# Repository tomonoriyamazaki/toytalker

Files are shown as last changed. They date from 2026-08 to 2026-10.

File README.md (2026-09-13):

# ToyTalker

子供向け音声AIおもちゃ。話しかけると、好きなキャラクターの声で返事をしてくれる。

## 特徴

- **応答約2秒**: STT→LLM→TTSを全区間ストリーミングでつなぎ、最初の音声チャンクが生成され次第再生を開始。サーバーレス（AWS Lambda）構成のまま体感レイテンシを最小化
- **相槌**: メインの応答を生成している間に「そうだね〜」などの短い繋ぎ応答を先に返し、会話のテンポを保つ
- **ボイス・キャラクター切替**: TTSプロバイダーをプラガブルに切替可能（OpenAI / Google / Gemini / ElevenLabs / Cartesia / FishAudio / ずんだもん / 自前クローンボイス）。キャラクターの人格プロンプトもDBで管理
- **スタンドアロン動作**: ESP32-S3搭載の専用基板、おもちゃ単体でWiFi経由でAWSと直接通信（設定ではスマホが必要）

## しくみ
https://github.com/user-attachments/assets/177e0598-6c0a-4d14-9477-36d719003d13

```
[スマホアプリ / ESP32] ── 音声 ──> Soniox STT（直接WebSocket接続）
        │                              │ テキスト
        │                              v
        │<── 音声ストリーム ── Lambda（LLM → TTS ストリーミング）
        │<── 繋ぎ応答 ─────── Lambda（相槌）
```

- STTはLambdaを経由せず、一時キーを使ってクライアントからSonioxへ直接接続（ボトルネック回避）
- LLM→TTSは直列ストリーミングで、生成しながら順次音声化・再生

## デバイスの変遷

| 世代 | 構成 | 状態 |
|---|---|---|
| v1 | Raspberry Pi | 検証完了 |
| v2 | ブレッドボード | 検証完了 |
| v3 | ESP32-S3スタンドアロン（専用PCB） | 開発中 |

## 参加プログラム

- SS Bootcamp 3rd #2025
- TiB FAB makers challenge 2025
- SS Bootcamp 4th #2026

## ドキュメント

- [開発のあゆみ（初期からの検討・試行錯誤の記録）](docs/history.md)
- [マイコン（ESP32）実装](docs/mcu.md)
- [スマホアプリ実装](app/README.md)
- [自前クローンボイス（RTX 5090 / Qwen3-TTS）のバッチ推論](docs/qwen3-tts-batch-engine-2026-09-12.md)
- [原価と課金の考え方](docs/pricing-and-cost-model.md)
- [製品化の認証チェックリスト（STマーク・技適・PSE）](docs/certification-checklist.md)

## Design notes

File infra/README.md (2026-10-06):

# ToyTalker infra（AWS CDK / TypeScript）

ToyTalkerのAWS資源（Lambda 8本・Function URL 7本・DynamoDB 8テーブル・S3・SNS・温めルール・月次Scheduler）を1スタック `ToyTalker-<stage>` で管理する。決定事項と進め方は [docs/multi-account-iac-plan.md](../docs/multi-account-iac-plan.md)。

## 構成

| ファイル | 役割 |
|---|---|
| `bin/toytalker.ts` | 入口。`--context stage=<rnd\|stg\|prod\|prod-dg>` で環境を選び、資格情報のアカウントが一致するか確認し、SSMに秘密が登録済みか確かめてスタックを作る |
| `config/stages.ts` | 環境ごとの秘密でない設定（アカウントID・リージョン・通知先・ZakiCorp URL・S3バケット名・アーキテクチャ） |
| `lib/secrets.ts` | SSM Parameter Store（SecureString）の名前一覧と読み出し。名前は全環境共通 `/toytalker/<key>` |
| `lib/toytalker-stack.ts` | 資源定義。Lambdaは `backend/<dir>/index.mjs` をesbuildでまとめる（旧deploy.shと同じ指定。deploy.shは2026-09-16に削除） |
| `scripts/` | 初回移行用（下記） |

## 使い方

```bash
cd infra
npm ci
bash scripts/install-lambda-deps.sh     # 各Lambdaディレクトリのnpm依存（初回・clone直後）
npx cdk synth  --context stage=rnd      # テンプレート生成（cdk.out/）
npx cdk diff   --context stage=rnd      # 本番との差分。Replace が1つも無いことを確認してから deploy
npx cdk deploy --context stage=rnd
```

別アカウントへ出すときは `AWS_PROFILE=<profile>` か `--profile <profile>` を付ける。設定のアカウントIDと資格情報が違えば起動時に止まる。

## 秘密（SSM）

- 必須: `lib/secrets.ts` の `REQUIRED_SECRETS`（OpenAI・Anthropic・Google・ElevenLabs・FishAudio・Sakura・Cartesia・ZakiCorp API/Edge・Serper・Soniox）
- 任意: OpenAI/Anthropicの管理キー（月次レポートが各社の請求を取るときだけ）
- 1件入れる: `printf '%s' "$VALUE" | npx tsx scripts/put-secret.ts <stage> OPENAI_API_KEY`
- Lambdaは実行時にSSMから読み、メモリに保持する（`backend/shared/secrets.mjs`）。環境変数には鍵を置かず、関数ごとの対象名だけを `SECRET_PARAMS` で渡す。どの関数がどの鍵を読めるかは `lib/toytalker-stack.ts` の `secrets`
- 鍵を入れ替えるときはSSMを変えるだけ。稼働中のLambdaは5分を過ぎた次の呼び出しで取り直す（deploy不要）
- Lambdaに鍵を新しく使わせるとき: `lib/secrets.ts` に名前を足し、その関数の `secrets` に加え、コードでは `secret("名前")` で読む
- 環境変数方式の環境を移すときだけ2段階でdeployする（コードと設定の更新が別々に行われ、その間に鍵が読めなくなるのを避ける）: `npx cdk deploy --context stage=<stage> --context keepEnvSecrets=true` → ログの `[secrets] loaded n/n from SSM` と動作を確認 → フラグ無しで `npx cdk deploy`。新しく作る環境は最初からフラグ無し

## RnDの既存資源をimportで引き取る手順

CloudFormationはimport操作中に新しい資源を作れないので、2段階で行う。

```bash
# 0. 事前準備（各1回）
npx cdk bootstrap aws://342082316736/ap-northeast-1
npx tsx scripts/migrate-secrets-from-lambda.ts rnd   # 2026-10-06に削除済み（Lambda環境変数からSSMへ写すスクリプト。移行は完了）

# 1. import段階: ロール・ポリシー・Lambda Permissionを含まないテンプレートで既存資源を引き取る
npx cdk synth --context stage=rnd --context importPhase=true
npx tsx scripts/make-import-mapping.ts rnd            # import/rnd.generated.json（論理ID→既存資源）
npx cdk import --context stage=rnd --context importPhase=true --resource-mapping import/rnd.generated.json ToyTalker-rnd

# 2. 通常デプロイ: CDK管理の最小権限ロールへ差し替え、Permission・ポリシーを追加、Node 24へ統一
npx cdk diff   --context stage=rnd                     # Replace が無いことを確認
npx cdk deploy --context stage=rnd
```

2段階目のあと、既存のロール `toytalk-lambda-role-dev` と旧Sid（`FunctionURLAllowPublicAccess` 等）は使われなくなるが残る。動作確認後に手で消す。

## マスターデータ

```bash
npx tsx scripts/export-master-data.ts rnd                 # master-data/rnd/*.json（Git対象外）
npx tsx scripts/import-master-data.ts stg --from=rnd --yes
```

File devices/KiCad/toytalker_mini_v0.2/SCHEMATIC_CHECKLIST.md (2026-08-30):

# v0.2 回路図編集チェックリスト(最終版 2026-08-16)

> **このファイルの役割: 「何をやったか」。** Phase 1(回路図)の課題→解決の対応表と作業ログ。**現在の値・ネットの正は PARTS_LIST.md** / GPIOは PINMAP.md

PINMAP.md / PARTS_AND_POWER.md と対応。上から順にやると迷いにくい構成。
編集対象: `toytalker_mini_v0.2.kicad_sch`(v0.1のコピー。バックアップは `toytalker_mini_v0.2_bk/`)

## なぜやるのか — v0.2 課題と解決の全対応表

### A. 音・通信の品質(v0.2の発端)

| # | 課題(v0.1で起きたこと) | 原因 | v0.2の解決 | フェーズ |
|---|---|---|---|---|
| 1 | **会話が途切れる。モジュールを押すと直る**(全個体で再現、[STATS]実測: 途切れ時underruns=6) | ESP32直下のRFグラウンド不足(GNDパッド接続がスポーク1本、直下ビア0個) | GNDソリッド接続+ビアファーム(0.3mm×9〜16)。合格ライン=押さえずにunderruns 0〜1 | **Phase 2(レイアウト)** |
| 2 | アンテナが基板からはみ出し(強度・見た目) | v0.1の設計 | 基板内蔵アンテナ+全層キープアウト(5.5cm版で実績あり) | Phase 2 |
| 3 | WiFiピーク時に電源が窮屈(潜在リスク: 電圧垂れ→音歪み・ブラウンアウト) | LDO 600mAにESP32(WiFiピーク〜500mA)とアンプが同居 | **アンプVDDをV_SYS直結**(データシート裏取り済: VIH=1.3V固定/SD内部100kプルダウン/電源範囲2.5-5.5V) | Phase 1 |

### B. 電源まわりの安全・正しさ

| # | 課題 | 原因 | 解決 | フェーズ |
|---|---|---|---|---|
| 4 | スイッチに定格の50倍の電流(SSAJ110100=10mA定格に実力500mA) | S1が電源経路に直列 | **EN方式化**: S1はAP2112KのENピンへの指示係に(common→PWR_EN、両端→V_SYS/GND、+R9プルダウン)。信号スイッチ化で定格問題消滅 | Phase 1 |
| 5 | 電池コンタクトがハウジングに入りきらない→**金属露出同士で火花(電池短絡、PCM保護頼み)** | 電池リード被覆φ0.93〜1.0(実測)がSHコンタクト上限0.8mmを超過=スペック外圧着。スキル問題ではなかった | **J2をZH化**: S2B-ZR-SM4A-TF + SZH-002T-P0.5(被覆φ1.1まで対応)でスペック内カシメに。工具は手持ちSN-03BM対応 | Phase 1 |
| 6 | 挿し間違いで焼損の可能性(電池⇔スピーカー) | (潜在リスク) | **ポカヨケ**: 電池ZH≠スピーカーMX1.25≠(旧SH)。規格が違い物理的に誤挿入不可 | Phase 1 |

### C. 機能追加

| # | 課題 | 解決 | フェーズ |
|---|---|---|---|
| 7 | **バージイン不可**(再生中に話しかけられない) | I2S分離: マイク=I2S0(GPIO4/5/9)、アンプ=I2S1(GPIO10/11/12)。同時動作の土台 | Phase 1 |
| 8 | 電池残量が分からない | VBAT分圧 R10/R11(470k×2)+C10(0.1µF)→GPIO1(ADC1_CH0、WiFi動作中も測定可) | Phase 1 |
| 9 | 充電中/完了が分からない | BQ25185 STAT1→GPIO13、STAT2→GPIO14(オープンドレインのためR12/R13=100kプルアップ必須) | Phase 1 |
| 16 | 充電時の電池温度保護がない(v0.1はTS機能を固定抵抗で無効化)+本体温度が見えない | **D4**: TS/MRにNTC(TH1)直結でBQのハードウェア充電保護を有効化 / **D5**: 別NTC(TH2)+分圧→GPIO2でファームから温度読取(2026-08-19追加、部品代+約¥10) | Phase 1 |

### D. 組立性・使い勝手

| # | 課題 | 解決 | フェーズ |
|---|---|---|---|
| 10 | スピーカーの付属プラグ(MX1.25)を切ってSHを付け直す無駄工程 | SP1をMX1.25化(HC-1.25-2PWT)→**無加工で挿すだけ**。量産RFQでもMX指定が標準 | Phase 1 |
| 11 | 電源スイッチのノブが極小で筐体連携できない | MSK12C02G15-B(ノブかさ上げ1.5mm、側面操作、蓋側からも対応可)。基板縁に配置 | Phase 1+2 |
| 12 | LEDが眩しい | R8を47Ω→**470Ω**(確定。暗すぎたら手交換/PWM) | Phase 1 |
| 13 | 筐体高さ制約: 内寸9mm=電池3+クッション1+基板1+**部品4mm** | 全選定部品が4mm以下(ZH=3.7/MX=3.57/SW≈3.0)。PH(5.5mm)はこの制約で不採用 | 選定済み |

### E. 設計の衛生(将来の事故防止)

| # | 課題 | 解決 | フェーズ |
|---|---|---|---|
| 14 | GPIO3(JTAGストラップピン)を使用中 | マイクWSをGPIO5へ移動、GPIO3を未接続に | Phase 1 |
| 15 | ネット名の誤記・紛らわしさ(BootボタンがGPIO27表記、「EN」が2つある) | GPIO0_BOOT改名、ESP_EN(ESP32リセット)/PWR_EN(LDO制御)分離、V_SYS_SW廃止 | Phase 1 |

**Phase 1(このチェックリスト)で解決: #3〜12, 14, 15 / Phase 2(レイアウト)で解決: #1, 2, 11の配置**

## 事前準備

- [x] 新部品3種のシンボル+フットプリントを入手
  - S1: **MSK12C02G15-B** (C22435661) — JLCPCB部品ページに EasyEDA Footprint/Symbol あり。位置決めペグ穴Φ0.8×2を含むこと
  - SP1: **HCTL HC-1.25-2PWT** (C2845379) — フットプリントは**HCTL自身のEasyEDAデータ**をKiCad変換して使う(互換品は本家Molexと半田タブ位置が違う場合があるため本家フットプリント流用は不可)
  - J2: **JST ZH S2B-ZR-SM4A-TF** (C265329) — KiCad標準ライブラリ `Connector_JST` にZHあり(フットプリント要確認)。ケーブル側部材の購入: ハウジング**ZHR-2**+コンタクト**SZH-002T-P0.5**(太線用、電池リードφ1.0対応)

## A. ネット名の整理(先にやると後工程が読みやすい)

- [x] A1: S3(Bootボタン)のネット `GPIO27` → **`GPIO0_BOOT`** に改名(実体はGPIO0、v0.1の誤記修正)
- [x] A2: U3のENピンのネット `Net-(U3-EN)` → **`ESP_EN`**(ESP32のリセット。R6/C7はそのまま)
- [x] A3: 新ネット **`PWR_EN`** を作る(B工程で使用。ESP_ENとの混同注意 — 別物!)

## B. 電源セクション(EN方式化 + アンプV_SYS直結)

- [x] B1: S1を電源経路(V_SYS→V_SYS_SW)から切り離す
- [x] B2: U2(AP2112K)の**VINをV_SYSに直結**。C4(22uF)は部品そのまま、ネットをV_SYSに(VIN直近デカップリングとして残す)→ これで `V_SYS_SW` ネットは消滅
- [x] B3: U2の**ENをVINから切り離し、`PWR_EN`ネットに**接続
- [x] B4: S1(新部品)の配線: **common→PWR_EN、片側→V_SYS、反対側→GND**(ON=EN High / OFF=EN Low)
- [x] B5: **R9(100kΩ・新規)** をPWR_EN–GND間に(スイッチ接触不良時にOFF側へ倒す保険)
- [x] B6: U4(MAX98357)の**VDDを+3V3→V_SYSに**。C9(10uF)もV_SYS側(アンプVDD直近)へ
  - ※AMP_SDへの外付けプルダウンは**不要**(SD_MODEに内部100kΩ内蔵、確認済み)

## C. I2S分離 + GPIO変更(U3まわり)

- [x] C1: MK1(マイク)WS: GPIO3 → **GPIO5**
- [x] C2: U4(アンプ)BCLK: GPIO4 → **GPIO10**
- [x] C3: U4 LRC: GPIO3 → **GPIO11**
- [x] C4: U4 DIN: GPIO5 → **GPIO12**
- [x] C5: **GPIO3は未接続に**(JTAGストラップピン解放が目的)
- [x] C6: 変更なし確認: MIC_BCLK=GPIO4 / MIC_DATA=GPIO9 / AMP_SD=GPIO6 / LED=GPIO8 / BUTTON=GPIO7

## D. 新規回路

- [x] D1: 電池残量分圧: **VBAT → R10(470k) → [GPIO1] → R11(470k) → GND**、**C10(0.1µF)** をGPIO1–GND間(ADC1_CH0、WiFi中も測定可)
- [x] D2: 充電ステータス: U1の**STAT1→GPIO13、STAT2→GPIO14**、各々 **R12/R13(100k)** で+3V3へプルアップ(STATはオープンドレインのため必須)
- [x] D3: LED減光: **R8を47Ω→470Ω**(現状27mA→約2.8mA=1/10。眩しすぎてテープで隠している現状から判断。暗すぎたら0603手交換で戻せる。ファームのLEDC PWMでの微調整も可=ハードPWMなのでCPU負荷ほぼゼロ)
- [x] D4: 充電温度保護の有効化: **R5(固定10kΩ)を撤去し、TH1=NCP15XH103F03RC(C77131)をTS/MR–GND間に**。補正抵抗不要(β25/85=3434K≒TI要求3435K、BQ25185データシート§7.3.9で裏取り済み)。高温/低温時にBQがハードウェアだけで充電停止
- [x] D5: 本体温度の可視化: **+3V3 → R14(10kΩ) → [GPIO2] → TH2(NCP15XH103F03RC) → GND**、**C11(0.1µF)** をGPIO2–GND間(ADC1_CH1)。ファームで温度計算しアプリ/[STATS]へ
  - ※TS共用は不可(TSはBQ内部バイアスの私有ノード。モードで電圧が変わり、外部分圧は保護閾値を狂わせる)

## E. 部品差し替え

- [x] E1: S1: SSAJ110100 → **MSK12C02G15-B**(掛かり不足時はG20-Bへ、同一フットプリント)
- [x] E2: SP1: JST SH → **HC-1.25-2PWT**(スピーカー付属のMX1.25プラグが無加工で挿さる)
- [x] E3: J2: JST SH → **JST ZH**(S2B-ZR-SM4A-TF)。電池リード被覆φ0.93〜1.0がSHのスペック外(上限0.8)だったため。ZHのSZH-002Tコンタクト(φ1.1まで)で直接カシメがスペック内に

## F. 検証

- [x] F1: ERC実行 → **ゼロ**に(機械チェック: `kicad-cli sch erc toytalker_mini_v0.2.kicad_sch`)
- [x] F2: PINMAP.md の割当表と突き合わせ(GPIO 1,2,4,5,6,7,8,9,10,11,12,13,14 / 0=BOOT / 3=未接続) — ネットリストで機械検証済み 2026-08-29
- [ ] F3: 完了したらPhase 2(レイアウト)へ。レイアウト側の申し送り: S1は**左辺**配置(ノブ外向き・スマホ式)、J2は**下辺**(28.0,47.0)で口が下向き、その正面の下辺に電池ケーブル用**切り欠き(x25〜31、幅6mm×深さ1.8mm)**。電池は裏返し搭載で赤黒線は右下から出す(RFQ要件)、U3は**90°回転してアンテナを右辺内側へ**(モジュール実寸15.4×20.5mm=アンテナ部5.05mm含む長方形。§10.1 Fig10-1で確認済み。上辺のままだと基板内に収めた時スピーカー円と衝突)、アンテナ帯は全層キープアウト+バッテリーは右帯を避ける、U3直下ビアファーム、**TH1/TH2は基板裏面(電池側)に配置し、TH2はESP32・アンプの自己発熱から離す**

## 参考: 新規部品まとめ(発注BOM追加分)

→ **PARTS_LIST.md に移管**(2026-08-29)。

※J2のケーブル側部材(自分で購入): ハウジングZHR-2、コンタクトSZH-002T-P0.5(太線用)。工具は手持ちSN-03BM対応

変更しない部品・値: R8以外の既存R/C、BQ25185周辺(R3/R4 ※R5は削除しTH1へ)、USB-C周辺、ESP_EN周辺(R6/C7)

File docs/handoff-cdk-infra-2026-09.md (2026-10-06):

# 引き継ぎ: CDK化とRnDの取り込み（2026-09-16作業分、2026-10-06更新）

新しいセッションで複数アカウント展開の続きを始めるための入口。決定の根拠と経過は [複数アカウント計画](multi-account-iac-plan.md)、コードと手順は [infra/README.md](../infra/README.md)。この文書は「今どうなっていて、次に何をするか」だけを持つ。

## 今の状態

- RnDアカウント（342082316736）のToyTalker資源36個は、CloudFormationスタック **`ToyTalker-rnd`** の管理下。ドリフトなし（2026-09-16確認）。
- **Lambdaの反映は `cd infra && npx cdk diff --context stage=rnd` → `npx cdk deploy --context stage=rnd`。** `deploy.sh` / `setup.sh` は削除済み。
- APIキー11件の正本は **SSM Parameter Store `/toytalker/<key>`**（AWS管理キーで暗号化、無料）。**Lambdaが実行時に読んでメモリに保持する**（`backend/shared/secrets.mjs`。2026-10-06に2段階deployで切替、環境変数から鍵を外した。アプリ・ESP32で実機確認済み）。環境変数にはどの鍵を読むかの名前 `SECRET_PARAMS` だけがある。鍵を替えるときはSSMを変えるだけ（5分以内に反映）。手順は infra/README の「秘密」節。
- IAMロールはCDKが関数ごとに作った最小権限のもの（`ToyTalker-rnd-<部品ID>ServiceRole…`）。旧ロールと旧Permissionは削除済み。**`toytalk-lambda-role-dev` だけはv1の旧Lambda 2本が使っているので残している。**
- 動作確認済み: アプリ（会話・読み上げ・設定保存・クローンボイス登録）、ESP32（会話・OTA 0.7.1→0.7.2）。いずれも新ロールで成功。
- Lambda 8本のバンドルは、CDK化前に本番に入っていたコードとバイト単位で一致することを確認した上で引き取った。
- Node 22だった3本はNode 24に統一。ESP32用メインのメモリは2024→2048MB（元の値はタイプミス）。

## 決めたこと（2026-09-16）

- 秘密はSecrets Managerでなく **SSM SecureString**（1件$0.40/月が不要。ローテーション・アカウント間共有を使わないため）。
- 鍵はAWS管理キー。**CMKは本番アカウントで入れる**（SSMとLambda環境変数の両方。DG向け本番で他の人が入る時点で効く。1鍵約$1/月）。RnD/STGはAWS管理キーのまま。
- **秘密の実行時取得へ切り替える** → 2026-10-06に完了。詳細は計画メモの同名の節。
- **命名は環境名を付けて統一する**（案: `toytalker-<env>-chat-app` など。スタック名・部品ID・固定名の3層を一度に変える）。RnDの改名はCloudFront固定ドメインの後、STGは最初から新名。詳細は計画メモの「命名の見直し」。
- ファーム配布バケット `toytalker-firmware` はCDKの管理外（`fromBucketName` で参照のみ）。名前は `stages.ts` の `firmwareBucketName`。

## 次にやること（順序の案）

1. ~~秘密の実行時取得~~（2026-10-06完了）
2. **命名の決定**（計画メモの案を確定。テーブルのキー名を変えるならここで）
3. **STGアカウント作成 → `cdk bootstrap` → SSM投入 → `cdk deploy` → マスターデータ投入**（`stages.ts` の `account` を埋める。投入スクリプトは infra/scripts）
4. **CloudFront固定ドメイン**（`api-stg.zakicorp.com` 等。アプリとESP32の接続先切替）
5. RnDの改名（4の後）→ **自分用本番**（CMK込み）→ **DG向け本番**。本番が2つになったらGitHub Actions + OIDC

判断待ち・別機会:

- v1の残骸を消すか: `toytalk-lambda-role-dev`、`toytalk-openai-api-dev`、`toytalk-api-raspi`、API Gateway `toytalk-chat-apigateway-dev`、孤立ロググループ `/aws/lambda/toytalk-stream-handler-for-esp32-lambda`
- Windows機で: `infra/` の動作確認は済（2026-09-29、Node v22.19.0・Git Bash。`npm ci`、`install-lambda-deps.sh`、型チェック、`cdk diff --context stage=rnd` が差分なし。deployは未実行）。`supervisor.py` の `ZAKICORP_TTS_URL` 同期停止はコード修正済みで、このPCの `.local/tts-service/` への反映が未実施
- `toytalker-firmware` を1資源だけ `cdk import` で引き取るか
- Soniox鍵発行Lambda（128MB）はコールドスタート時のSSM取得に約0.9秒かかる（他は1〜2GBで約0.2秒）。温めで普段は起きないが、気になるなら256MBへ

## 落とし穴

- **`cdk synth`/`diff`/`deploy` にはAWS資格情報が要る**（SSMの登録の有無を確かめるため。値は読まない）。起動時にアカウントIDが `stages.ts` と一致しないと止まる。
- **`NodejsFunction` は使っていない。** `npx esbuild` をリポジトリ直下で起動してインストール確認待ちで止まるため、esbuildのAPIを直接呼ぶ `bundleLambda` を使っている。
- 各Lambdaディレクトリの `node_modules` が無いとバンドルできない。clone直後は `bash infra/scripts/install-lambda-deps.sh`。
- 名前を固定した資源（Lambda・テーブル・S3）の名前や部品IDを変えると作り直しになる。`cdk diff` の requires replacement を必ず見る。Lambdaの作り直しはFunction URLのホスト名が変わり、アプリとESP32が壊れる。
- 新しいCloudFormation資源を既存スタックに `cdk import` するときは、import操作にそれ以外の変更を含められない（`--context importPhase=true` の仕組みは infra/README）。

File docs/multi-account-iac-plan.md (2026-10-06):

# 複数アカウント展開とIaC化の計画（2026-09-15決定）

今のAWSアカウントをRnDにし、STG → 自分用本番 → DG（西川さん）向け本番へ展開するための計画。道具はAWS CDK（TypeScript）。着手したら本文の「進め方」を進捗に合わせて上書きし、決定の根拠はこの文書に残す。

## 決定事項

| 項目 | 決定 | 根拠 |
|---|---|---|
| IaCの道具 | AWS CDK（TypeScript） | Lambda 8本がNode.js ESM + esbuildで、`NodejsFunction` がdeploy.shを丸ごと置き換える。ストリーミングFunction URLは `invokeMode: RESPONSE_STREAM` の1行。アプリもTS系で言語が増えない |
| CloudFormation | CDKの裏で使い続ける | CDKはTSをCloudFormationテンプレートに変換して流す。YAMLは書かない。マネコンのCloudFormation画面はスタックの閲覧・ロールバック用に使う |
| 今のアカウント | RnDとして残し、ToyTalkerの資源はCDK管理に引き取る（2026-09-15に変更） | 当初は手作業のまま残す予定だったが、RnDを見ながらCDKを書き、当てて差分が消えるまで直せる方が確実。テーブルにはデータが入っているので作り直さず `cdk import` で引き取る。ToyTalker以外の資源はCDKの管理外のまま |
| 環境 | RnD（現行）→ STG → 自分用本番 → DG向け本番 | Organizationsで分け、ログインはIAM Identity Center。アカウントごとのアクセスキーは作らない |
| 資源の名前 | テーブル名・Lambda名は `toytalker-*` の固定名を全環境で維持。S3バケットだけ環境名を付ける | アカウントが別なら同じ名前でぶつからない。RnDの既存資源をimportで引き取るには名前の一致が必要。S3は全世界で一意なので `toytalker-tts-speakers-<stage>` |
| 環境ごとの設定 | `infra/config/stages.ts` の1ファイルに環境ごとの塊を並べ、`cdk deploy --context stage=<env>` で選ぶ | アカウントID・リージョン・APIの固定ドメイン・通知メール・ZakiCorp URL・メモリなど。秘密ではないのでGitに入れる |
| 秘密の値 | アカウントごとのSSM Parameter Store（SecureString）。名前は全環境で同じ（例 `/toytalker/openai-api-key`）、中身だけ違う | CDKは名前しか持たず、秘密がファイルに載らない。中身は初回にアカウントごとに手で入れる（投入スクリプト可）。CDKがデプロイ時に読んでLambda環境変数に焼くので、鍵を入れ替えたら `cdk deploy` し直す |
| CDKが決める値 | Function URLのホスト名など、生成結果の値はファイルに書かない | CDKコード内で「このLambdaのURLをあのLambdaの環境変数へ」と配線する。人が見るのはデプロイ後の出力 |
| デプロイ経路 | 当面ローカルから `cdk deploy --profile <env>` | GitHub Actions + OIDCは本番が2つになってから |
| Lambda起動の高速化 | 今はやらない | 温め設計が効いている（下記） |
| Terraform | 見送り | AWS単独ならCDKの方が学ぶことが少ない。Cloudflare側（DNS・WAF・Tunnel）もコード化したくなったら再検討 |

## 現状の棚卸し（2026-09-15、RnDアカウント）

CDKで再現する対象。

- Lambda 8本（Node 22と24が混在、x86_64）。メイン2本は2048MB、相槌1024MB、デバイス設定256MB
- Lambda Function URL 7本（RESPONSE_STREAM 4本: App用メイン・ESP32用メイン・App用相槌・読み上げ。BUFFERED 3本: ESP32用相槌・Soniox鍵発行・デバイス設定）。API Gateway `toytalk-chat-apigateway-dev` はv1（Raspberry Pi）時代の旧Lambda向けで現行8本とは無関係。CDKの対象外
- DynamoDB 8テーブル、S3 `toytalker-tts-speakers`、SNS `toytalker-ops-monthly`、EventBridge Scheduler `toytalker-ops-monthly`
- EventBridgeルール `toytalker-lambda-warmer`（5分ごと、メイン2本・相槌2本・Soniox鍵発行の5本へ `{"warmup":true}`）
- 実行ロールは2つ。7本が共有する `toytalk-lambda-role-dev`（DynamoDB/S3/Lambda FullAccess等の広い管理ポリシー）と、月次レポート用 `toytalker-ops-monthly-role`（最小権限のインライン）。環境変数はLambda全体で22種類、APIキー類がここに直接入っている
- 温めルールは `AWS::Lambda::Permission`（Sid `toytalker-warmer`）で5本に付いている。Function URLの公開許可は新しい4本には `InvokeFunctionUrl` と `InvokeFunction`（`InvokedViaFunctionUrl` 条件）の2つ、古い3本には前者だけ
- Function URLのホスト名がアプリとESP32ファームにハードコードされている
- ZakiCorp TTSの監視タスク（`tools/tts-service/supervisor.py`）がLambda 6本の `ZAKICORP_TTS_URL` を関数名指定で同期している

## 進め方

RnDでCDKを完成させてから、同じコードをSTG・本番にまっさらに出す。RnDへの `cdk deploy` はSTGができるまで本番デプロイと同じ扱いで、毎回 `cdk diff` で置き換え（Replace）が1つも出ないことを確認してから流す。コードは [infra/](../infra/README.md)。

1. **済（2026-09-16）RnDの現状をAWS CLIで読み出した。** 上の棚卸しに反映。CloudFormationで全種類がimport可能なことも `get-template-summary` で確認した（Lambda::Url・Events::Rule・Scheduler::Schedule・SNS::Subscription・Logs::LogGroup を含む）。
2. **済 CDKの骨組み。** `infra/` に1スタック `ToyTalker-<stage>`。Lambdaはesbuild APIで直接バンドルし、8本とも本番に入っているコードとバイト単位で一致することを確認した（`aws lambda get-function` で取得して比較）。温めルール・自分へのping・Scheduler・SNS購読を含む。ランタイムはNode 24で統一（`LAMBDA_RUNTIME` 1か所）。
   - `NodejsFunction` は使わない。`npx esbuild` をリポジトリ直下で起動してインストール確認待ちで止まるため（esbuildは `infra/` にしか無い）。
3. **済（コードのみ、SSMへの投入は未実行）環境設定ファイルとSSMの名前。** `infra/config/stages.ts` と `infra/lib/secrets.ts`。RnDのLambda環境変数からSSMへ写すスクリプトは `infra/scripts/migrate-secrets-from-lambda.ts`。（`--context secretsSource=lambda` は2026-10-06の実行時取得への切替で廃止）。
4. **済（2026-09-16 05:00 JST）RnDの既存資源を `cdk import` で引き取った。** 手順は [infra/README.md](../infra/README.md)。`cdk bootstrap` → SSMへ11件投入（`migrate-secrets-from-lambda.ts`）→ `--context importPhase=true` のテンプレート（36資源）で `cdk import`。import前後でLambda 8本の設定・コードハッシュ・環境変数が同一であることを確認した（更新日時だけCloudFormationのタグ付けで変わる）。IAMロールはimportせず、次のdeployでCDK管理の最小権限ロール（関数ごと、使うテーブルだけ）へ差し替えた。
5. **済（同日 05:16 JST）初回 `cdk deploy` でドリフトなし。** Replaceなし。変わったもの: ロール9つ新設と差し替え、Node 22→24（3本）、ESP32用メインのメモリ 2024→2048、Function URL公開許可と温めルールのPermission追加（旧Sidは残る）。deploy直後に実機からの会話1件がDynamoDB・LLM・検索・TTSまで新ロールで成功。ドリフト検出は IN_SYNC。**ここでdeploy.shの役目が終わった。以後RnDへの反映は `cdk deploy --context stage=rnd`。**
   - 同日06:24 JST、ESP32 OTA（main b18c70d）に合わせて2回目のdeploy: Soniox鍵発行Lambdaのタイムアウト3→5、`toytalker-devices` 書き込み、ファーム配布バケット `toytalker-firmware`（手作業で作成、CDKは `fromBucketName` で参照のみ。名前は `stages.ts` の `firmwareBucketName`）の読み取り、環境変数 `FIRMWARE_BUCKET`。デバイス設定Lambdaもmainの版へ。
   - 同日、アプリ（会話・読み上げ・設定保存・クローンボイス登録）とESP32（会話・OTA）の確認後に後片付け: 旧ロール `toytalker-ops-monthly-role` `toytalker-ops-monthly-scheduler-role` と旧Permission（Sid `FunctionURLAllowPublicAccess` `FunctionURLAllowInvokeAction` `toytalker-warmer`）を削除。**`toytalk-lambda-role-dev` は残した**（v1の旧Lambda `toytalk-openai-api-dev` `toytalk-api-raspi` がまだ使っている。API Gateway `toytalk-chat-apigateway-dev` ともども、消すなら別途判断）。
6. **済（スクリプトのみ）マスターデータの投入スクリプト。** `infra/scripts/export-master-data.ts` / `import-master-data.ts`。出力先 `infra/master-data/` はGit対象外（人格プロンプトを含む）。
7. **STGアカウントを作って `cdk bootstrap` → `cdk deploy`。** `stages.ts` の `account` を埋め、SSMに鍵を入れ、マスターデータを投入し、アプリとESP32の接続先をSTGへ向けて実機確認。
8. **エンドポイントの固定名化。** Function URLはアカウントごとにホスト名が変わるので、CloudFrontを前段に置いて `api-stg.zakicorp.com` のような固定名にする（ストリーミングはCloudFront経由でも通る）。アプリは `eas.json` のビルドプロファイルで、ESP32はビルドフラグで接続先を切り替える。現在のハードコード箇所: `app/app/(tabs)/chat.tsx`・`settings.tsx`・`toy.tsx`・`app/components/ReadAloud.tsx`、ESP32は各版の `.ino`。
9. **済（コードのみ、このPCへの反映は未実施）ZakiCorp TTSのURL同期を止める。** 固定URLのときは照合と警告だけにし、書き込みはngrok経路に限った。 公開URLが `https://tts.zakicorp.com` で固定になったので `stages.ts` の値にした。`tools/tts-service/supervisor.py` の同期はimport後に不要になる（CDKがdeployのたびに環境変数を上書きするので、同期を残すと互いに書き合う）。
10. STGで一通り動いたら、同じスタックを自分用本番、DG向け本番の順に出す。
11. 本番が2つになったらGitHub Actions + OIDC（アカウントごとにOIDC用ロール1つ。権限はCDKのロール群を借りるだけ。これもCDKで書く）。

### 決めたこと（実装中に追加）

- リポジトリは公開。`stages.ts` に載るアカウントIDと通知先メールは秘密ではなく、メールは既に `docs/tts-boot-recovery.md` にもある。
- スタックは `terminationProtection: true`、テーブルとS3は `RemovalPolicy.RETAIN`、テーブルは削除保護ON。
- ロググループもCDK管理（保持期間は現状どおり無期限。変えるなら `stages.ts` に足す）。
- `cdk.json` は `versionReporting: false`（`AWS::CDK::Metadata` を出さない。import時に余計な資源を作らないため）。

## 秘密の実行時取得（2026-09-16合意、2026-10-06実装・RnD切替済み）

「CDKがdeploy時にSSMを読み、Lambda環境変数に焼く」方式から、「Lambdaが初期化時にSSMを読み、メモリに保持する」方式へ変えた。実装は `backend/shared/secrets.mjs` と `infra/lib/toytalker-stack.ts` の `secrets`、手順は infra/README の「秘密」節。計画と違えた点: 切替時にコード更新と設定更新の間で鍵が読めなくなるのを避けるため、`--context keepEnvSecrets=true` で環境変数にも残す1段目を挟む2段階deployにした（`secret()` は環境変数へフォールバックする）。以下は合意時の計画。

- 理由: 環境変数はLambdaの設定を読める人に平文で見え、CDKがS3に上げるテンプレートにも入る。実行時取得なら鍵は関数のメモリにしかなく、読めるのはその関数のロールだけ。鍵の差し替えもSSMを変えるだけでdeploy不要になる。
- 速度: 初期化（コールドスタート）に `GetParameters` 1〜2回分（30〜60ms）が足される。2回目以降は保持した値を使うので環境変数と同じ。温めで初期化はほぼ起きない（週1〜5回）ので体感差なし。
- やり方: 共通モジュール1つを8本に入れ、初期化時に10件ずつ並列取得、5分以上経ったら裏で取り直す。CDKは環境変数から鍵を外し、ロールに `ssm:GetParameters` を足す。AWS管理キーの復号はSSM経由で自動的に許可される。AWS公式の Parameters and Secrets Lambda Extension はレイヤー追加とHTTP呼び出しへの書き換えが要るので使わない。
- 時期: STGを作る前。8本のコードに手が入るので実機試験が要る。先にやればSTGは最初から環境変数に鍵の無い状態で立ち上がる。
- 秘密でない設定（`ZAKICORP_TTS_URL`・`CARTESIA_DEFAULT_VOICE_ID`・`SONIOX_MODEL`・`FIRMWARE_BUCKET`・`OPS_SNS_TOPIC_ARN`）は環境変数のまま。

## 命名の見直し（2026-09-16、未決定）

今の名前は `toytalk-`/`toytalker-` が混在し、環境名が無い。計画では「固定名を全環境で維持」としたが、環境名を付ける方向で見直したい（コンソールやログで環境が一目で分かる。S3は既に環境名が必須）。案は接頭辞 `toytalker-<env>-`、envは `rnd` / `stg` / `prd` / `prd-dg`（例: `toytalker-stg-devices`、`toytalker-stg-stream-handler`）。

### 名前の案（2026-09-16）

- 形は `toytalker-<env>-<機能>-<相手>`。環境名を前に置くと一覧が環境ごとに固まり、IAMで `toytalker-stg-*` の前方一致が書ける。
- `-lambda` `-table` のような種類は付けない（コンソールもログの `/aws/lambda/…` も種類を示す）。
- 相手は `app`（スマホ）と `mcu`（ESP32。`devices/mcu/` に合わせ、基板が変わっても持つ名前）。両方から使うものは付けない。

| 今 | 案 | 中身 |
|---|---|---|
| `toytalk-stream-handler-lambda` | `toytalker-<env>-chat-app` | App用メイン（LLM+TTS） |
| `toytalk-api-stream-for-esp32-lambda` | `toytalker-<env>-chat-mcu` | ESP32用メイン |
| `toytalker-backchannel-for-app-lambda` | `toytalker-<env>-backchannel-app` | App用相槌 |
| `toytalker-backchannel-for-esp32-lambda` | `toytalker-<env>-backchannel-mcu` | ESP32用相槌 |
| `toytalk-soniox-stt-lambda` | `toytalker-<env>-stt-token` | Soniox一時キー発行（両方から使う） |
| `toytalker-device-setting-lambda` | `toytalker-<env>-settings-app` | デバイス登録・ボイス設定・コスト（「デバイス設定」より広い） |
| `toytalker-tts-only-lambda` | `toytalker-<env>-read-aloud-app` | 読み上げ。実装（TTSのみ）より機能名 |
| `toytalker-ops-monthly-lambda` | `toytalker-<env>-ops-monthly` | 月次レポート |

テーブルは `toytalker-<env>-devices` のように接頭辞を替えるだけ。S3は `toytalker-<env>-tts-speakers`。ロググループは関数名に追従。

### 名前は3層あり、一度に変える

| 層 | 今 | 決めているもの |
|---|---|---|
| スタック名 | `ToyTalker-rnd` | IAMロール名の先頭、CloudFormationの一覧 |
| 部品ID（CDKコード内の名前） | `StreamHandler`、`DevicesTable` など | ロール名の中身、CloudFormationの論理ID |
| 資源の固定名 | `toytalk-stream-handler-lambda`、`toytalker-devices` など | 実際のLambda名・テーブル名。アプリやコードが参照するのはこれ |

IAMロールはCDKが名前を付けている（例 `ToyTalker-rnd-OpsMonthlyServiceRoleDC20ED87-UWLuVIYTH2C7`）ので、環境の区別はスタック名で既についている。固定名は付けない。

部品IDを変えると、その資源はCloudFormation上で別物になり作り直しになる（テーブルも同じ）。固定名を変える時点で作り直しは避けられないので、スタック名（`toytalker-<env>` に小文字で揃える）・部品ID（`StreamHandler` → `ChatApp` など）・固定名は同時に変え、作り直しを1回で済ませる。

### 名前を変えたときに起きること

CDKで固定名を変えると、その資源は「作り直し（Replace）」になる。`cdk diff` に requires replacement と出る。古い資源は RETAIN にしてあるので消えずに残る。

| 資源 | 影響 |
|---|---|
| IAMロール | CDKが名前を付けるので変える場面がない。作り直しても実害なし |
| Lambda関数名 | **Function URLのホスト名が変わる。** アプリとESP32の接続先を配り直す必要がある。ロググループ名、`supervisor.py` の関数名一覧、月次レポートのログ検索対象も追従 |
| DynamoDBテーブル名 | 新テーブルは空。マスター4テーブルは `export/import-master-data.ts` で移せる。会話ログ・利用量は件数が多い |
| DynamoDBキー名 | テーブル名変更に加えて、データの詰め替えとLambdaコードの書き換えが要る。一番重い。変えるならSTGを作る前に決める |
| S3バケット名 | `aws s3 sync` で写すだけ（34オブジェクト） |
| SNS・温めルール・Scheduler | 影響なし。メール購読は再確認メールが届く |

### 進め方の案

1. **Lambdaコードがテーブル名を環境変数から組み立てるように直す**（例: `TABLE_PREFIX`）。名前はまだ変えない。CDKが環境変数を配るので、名前を知っているのは `stages.ts` だけになる。ここは無リスク。
2. **STGは最初から新しい名前で作る。** まっさらなので追加の手間はない。
3. **RnDは、CloudFrontの固定ドメイン（進め方8）の後に改名する。** 配布済みの実機があるので、Function URLのホスト名が変わっても困らない状態にしてから。接頭辞の統一と環境名の付与は1回で済ませる。

## CDK化のついでに入れるもの

- **arm64**: 料金2割減。速度はネットワーク待ちが支配的なので変わらない。純粋なJSなので書き換え不要、実機確認は要る。
- **AWS SDKのtree-shaking同梱**: 今は `--external:@aws-sdk/*` でランタイム同梱SDKを数千ファイルから読んでいる。使う分だけを1ファイルに同梱すれば初期化が数十ms縮む。tree-shakingとminifyを効かせないと逆に遅くなる。やるなら `backend/package.json` を作って `@aws-sdk/*` を `backend/node_modules` に置き（各Lambdaの `openai` 版違いはそのまま）、`bundleLambda` の `external` を空にして `minify: true`。import直後はやらず、diffが空になってから別コミットで。

## CDKの前提知識（初回作業時の確認用）

- `cdk bootstrap` をアカウント（×リージョン）ごとに1回実行すると、CDK用のロール一式（CloudFormation実行・デプロイ・ファイル公開・参照）とS3バケット1つができる。S3が要るのはCloudFormationがzipの中身を受け取れず「S3のどこにあるか」しか受け付けないため。
- `cdk diff` で変更対象を事前に確認できる。Lambda 1本だけ直して `cdk deploy` しても、コードのハッシュが変わった関数だけ更新される。`--hotswap` はCloudFormationを通さず直接差し替える開発用で、本番では使わない。
- ランタイム版は `lambda.Runtime.NODEJS_24_X` のような定数で指定する。共通定数にしておけばEOL時は1か所の変更で全関数に反映される。

## 調査記録: Lambdaコールドスタート（2026-09-15）

直近7日のCloudWatch Logsを、温めping（アプリログ無し、START/END/REPORTの3行）と実リクエストに分けて集計した。

| 関数 | 呼び出し | コールドスタート | うち実リクエスト | 初期化平均 |
|---|---|---|---|---|
| App用メイン | 2204 | 124 | 1 | 408ms |
| ESP32用メイン | 3346 | 160 | 5（判別しにくいもの11） | 418ms |
| 相槌(ESP32) | 2834 | 105 | 4 | 363ms |

コールドスタートの大半は予備インスタンス温めが意図通り新しいインスタンスを起こしているもので、ユーザーに当たる初期化待ちはほぼゼロ。温めは常時1台と予備1台なので、3人以上の同時利用で3人目からはコールドを踏むが、今の規模では問題になっていない。初期化400msの内訳は推定で `openai` パッケージの読み込みが大半、次にランタイム同梱SDKの読み込み。ユーザーが感じるコールドスタートにはこの他にログに出ないサンドボックス生成の100〜200msが乗り、そこは手が出せない。

却下した高速化案と理由は [先送り項目](deferred-items.md) の「Lambda初期化の短縮」。

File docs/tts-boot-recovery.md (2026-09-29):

# ログオン不要のTTS起動・復旧

## 目的と構成

PC再起動後、人がログオンする前にクローン音声を復旧させる。Windows更新の設定はこの作業では変更しない。

管理対象は既存の `C:\Users\exodj\projects\tts-models\faster-qwen3-tts\api_server.py` とngrok。アプリのリトライ修正とは独立している。

- 実装: `tools/tts-service/supervisor.py`
- 登録: `tools/tts-service/install.ps1`（管理者PowerShell）。タスクを登録し直すとき専用（PC入れ替え、タスクの破損、旧 `setup-tasks.ps1` の誤実行後、タスク設定の変更）。日常の切り替えは `switch-api.ps1`。既存の `config.json` があれば `api_script`・`public_url` などを引き継ぐ（2026-09-29。それ以前は毎回作り直し、固定URLとバッチ版の指定が消えた）。`-ShowConfig` で、何も変えずに書き込まれる設定を表示する。
- 配置先: `.local/tts-service/`（Git対象外）。登録時にスクリプトのコピーを配置するため、ブランチ切替だけで実行中のサービスは変わらない。改修適用は保守時間にタスクを停止してから再登録する。稼働中の上書き登録はインストーラーが拒否する。
- 実行アカウント: 既存TTSタスクのユーザー、S4U・通常権限。パスワード保存なしの非対話実行。Windows認証を必要とするネットワーク共有やEFSには依存させない。CUDAと実際のHTTPS/API接続は事前プローブで検証する。
- 起動: OS起動30秒後、実行時間の上限なし。監視スクリプト自体が異常終了した場合は1分後に再試行（タスク設定の上限999回）。

監視は15秒間隔。既存のAPI/ngrokプロセスを引き継ぎ、二重起動を避ける。APIは実行ファイル・引数・作業ディレクトリを照合する。プロセス終了後は30秒待って再起動する。自分が起動したプロセスについて、ヘルスチェックが10分間連続で失敗した場合にも再起動する。引き継いだ既存プロセスはヘルス失敗だけでは停止しない。

`/health`は現行APIの起動処理（モデルロード・ウォームアップ）後に応答する。公開URLの`/health`も確認してから、6つのLambda（`supervisor.py` の `FUNCTIONS`）のURLを照合する。固定URL（`public_url` 設定時）は照合と警告だけで書き込まない（正本はCDK）。ngrok経路ではURL変更時のみ更新し、他の環境変数を保持し、RevisionIdによって同時変更の上書きを防ぐ。通信不通なら次の監視周期で再試行する。音声生成自体の継続的な成功まではヘルスチェックだけでは保証しない。

認証情報は従来の `.env`、AWSプロファイル、ngrok設定を参照し、Gitへコピーしない。APIキーが空の場合は起動を拒否する。ログは `.local/tts-service/logs/` に保存する。APIログには会話関連情報が含まれる可能性があるため共有前に確認する。現段階ではログの自動世代管理は未実装。

## 適用と確認

管理者PowerShellでリポジトリルートから実行:

```powershell
powershell.exe -NoProfile -ExecutionPolicy Bypass -File .\tools\tts-service\install.ps1 -ProbeOnly
Get-ScheduledTaskInfo -TaskName TTS-BootProbe
Get-Content .\.local\tts-service\logs\probe.log
```

先に `install.ps1 -ShowConfig` で、書き込まれる設定（`api_script` と `public_url`）が今の構成どおりか確認する。プローブは既存TTSを停止せず、非対話タスク内でCUDA割当、設定読込、ローカル・公開ヘルス、AWS Lambda設定の読み取りを確認する。`LastTaskResult=0`と`PROBE PASSED`を確認した後に適用:

```powershell
powershell.exe -NoProfile -ExecutionPolicy Bypass -File .\tools\tts-service\install.ps1
Get-ScheduledTask -TaskName TTS-AutoStart
Get-Content .\.local\tts-service\logs\supervisor.log -Tail 20
```

元タスクのXMLは `.local/tts-service/TTS-AutoStart.before.xml` に初回のみ保存する。インストーラーはWindows更新タスク・レジストリ・元のTTSリポジトリを変更しない。旧 `setup-tasks.ps1` を再実行するとログオン起動へ戻るため注意する。

完了判定には、非対話タスクでの動作確認に加えて、作業保存後にPCを再起動し、ログオンせずスマホでクローン音声の応答を確認する。再起動はこのインストーラーでは実行しない。API/ngrok終了からの復旧の実機試験は音声利用を中断するため、利用していない時間に行う。

## 公開経路: Cloudflare Tunnel（2026-09-13切替）

本番TTSの公開URLは **`https://tts.zakicorp.com`**（固定）。Lambda 6本の `ZAKICORP_TTS_URL` はこの値で、正本は `infra/config/stages.ts` の `zakicorpTtsUrl`（CDKがdeployのたびに配る）。監視タスクは `config.json` の `public_url` と照合するだけで、書き換えない（違えばログに警告）。URLを変えるときは `stages.ts` と `config.json` の両方を直す。`public_url` が設定されている間、監視タスクはngrokを起動しない（2026-09-13 18:02に撤去。起動していれば停止する）。`public_url` を空にするとngrokを再び起動して予備経路に戻る。

| 項目 | 値・場所 |
|---|---|
| Cloudflareアカウント / ゾーン | exodjp@gmail.com のアカウント、ゾーン `zakicorp.com`（無料プラン。ネームサーバーは `ariadne.ns.cloudflare.com` / `tate.ns.cloudflare.com`、2026-09-13にRoute 53から移行。登録先はお名前.com） |
| トンネル | 名前 `toytalker-tts`、ID `8bc0e7f0-7f28-409a-bb05-ea1d9c0c9d7c`（locally-managed） |
| DNS | `tts` → `8bc0e7f0-….cfargotunnel.com` のCNAME（`cloudflared tunnel route dns` で自動作成、プロキシON）。ほかに `toytalk` → CloudFront（DNS only）とACM検証用CNAME（DNS only）をRoute 53から移した |
| 設定ファイル | `C:\Users\exodj\.cloudflared\config.yml`（ingress: `tts.zakicorp.com` → `http://localhost:8000`、それ以外は404） |
| 認証情報（Git対象外、秘密） | `C:\Users\exodj\.cloudflared\cert.pem`（`cloudflared tunnel login` で取得）、`C:\Users\exodj\.cloudflared\8bc0e7f0-….json`（トンネル資格情報）。同じ3ファイルの複製が `C:\Windows\System32\config\systemprofile\.cloudflared\` にもある |
| 常駐 | Windowsサービス `cloudflared`（自動起動、LocalSystem）。`service install` は `--config` を保存しないため、`tools/tts-service/cloudflared-service-fix.ps1`（管理者）でImagePathに `--config` と `--logfile` を明示している |
| ログ | `.local/tts-service/logs/cloudflared-service.log`（サービス）、`cloudflared.log`（手動実行時） |
| 監視 | `supervisor.py` は `public_url` があればその `/health` を確認し、Lambdaの値は照合のみ行う（書き込みはngrok経路のときだけ）。Cloudflareは `Python-urllib` のUser-Agentを403で弾くため、監視は `toytalker-supervisor/1.0` を名乗る |

### 正常確認

```powershell
Get-Service cloudflared
Invoke-RestMethod https://tts.zakicorp.com/health -TimeoutSec 10
& 'C:\Program Files (x86)\cloudflared\cloudflared.exe' tunnel info toytalker-tts
Get-Content .\.local\tts-service\logs\cloudflared-service.log -Tail 5
```

`tunnel info` で東京拠点（nrt〜）へ3〜4本の接続があれば正常。切替時の実測は [バッチエンジン記録](qwen3-tts-batch-engine-2026-09-12.md) 参照（ngrokと同等、同時32件まで枯渇0）。

### 復旧

- サービスが止まった: 管理者PowerShellで `Start-Service cloudflared`。起動直後に落ちる場合は `cloudflared-service-fix.ps1` を再実行（ImagePathの引数が消えた場合の対処）。
- PC再起動後: サービスは自動起動。監視タスクとは独立。
- トンネルを作り直す: `cloudflared tunnel login`（ブラウザで承認）→ `tunnel create <名前>` → `config.yml` の `tunnel`/`credentials-file` を新IDに → `tunnel route dns <名前> tts.zakicorp.com` → `cloudflared-service-fix.ps1`。
- **ngrokへ戻す**: 管理者PowerShellで `switch-api.ps1 -ApiScript api_server_batch.py -PublicUrl ''`。`public_url` が空になると監視タスクがngrokを起動し、そのURLをLambda 6本へ同期する（次の `cdk deploy` で `stages.ts` の値に戻るので、ngrok運用中はdeployしないか `stages.ts` も直す。約1〜2分。ngrokの認証設定 `ngrok.yml` は残してある）。Cloudflareへ戻すときは `-PublicUrl 'https://tts.zakicorp.com'`。

### 拠点での遮断: 合言葉ヘッダー（2026-09-13 17:30ごろ有効化）

Cloudflareの WAF カスタムルール `tts-edge-key-required`（Security → Security rules）が、`tts.zakicorp.com` 宛てで `X-Zakicorp-Edge-Key` ヘッダーが正しい値でない要求を拠点で **Block** する。期限なし。値の置き場所は次の2か所＋サーバー側 `.env`（値はここに書かない）。

| 置き場所 | 名前 |
|---|---|
| Lambda 6本（デバイス設定Lambdaを含む）の環境変数 | `ZAKICORP_EDGE_KEY`（ZakiCorp呼び出しのヘッダーに付ける。未設定なら送らない） |
| Cloudflareのルール式 | `not any(http.request.headers["x-zakicorp-edge-key"][*] eq "<値>")` |
| `tts-models/faster-qwen3-tts/scripts/.env` | `ZAKICORP_EDGE_KEY`（監視タスクの公開health確認と負荷試験クライアント `run.py` が読む） |

確認: ヘッダー無し／誤りは403、正しい値は200、`toytalk.zakicorp.com` は無関係（ルールは `http.host eq "tts.zakicorp.com"` に限定）。入れ替えは「ルールを旧か新のどちらかなら通すに変更 → Lambda 6本と `.env` を新値に → ルールを新だけに戻す」の順で無停止。Accessのサービストークンは期限があるため採用していない。

公開側 `/health` は `{"status":"ok"}` のみ返す（Cloudflare経由か非ローカルの要求）。話者登録名は `[A-Za-z0-9_-]{1,80}` に限定し既存名は409。

### 後始末（完了）

Route 53の `zakicorp.com` ホストゾーンは2026-09-13にユーザーが削除した（DNSはCloudflareのみ。`zackey.xyz` のゾーンはRoute 53に残る）。ドメイン登録そのものはお名前.comのまま。

## APIの版の切り替え（元の `api_server.py` とバッチ版 `api_server_batch.py`）

2026-09-13追加。`config.json` の `api_script`（省略時 `api_server.py`）で監視が起動するAPIを選ぶ。`supervisor.py` はこの値を起動コマンドと既存プロセスの照合の両方に使う。`install.ps1 -ApiScript api_server_batch.py` で登録時に指定することもできる（指定しなければ既存の `config.json` の値を引き継ぐ）。

登録し直さずに切り替えるには、管理者PowerShellでリポジトリルートから:

```powershell
powershell.exe -NoProfile -ExecutionPolicy Bypass -File .\tools\tts-service\switch-api.ps1 -ApiScript api_server_batch.py
```

処理内容: `.local` の `config.json`・`supervisor.py` を日時付きで退避 → タスクを無効化・停止 → 8000番で待ち受けているAPIプロセスを停止 → `supervisor.py` を配置し `api_script` を設定 → タスクを有効化・起動 → ローカルhealth（最大240秒）→ ngrok公開healthを確認。ngrokは停止しないので公開URLは変わらず、Lambdaの更新は起きない。音声は停止からhealth復帰までの約40秒間止まる。

復旧は同じスクリプトを `-ApiScript api_server.py` で実行する。バッチ版の詳細は [実装と検証](qwen3-tts-batch-engine-2026-09-12.md)。切り替え後は `Invoke-RestMethod http://127.0.0.1:8000/health` の応答に `engine` があればバッチ版。

バッチ版の同時上限は `tts-models/faster-qwen3-tts/scripts/.env` の `TTS_BATCH_CLASSES` で決まる（監視タスクが `.env` を環境変数としてAPIに渡す）。2026-09-13夜から `1,2,4,8,16`（同時16件、待機VRAM約11GiB、他のGPU用途と同居するため）。`1,2,4,8,16,32` にすると同時32件・約19GiB。変更後は `switch-api.ps1` で再起動し、`api.log` の `engine ready: classes=[...] rows=N` で確認する。

波形復号の左文脈は同じ `.env` の `TTS_CONTEXT_FRAMES` で決まる（`api_server_batch.py` の既定値は25）。2026-09-13 19:02から `12`（聴取で25と区別がつかず、同時32件時の復号時間が約半分になる。計測は [バッチエンジンの文書](qwen3-tts-batch-engine-2026-09-12.md) 第3版）。起動ログの `engine ready: ... context_frames=12 (4.2s)` で確認する。行を消すと25に戻る。

## 自動起動しなかったときの手動手順

管理者PowerShellを開く。以下はPCを再起動せず、TTS・ngrokの起動状態を確認・復旧する手順。

### 1. 状態とログを確認する

```powershell
$ttsRuntime = 'C:\Users\exodj\projects\toytalker\.local\tts-service'
Get-ScheduledTask -TaskName TTS-AutoStart | Select-Object TaskName, State
Get-ScheduledTaskInfo -TaskName TTS-AutoStart | Select-Object LastRunTime, LastTaskResult
Get-Content "$ttsRuntime\logs\supervisor.log" -Tail 30
```

`Running`は監視プログラムの稼働を示し、音声生成成功そのものを示すわけではない。初回起動前はログファイルがまだ存在しない場合がある。

### 2. タスクを手動で起動する

停止中なら次を実行する。Disabledなら先に有効化する。

```powershell
Enable-ScheduledTask -TaskName TTS-AutoStart
Start-ScheduledTask -TaskName TTS-AutoStart
```

モデルロードを待ち、ログに`api ready`と`Service ready; public health verified; Lambda URLs match (managed by CDK)`が出るか確認する（ngrok経路では`Service ready; public health and Lambda URLs verified`）。タスクがすでにRunningの場合は重複実行されないため、この操作では再起動にならない。

### 3. ヘルスと音声を確認する

```powershell
Invoke-RestMethod 'http://127.0.0.1:8000/health' -TimeoutSec 10
Invoke-RestMethod 'http://127.0.0.1:4040/api/tunnels' -TimeoutSec 10
Get-Content "$ttsRuntime\logs\supervisor.log" -Tail 30
```

8000番への接続失敗はAPI未起動・準備中など、4040番への接続失敗はngrok未起動などの手掛かり。接続できても公開トンネルやAWS更新に失敗することがあるため、監視ログも合わせて見る。最後にスマホでクローン音声の会話を試す。

監視が新しく起動したプロセスの出力は`logs/api.log`と`logs/ngrok.log`。引き継いだ既存プロセスの過去の出力はこれらには保存されない。エラーが続く場合はログを確認し、PC再起動を繰り返さない。

### 4. タスクが使えない場合の一時的な直接起動

タスク自体が実行できない場合は、ログオンしたPowerShellから同じ監視プログラムを直接実行できる。先にタスクを無効化・停止し、二つの監視が同時に動かないようにする。停止時に音声が中断する可能性があるため、会話していないときに行う。

```powershell
Disable-ScheduledTask -TaskName TTS-AutoStart
Stop-ScheduledTask -TaskName TTS-AutoStart
Get-ScheduledTask -TaskName TTS-AutoStart | Select-Object State
# Runningでなくなったことを確認してから次へ進む
$ttsConfig = Get-Content "$ttsRuntime\config.json" -Raw | ConvertFrom-Json
& $ttsConfig.python -u "$ttsRuntime\supervisor.py" --config "$ttsRuntime\config.json"
```

このコマンドは監視を続けるため終了しない。PowerShellを開いたまま使い、状態確認は別のウィンドウで行う。一時対応を終えるときはCtrl+Cで直接起動した監視を終了させてから、タスクを有効化・起動する。残っているAPI/ngrokは監視が引き継ぐ。

```powershell
Enable-ScheduledTask -TaskName TTS-AutoStart
Start-ScheduledTask -TaskName TTS-AutoStart
```

配置ファイル自体が失われている場合はこの直接起動もできないため、登録手順または以下の元タスクへの復元を使う。プローブには稼働中のTTSが必要なので、完全停止状態でプローブだけを繰り返しても起動はしない。

## 戻し方

管理者PowerShellで監視タスクを停止し、保存したXMLを再登録する。停止時にタスク配下の子プロセスも終了する可能性があるため、音声利用していない時間に行う。

```powershell
Stop-ScheduledTask -TaskName TTS-AutoStart
$previous = Get-Content .\.local\tts-service\TTS-AutoStart.before.xml -Raw
Register-ScheduledTask -TaskName TTS-AutoStart -Xml $previous -Force
```

既存API/ngrokが残っている場合は二重起動しないようプロセスを確認してから元タスクを起動する。プローブタスクは起動トリガーがなく、自動では実行されない。

## 検証記録（2026-09-11）

- Python/PowerShellの構文確認を実施。
- 既存プロセス引継ぎ、終了後の待機、所有プロセスのみのヘルス復旧、モデルロード猶予、Lambda環境変数保持・RevisionId・URL不変時の非更新をユニットテストで検証。
- ユニットテスト6件成功。
- 通常権限ではタスク登録がアクセス拒否となり、UAC昇格で登録・実行した。
- 22:52:53、S4Uの非対話プローブでCUDA割当、`.env`読込、ローカル・公開ヘルス、AWS読取、ngrok設定ファイル存在確認が成功。タスク結果0。
- 22:53:36、監視開始。API PID 16796、ngrok PID 16968を停止せず引き継いだ。22:53:45、公開ヘルスと5つのLambda URLの照合に成功。URL更新は発生していない。
- 実タスクがRunning、S4U/Limited、MSFT_TaskBootTrigger、遅延PT30S、時間制限PT0S、再試行999回/PT1M、IgnoreNewであることを確認。
- OS再起動・プロセス強制終了の実機試験は未実施。

参考: [Microsoft: 起動時トリガー](https://learn.microsoft.com/en-us/windows/win32/taskschd/starting-an-executable-on-system-boot)、[タスクの再試行・実行時間設定](https://learn.microsoft.com/en-us/powershell/module/scheduledtasks/new-scheduledtasksettingsset)

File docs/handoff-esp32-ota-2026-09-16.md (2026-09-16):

# 引き継ぎ: ESP32 OTA 実装後の状態（2026-09-16）

OTA実装セッションの引き継ぎ。新しいセッションでは最初にこのファイルと [OTA実装](esp32-ota-settings-plan.md) の「OTA実装」節を読む。

## 1. 状況

- **OTAは実装済みで、実機で更新に成功した**（2026-09-16 06:39、試験機「v0.2 大スピーカー」`90:da:72:49:ba:e5`、0.7.1 → 0.7.2、更新全体 17.0秒）。更新後の会話も通常どおり。実測は [OTA実装](esp32-ota-settings-plan.md) の「実機検証」。
- main は bc61ff0（OTA実装 b18c70d、0.7.2 c65d06a、docs bc61ff0）。ブランチ `esp32-ota` と worktree `.claude/worktrees/esp32-ota` は main と同じ内容で残っている。**削除は未了承**（了承を得てから `git worktree remove` と `git branch -d`）。
- 配布した版のタグ: `fw-0.7.1`、`fw-0.7.2`（push済み）。戻すときは `git checkout fw-0.7.1 -- devices/mcu/esp32_s3/toytalker_mini_v0.7`。
- 試験機は 0.7.2 が app1 で稼働、`fw_channel=beta` のまま。配布機は `toytalker_v07_serial_nowait`（OTA非対応）のまま。
- S3 `toytalker-firmware`: `esp32s3/0.7.1/`、`esp32s3/0.7.2/`、`manifest.json`（`channels: {beta: "0.7.2"}`、**stable は未設定**）。

## 2. 決定事項（このセッションで合意）

- 更新確認は起動時のみ、Soniox一時キー取得の応答に同梱。本体はS3の署名付きURLから直接取得。Lambdaは中継しない。本体に認証情報は持たない。
- 本体側の防御はホスト固定・Amazon Root CA 1〜4 での証明書検証・SHA-256 照合。署名付きURLが誰でもGETできることは許容（読まれても実害なし）。
- 配布制御は `toytalker-devices.fw_channel`（stable / beta）と `fw_target`。
- **スケッチのフォルダは v0.7 の1つで、配布した版は git タグで残す**（1版=1フォルダ方式は途中まで作って却下。OTAで版が増えることを見込んだ）。版は `FirmwareVersion.h`。
- NLP既定を AGGR に変更（実機構成と同じ。ビルドフラグ不要に）。`sketch.yaml` にボード設定。
- Lambda 2本（Soniox、デバイス設定）は **CDKスタック `ToyTalker-rnd` 管理**。`deploy.sh` で触らない（2026-09-16に一度触ってドリフトを起こし、CDK側で吸収してもらった）。反映は `cd infra && npx cdk deploy --context stage=rnd`。CDK側の変更は `cdk-infra` ブランチ（別セッション、2026-09-16時点で未push）。

## 3. やり残し

### OTAの残り検証（3件、実機とS3操作が要る）

発行スクリプトと S3 の書き換えは自動判定で止まるので、ユーザーが `!` 付きで実行する（例: `! bash devices/mcu/esp32_s3/tools/publish-firmware.sh beta --no-build`）。

1. **途中電源断**: 0.7.3（版だけ上げる）を beta に発行し、ダウンロード中（`[OTA] progress` の途中）に電源を切る。0.7.2 で起動し `attempt=2/3` で再試行して成功することを見る。
2. **SHA改ざん**: `manifest.json` の `versions.<版>.sha256` を1文字変えて置き、電源入れ直し。`[OTA] sha256 mismatch` → `fail: stage=sha256` で拒否し、0.7.2 のまま録音に入ることを見る。終わったら正しい値に戻す。
3. **ロールバック**: `startNormalOperation()` の鍵取得前で `abort()` する版を発行。新版が落ちてブートローダーが旧版へ戻り（起動ログに rollback の記録）、旧版が同じ目標版を3回試して `skip: attempts=3 reached limit` で止まることを見る。試験後は目標版を戻す（マニフェストの beta を 0.7.2 へ）。

### OTAの運用上の未了

- `stable` チャネルが未設定。配布機へ広げるときは `publish-firmware.sh stable --promote`。ただし配布機は現行ファームにOTAコードが無いので、**一度はUSBで 0.7.x を書く必要がある**。配布機のパーティションが `no_fs` でない可能性もあり、USB書き込み時にブートローダー・パーティション表ごと更新される。
- 発行スクリプトのビルド出力先 `$TMPDIR/toytalker_publish_build` に別名の `.ino.bin` が残っていると `arduino-cli upload --input-dir` が「複数の成果物」で止まる（2026-09-16に v0.7.1 の残骸で発生）。USB書き込み前に古い成果物を消す。
- Soniox Lambda はマニフェストを60秒キャッシュする。発行直後の起動で提案が出ないときは1分待つ。
- 本体の `ALLOWED_HOST` はバケット名固定。複数アカウント化でバケット名に環境名が付くときは、接続先と同様にビルドフラグで切り替える（[複数アカウント計画](multi-account-iac-plan.md)）。
- アプリ側の `fw_channel` 切替UIと版の表示は未実装（API は `PUT /devices/{id}` に入っている）。
- CLAUDE.md のLambdaデプロイ手順は CDK 側セッションが `cdk diff` → `cdk deploy` に更新済み（main 878d1a5 で取り込み）。`deploy.sh` はもう使わない。

### 新しく見つかった問題: 検索を使ったターンの誤停止（OTAとは別件）

- 現象: Web検索（tool_call）を挟んだ返答で、検索後の文の再生が始まった直後に止まる。ユーザーは話していない。
- 証拠（`.local/serial/esp32.log`、2026-09-16 08時台、turn=2）: 「調べてみるね。」→ `tool_call web_search` → 数秒の無音（`underrun → rebuffering`）→ 「今日の東京は、雨が降るようです。」の `tts_start` 直後に `[AEC_TRIGGER] mic=4074 ref=13661 out=1332 threshold=1200` → `interrupted=1`。中断後の文字起こしは「どうした」だけ。同ターンの消去量は 7.7〜9.2 dB（通常のターンは 10〜38 dB、残留 2〜127）。
- 仮説（推測）: 検索中の無音で AEC の学習が止まり、再開直後の大音量の頭出しを消しきれず残留が閾値をわずかに超える。無音後の再開で参照と入力の時刻合わせがずれる可能性も未確認。
- 対策候補（未実装、未合意）: 痛み止めとして「再生が一定時間止まって再開した直後の 300〜500ms は声の判定を無効にする」。根治寄りは無音区間の AEC の扱い（参照ゼロを流し続ける、学習状態の保持）。閾値を上げるのは通常時の感度が落ちるので勧めない。
- 精度全般の見通し（ユーザーに説明済み）: 消去量を安定して 25 dB 以上にできれば閾値を 400〜600 に下げる余地がある。限界はマイクとスピーカーの物理配置と小型スピーカーの歪み。大きさでなく言葉で止めるウェイクワード方式（ESP32-S3向け）が別の道で、メモリの余裕（内部RAM 16万バイト前後）は要確認。

## 4. 環境メモ（Mac）

- シリアル取得は `.local/serial/capture.sh`（`nohup` で常駐、`.local/serial/esp32.log` へ追記）。USB書き込みの前に止め、後で起動し直す（ポートを握るため）。
- ビルドは `arduino-cli compile devices/mcu/esp32_s3/toytalker_mini_v0.7`（`sketch.yaml` の `default_fqbn` を使う）。書き込みは `arduino-cli upload -p /dev/cu.usbmodem1101 --input-dir <build-dir> devices/mcu/esp32_s3/toytalker_mini_v0.7`。
- 本番操作（S3書き込み、Lambda設定変更、DynamoDB書き込み）は自動判定で止まるか都度確認になる。止まったものはユーザーが `!` で実行する。

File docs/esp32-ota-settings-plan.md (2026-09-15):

# ESP32 OTA・設定同期・状態送信の準備

2026-09-07の相談内容と、2026-09-10の音声割り込み・相槌ON/OFFの追加相談。以下は実装方針・候補であり、OTA・設定同期拡張・センサー送信の実装完了を意味しない。

## 実機の開発設定

ユーザー提供のArduino IDE画面ではESP32S3 Dev Module、Flash 4MB、QIO 80MHz、QSPI PSRAM、CPU 240MHz、Arduino/Events Core 1。USB CDC On BootはEnabled、USB ModeはHardware CDC and JTAG。

Partition Schemeは **No FS 4MB (2MB APP x2)** (`no_fs`)。コア3.3.10の定義では各アプリ領域は2,031,616 bytesで、otadataとNVSもある。現在の約1.40MBのファームは収まる。OTA実装後にサイズを再確認する。この構成で書き込み済みなら、OTAのための領域変更は不要。

以前のCLIビルド確認用の `huge_app` は実機設定とは異なり、OTA非対応。今後OTAのビルド確認では `PartitionScheme=no_fs` を使用し、USBなどの設定も実機に合わせる。ArduinoのままOTAを実装する方針で、ESP-IDF移行は前提としない。

## 設定同期

- スマホから設定用Lambda経由でDynamoDBに設定を保存する。
- 本体はSoniox一時キー取得のレスポンスで、区切りの間隔などの本体設定も取得する方針。
- TTS区切りは現状400msの定数。可変化は今後の実装。設定にはリビジョンを持たせ、値の範囲を検証し、欠落時は前回値または初期値を使用する。
- 設定は会話開始前など安全な区切りで反映する。反映頻度はキー取得タイミングに依存し、スマホ操作直後の即時反映は保証しない。
- OTAによるプログラム更新と、設定値だけの変更を区別する。

### 音声割り込み・相槌の再起動なしON/OFF（2026-09-10、相談段階・未実装）

ユーザーから、音声割り込みをスマホ側でON/OFFできるか、再起動せず反映できるか、既存の相槌設定はどうなっているか、という相談があった。現状のコードを確認した結果は以下。

- スマホの [`app/app/(tabs)/toy.tsx`](../app/app/(tabs)/toy.tsx) にデバイス別の相槌スイッチがあり、設定用Lambdaの `PUT /devices/{device_id}` で `backchannel_enabled` をDynamoDBへ保存する。画面では「おもちゃの電源を入れ直してください」と案内している。
- [`toytalk-soniox-stt-lambda`](../backend/toytalk-soniox-stt-lambda/index.mjs) がSoniox一時キーとともに相槌設定を返す。v0.7の `startNormalOperation()` は起動時にこれを読み、`backchannelEnabled` に反映する。会話中の設定再取得はまだない。
- 音声割り込みは `AecBargeGate.h` の `AEC_BARGE_DETECT_ONLY=false` など、ファーム内の固定設定。スマホのスイッチ・保存APIの項目・本体への同期は未実装。

変更候補は、スマホのデバイス設定に「声で再生を止める」を追加し、相槌と合わせてサーバーへ保存、本体が設定を再取得して会話の合間に反映する構成。音声割り込みONなら声で停止、OFFなら声では停止せず、通常の録音・会話とボタン停止は利用できる動作を想定する。

最初に対応するアプリ・サーバー・ファームの変更が必要だが、導入後は設定切替のたびのファーム書き込み・本体再起動を不要にできる。取得した設定を次の会話・再生から反映する案であり、スマホ操作直後の即時反映を実現済みという意味ではない。

再取得のAPI・頻度・反映タイミング、OFF時にAEC演算も休止する範囲は未決定。設定取得が本文開始を待たせないこと、処理中のAEC/I2Sを不整合な状態で切り替えないこと、通信失敗時は前回値を保持することを設計時に確認する。ここで扱うのは設定値の同期で、保留中のOTA実装とは別の作業。

## 本体状態の送信

Wi-Fi接続後の初回通信で、温度・電池電圧・充電状態・ファームバージョンなどを送信する方針。起動後の変化も扱うため、定期送信や充電状態の変化時の送信を検討する。頻度・APIは未決定。スマホには最終更新時刻を表示する。

PCB資料: [PINMAP](../devices/KiCad/toytalker_mini_v0.2/PINMAP.md)、[部品表](../devices/KiCad/toytalker_mini_v0.2/PARTS_LIST.md)、[実機確認計画](../devices/KiCad/toytalker_mini_v0.2/PHASE4_5_PLAN.md)。

- VBAT: GPIO1、470kΩ×2の分圧。残量パーセントは直接測定値ではなく推定となるため、まず電圧と区別する。
- TH2: GPIO2のサーミスタ。ESP32内部温度とは別項目にする。資料には基板温度と電池上への配置指示があるため、測定対象の名称は実装位置を確認して確定する。
- STAT1/STAT2: GPIO13/14。状態の解釈は充電ICの仕様と実機で確認する。
- TH1: ハードウェアの充電温度保護用。ファームから直接読めるセンサーとして扱わない。

## OTA実装（2026-09-15実装、2026-09-16に実機で更新成功）

2026-09-14〜15の相談で合意し、ブランチ `esp32-ota` で実装した。2026-09-16に試験機で 0.7.1 → 0.7.2 の更新が通った（下の実測）。残る検証は中断・改ざん・ロールバック・更新後の会話。

### 確認済みの前提

- 実機の `no_fs` はapp0/app1が各2,031,616バイトでotadataもあり、OTAに使える。OTA込みのv0.7.1（NLP=AGGR）のビルドは1,491,778バイト（73%）で、OTA追加分は約15KB。
- Arduino ESP32 3.3.11は `CONFIG_APP_ROLLBACK_ENABLE=y`。ただしコアが起動時に自動で有効印を付けるため、スケッチで `verifyRollbackLater()` を `true` に上書きし（Cリンケージなので `extern "C"`）、健全性確認後に `esp_ota_mark_app_valid_cancel_rollback()` を呼ぶ。
- 起動時のSoniox一時キー取得（`toytalk-soniox-stt-lambda`、`device_id` 付き）が更新確認の置き場。追加の通信は要らない。
- 通信はすべて `setInsecure()`。OTAだけ証明書検証を入れる。S3 ap-northeast-1 の証明書はSANに `*.s3.ap-northeast-1.amazonaws.com` を含み、Amazon Root CA 1〜4で検証できることをopensslで確認した。
- `toytalker-devices` は16台で配布機が複数ある。配布機のパーティション・ブートローダー世代は未確認。
- Lambdaのロール `toytalk-lambda-role-dev` には `AmazonS3FullAccess` が付いており、IAMの追加は不要。

### 方式

- **確認するLambda**: `toytalk-soniox-stt-lambda` だけ。応答に `firmware: {version, url, sha256, size}` を同梱する。他のLambdaは関与しない。
- **配布**: 非公開S3バケット `toytalker-firmware`。`esp32s3/<version>/toytalker_mini.bin` と `esp32s3/manifest.json`（`versions` に版ごとの `{key, sha256, size, published_at}`、`channels` に `stable` / `beta` が指す版）。Lambdaが10分の署名付きURLを返す。本体はS3から直接GETし、Lambdaはバイナリを中継しない。本体に認証情報は持たせない。
- **配布制御**: `toytalker-devices.fw_channel`（既定 `stable`、試験機は `beta`）。個別固定用に `fw_target`（版名。空文字で解除）。昇格はマニフェストの書き換えだけ（`publish-firmware.sh stable --promote`）。
- **版の識別**: `FirmwareVersion.h` の `TOYTALKER_FW_VERSION` / `TOYTALKER_HW_VERSION`。`[BUILD]` と `[OTA]` の起動ログに出る。キー取得時に `fw` `hw` `ota` `part` を送り、Lambdaが登録済みの行にだけ `firmware_version` `hw_version` `ota_capable` `running_partition` `fw_reported_at` を保存する（未登録の `device_id` で行は作らない）。判定は「目標版と不一致なら更新」で大小比較はしない。
- **本体が偽ファームを受け取らないための検証**（署名付きURLは誰でもGETできる前提。読まれる実害は無いので許容し、守るのは本体側）:
  1. URLのホストを `toytalker-firmware.s3.ap-northeast-1.amazonaws.com` 固定で照合し、他は拒否。
  2. 更新用クライアントだけ Amazon Root CA 1〜4（`AmazonRootCA.h`、公開情報、約5KB）で証明書検証する。取得・発行・更新作業は不要。1枚だけだとルート切替時にOTA不能になるので4枚。
  3. 受信バイト列のSHA-256をLambdaの値と照合してから `Update.end()`（イメージヘッダ・チップ検査と起動パーティション切替）を呼ぶ。
  4. バイナリ署名（`UPDATE_SIGN`）は第2版以降。
- **タイミング**: 第1版は起動時のみ。録音・WebSocket・AECが動く前に終える。稼働中の定期確認は第2版。
- **失敗時**: ダウンロード・書き込み・SHA不一致・タイムアウト（応答15秒、無通信15秒、全体180秒）のどれでも `Update.abort()` して通常動作へ進む（再起動ループにしない）。同じ目標版への試行回数をNVS（namespace `ota`）に数えて3回で諦める。回数は開始前に記録するので、途中の電源断も1回に数える。ロールバックで旧版に戻った場合も同じカウンタで再更新ループを防ぐ。
- **ロールバック確認**: 新版がWi-Fi接続とSonioxキー取得に成功した時点で `ota::confirmRunningImage()` が有効印を付ける。それ以前にクラッシュすればブートローダーが旧版へ戻す。
- **OTA可否**: `esp_ota_get_next_update_partition()` がNULLなら `ota=0` を報告して更新しない（`huge_app` で書かれた機の保護）。
- **LED**: 更新中は60ms周期の速い点滅（`LED_BLINK_OTA`）。この間は電源を切らない。

### 実装した場所

- ファーム: [`toytalker_mini_v0.7`](../devices/mcu/esp32_s3/toytalker_mini_v0.7/) に追加。[`OtaUpdater.h`](../devices/mcu/esp32_s3/toytalker_mini_v0.7/OtaUpdater.h)（検証・ダウンロード・書き込み・有効印）、[`FirmwareVersion.h`](../devices/mcu/esp32_s3/toytalker_mini_v0.7/FirmwareVersion.h)、[`AmazonRootCA.h`](../devices/mcu/esp32_s3/toytalker_mini_v0.7/AmazonRootCA.h)、`sketch.yaml`（`default_fqbn`。IDE 2とarduino-cliが読む）。`AecMonitor.h` のNLP既定を実機構成のAGGRにした。`.ino` は `startNormalOperation()` のキー取得直後に有効印と更新適用を入れ、`verifyRollbackLater()` の上書きと `LED_BLINK_OTA` を追加。
- 発行: [`devices/mcu/esp32_s3/tools/publish-firmware.sh <beta|stable> [--dry-run] [--no-build] [--promote] [--force]`](../devices/mcu/esp32_s3/tools/publish-firmware.sh)。版は `FirmwareVersion.h` から読む。フォルダに未コミットの変更があると止まり（`--allow-dirty` で試験発行は可、タグなし）、発行に成功したコミットへタグ `fw-<版>` を付ける。同じ版のS3オブジェクト・タグは既定で上書きしない。偽の `aws` を使ったオフライン試験で、発行・重複拒否・昇格の3経路を確認済み。
- Lambda: `toytalk-soniox-stt-lambda` に判定と署名付きURL発行（`deploy.sh` の外部指定に `client-s3` と `s3-request-presigner` を追加。Node 22ランタイム同梱）。`toytalker-device-setting-lambda` の `PUT /devices/{id}` が `fw_channel` `fw_target` を受け付ける。Soniox・S3・DynamoDBをスタブにしたローカル試験で、stable/betaの振り分け、`fw_target` による戻し、更新不要、`ota=0`、未登録機、旧ファーム（`fw` なし）の互換を確認済み。

### 配布の手順

1. **1フォルダ + gitタグ。** `toytalker_mini_v0.7` には最新のソースだけを置く。`FirmwareVersion.h` の版を上げてコミットする（2026-09-16決定。版ごとにフォルダを残す方式は、OTAで版が増えることを見込んで採らなかった）。
   - 配布した版のソースへ戻す: `git checkout fw-<版> -- devices/mcu/esp32_s3/toytalker_mini_v0.7`（作業中の変更は先にコミットしておく）。
   - 並べて見たい: `git worktree add .claude/worktrees/fw-<版> fw-<版>`。
2. `bash devices/mcu/esp32_s3/tools/publish-firmware.sh beta` でビルド・S3配置・タグ付け。タグは `git push origin fw-<版>` で共有する。
3. 試験機（`fw_channel=beta`）の電源を入れ直し、`[OTA]` ログとDynamoDBの `firmware_version` を確認する。
4. `bash devices/mcu/esp32_s3/tools/publish-firmware.sh stable --promote` で全機へ。

### 実機検証

1. 済（2026-09-16）: 0.7.1 をUSBで書き込み。起動時の `[OTA] confirm: img_state=-1 (no action)` でUSB書き込み版は有効印の対象外と確認。
2. 済（2026-09-16 06:39）: 0.7.2（版の文字列だけ変更）を `beta` に発行し、試験機「v0.2 大スピーカー」（`fw_channel=beta`）の電源を入れ直し。実測:
   - Wi-Fi接続 5.0秒 → 鍵取得 → `[OTA] start: 0.7.1 -> 0.7.2 size=1491920 attempt=1/3`
   - TLS接続とヘッダー 614ms、ダウンロードと書き込み 16.9秒（約88KB/s、10%ごとに1.4〜2.0秒で一定）、`[OTA] done total_ms=17040`
   - 再起動後 `[BUILD] fw=0.7.2`、`running=app1 next=app0 img_state=1`（検証待ち）、Wi-Fi再接続 1.9秒、鍵取得後に `[OTA] confirm: pending_verify -> valid err=0`
   - DynamoDB `firmware_version=0.7.2 running_partition=app1 ota_capable=true`
   - 録音前の `ALLOC_FAIL total=0` / `HEAP_CHECK ok=1 internal_free=168728`。更新のある起動の遅れは約20秒（見込み15〜40秒の範囲内）
   - 署名付きURLは一時トークン込みで1,587文字（上限4,096）。S3からの取得はAmazon Root CA 1〜4だけで検証が通る（Macのcurlでも確認）
3. ダウンロード途中で電源断。旧版で起動し再試行することを確認。
4. SHA-256を壊したマニフェストで拒否されることを確認。
5. 有効印の前にわざとクラッシュする版で、旧版へ戻り試行カウンタでループが止まることを確認。
6. 更新後にWi-Fi設定（NVS）が残り、通常会話ができることを確認。

### 本番に入れたもの（2026-09-16）

- S3バケット `toytalker-firmware`（ap-northeast-1、パブリックアクセス全遮断、SSE-S3、バージョニング有効、タグ project=toytalker / purpose=esp32-firmware-ota）。
- Soniox Lambda と デバイス設定 Lambda はCDKスタック `ToyTalker-rnd` 経由で反映（タイムアウト5秒、devices書き込み権限、`toytalker-firmware` 読み取り権限、環境変数 `FIRMWARE_BUCKET`）。**この2本は2026-09-15にCDK管理へ移っており、`deploy.sh` で触るとドリフトになる。** 反映は `cd infra && npx cdk deploy --context stage=rnd`（[複数アカウント計画](multi-account-iac-plan.md)）。
- 発行済み: 0.7.1（beta→試験機へUSB書き込み）、0.7.2（beta、OTAで試験機へ）。`stable` は未設定なので、beta以外の機には更新提案が出ない。配布機へ広げるときは `publish-firmware.sh stable --promote`。

### 見込みと制約

- 所要時間の実測は上の「実機検証」2。自宅Wi-Fiで約17秒（1.49MB）。更新の無い起動は変わらない。
- 配布済みの実機は現行ファームにOTAコードが無いので、初回だけUSB書き込みが必要。
- 本文Lambda・Soniox WSの `setInsecure()` は今回触らない。
- 署名付きURLはLambdaの一時認証情報を含むため2KB前後になる。本体のJSON読み取りはArduinoJson 7で容量制限が無く、URL長の上限は4096にしている。

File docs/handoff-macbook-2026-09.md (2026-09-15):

# MacBookでの開発 引き継ぎ（2026-09-13作成）

来週の大阪出張でMacBookから開発するための引き継ぎ。Mac側でClaude Codeを新規セッションで起動し、最初に「docs/handoff-macbook-2026-09.md を読んで」と伝える。Windows PC側のClaude Codeセッションは別マシンへ移せないので、状況はこのファイルとCLAUDE.mdで渡す。

方針: 開発は基本Macのローカルセッションで行う。自宅Windows PC（TTSサーバー）の面倒を見るときだけRemote Controlを使う。

## 1. 出発前にWindows側でやること

| # | 項目 | 状態 |
|---|---|---|
| 1 | 未コミット変更のコミットとpush | 済（2026-09-13 19:40） |
| 2 | stash 2本の整理 | 済（2026-09-13、確認のうえ削除） |
| 3 | `backend/*/deploy.sh` のMac対応、各Lambdaの `npm install`、ESP32シリアル受信 | 済（2026-09-13、Mac側で対応） |
| 4 | 自宅PCへの遠隔手段（Remote Control、Tailscale等） | 済（Tailscale + Sunshine/Moonlight、2026-09-13 Macから接続確認） |
| 5 | ESP32実機・USBケーブル・スマホ（実機アプリ）の持参 | 未（出発時に確認） |
| 6 | 出発直前にWindows Updateを手動確認し、更新と再起動をその場で済ませる | 未 |

### 1-1. コミット・push・stash（2026-09-13 19:40 時点で完了）

- 2026-09-13の作業はすべてコミット・push済み。ローカル・リモートとも `main` のみで、worktree・stash・未コミット変更は無い。Macでは `git pull` するだけでよい。
- 古いstash 2件（設定ファイルの差分と、ESP32音声修正の中断分）は中身を確認のうえ削除済み。

### 1-3. deploy.sh のMac対応（済）

2026-09-13にMac側で対応した。8本の `backend/*/deploy.sh` と `toytalker-ops-monthly-lambda/setup.sh` を、同じファイルのままWindows（Git Bash）とMacの両方で動くようにした。

- `"/c/Program Files/nodejs/npx.cmd"` / `npm.cmd` の絶対パスをやめ、PATHの `npx` / `npm` を使う。
- zip作成は `zip` コマンドがあればそれを使い（Mac / Linux）、無ければ従来の `powershell Compress-Archive`（Windows Git Bash）に分岐する。
- `set -euo pipefail` が無かった3本（soniox-stt、device-setting、tts-only）に追加した。無いとバンドル失敗時に古いzipをそのままデプロイしてしまう（Macの試験で実際に起きかけた）。

動作確認は本番へデプロイせずに行った。`aws lambda update-function-code` だけ握りつぶす偽の `aws` をPATHの先頭に置いて8本を最後まで実行し、できた `deploy.zip` の中身を `aws lambda get-function` で取得した本番コードと比較して、8本すべて一致を確認した。Macで初めて動かすLambdaは先に各ディレクトリで `npm install` が要る（`openai` 等の依存が無いとesbuildが失敗する）。

### 1-4. 自宅PCの遠隔手段（2026-09-13 21:50 時点で確認済み）

TTSサーバー（RTX 5090）は持ち出せない。自動復帰の仕組みに加えて、止まったときに手を入れる手段を以下で用意した。

- **Tailscale**: 自宅PC（`desktop-ojpa2dh`、100.125.70.89）・MacBook・iPhoneの3台が同じアカウントで接続済み。サービスは自動起動。
- **Sunshine + Moonlight（画面共有）**: Windows側は `SunshineService`（自動起動）が稼働し、47984/47989/47990/48010をLISTEN。ファイアウォール規則「Sunshine」でTCP/UDP受信を全プロファイル許可済み。MacのMoonlightには `DESKTOP-OJPA2DH` がペアリング済みで、手動アドレス 100.125.70.89 も登録済み。2026-09-13にMacをiPhoneテザリング（LAN外）にした状態でTailscale経由の接続試験に成功（1920x1080 HEVC、遅延約41ms、コマ落ち0%、リレーなしの直接接続、PIN入力不要）。昇格が必要な操作（`switch-api.ps1`、`cloudflared` サービス再起動、Windows Update）はこれで行う。
- **Claude Code Remote Control**: Windows側で `claude --remote-control` を起動したままにすると、Macのブラウザ（claude.ai/code）やスマホアプリからこのPC上のセッションを操作できる。PC再起動で消えるので、消えたらMoonlightから起動し直す。
- **セッション間メッセージ**: MacのClaude Codeセッションから自宅PCのセッションへメッセージを送れることを確認した（2026-09-13）。相手側の権限内の確認作業を頼む用途。
- 使えないもの: Windows 11 Homeはリモートデスクトップのホストになれない（`fDenyTSConnections=1` のままでよい）。OpenSSHサーバーは未導入。
- 復旧手順は [起動・復旧](tts-boot-recovery.md)。Windows更新の再起動はアクティブ時間07:00〜翌01:00の外で起きる（[設定記録](windows-update-restart-control.md)）。再起動後にTTSが自動復帰することは2026-09-13 17:48の再起動試験で確認済み。

### 1-5. 出発前に確認した自宅PCの状態（2026-09-13 21:50）

- 電源設定: AC時のスリープ・休止はともに「なし」。
- `TTS-AutoStart` は稼働中。直近の起動ログに「public health and Lambda URLs verified」。`cloudflared` サービスは自動起動で稼働中。Lambdaの `ZAKICORP_TTS_URL` は `https://tts.zakicorp.com`。
- Windows Updateの再起動待ちは無し。出発直前に手動で更新確認し、溜まった更新と再起動をその場で済ませる（留守中の自動再起動を減らす）。
- TTSサーバーが完全に落ちた場合、Cloudflareが5xxを返せばフォールバックでずんだもんへ切り替わる。応答が遅いだけの状態は切り替わらない（遅延条件は未実装、5節の4）。長引くときは `toytalker-voices` でZakiCorpボイスをCartesiaへ差し替える（Macから可能）。

## 2. Macのセットアップ

```bash
# Homebrew前提
brew install git node@22 awscli arduino-cli
npm install -g @anthropic-ai/claude-code
git clone https://github.com/tomonoriyamazaki/toytalker.git
cd toytalker
aws configure   # Windowsと同じIAMキー、region=ap-northeast-1、output=json
```

- Node はWindows側が v22.19.0。同じメジャーにする。
- ESP32ファームを触るなら:

```bash
arduino-cli config init
arduino-cli config add board_manager.additional_urls https://espressif.github.io/arduino-esp32/package_esp32_index.json
arduino-cli core update-index
arduino-cli core install esp32:esp32@3.3.11
```

  CLAUDE.mdのcompileコマンドは `--build-path` を `/tmp/toytalker_v07_build` などに変えればそのまま使える。書き込み時のポートは `/dev/cu.usbmodem*`（`arduino-cli board list` で確認）。NLP=AGGRの `--build-property` も同じ。
- アプリ（Expo 53 / RN 0.79）: `cd app && npm install && npx expo start`。iOSシミュレータを使うならXcodeを入れる。EAS Buildはクラウドなのでどちらのマシンからでも同じ。
- Lambdaは各ディレクトリで `npm install`（`node_modules` がないLambdaは `npx esbuild` が都度取得する）。
- 秘密情報: リポジトリ内に `.env` は無い。Lambdaの環境変数はAWS側。Macに持ち込むのはAWSのキーだけ。ZakiCorpのAPIキーはTTSサーバーを触るときだけ必要で、サーバー側 `tts-models/faster-qwen3-tts/scripts/.env` にある。
- `.claude/settings.local.json` はGit対象外でマシン固有。Macでは最初は許可プロンプトが多いので、Mac側で改めて育てる。

## 3. Macで違うこと・触らないもの

- CLAUDE.mdの「PowerShellでgitを実行するときSet-Locationを使わない」「スクリーンショットの保存先」はWindows固有。Macでは該当なし。
- Macのスクリーンショット保存先は `~/Pictures/Screenshots`（2026-09-14に `defaults write com.apple.screencapture location` で設定）。「スクショ撮ったから見て」ではここを新しい順に見る。フォルダが空なら、クリップボードにコピーするモードで撮っている可能性が高い（設定の不具合ではない）。
- `tools/tts-service/`（supervisor.py, install.ps1, switch-api.ps1, cloudflared-service-fix.ps1）はWindows PC上でしか意味がない。Macから編集してもよいが、反映はWindows PCで昇格実行が必要。
- ESP32のシリアルログは `.local/serial-logs/`（Git対象外）にWindows側だけある。Macでは `.local/serial/capture.sh`（2026-09-13作成、Git対象外）が `/dev/cu.usbmodem*` を921600bpsで読み続けて `.local/serial/esp32.log` へ追記する。書き込みでポートが消えても再接続する。起動は `nohup .local/serial/capture.sh &`、閲覧は `tail -f .local/serial/esp32.log`。Arduino IDEのシリアルモニタとは同時に開けない。実機受信は2026-09-13にMacで確認済み。
- Macの `npm install` はpackage-lock.jsonを書き換える（Node v25 / Windowsはv22）。Lambdaはesbuildで束ねるので影響はないが、lockの差分はコミットしない。8本のうち依存があるLambda 6本は2026-09-13に `npm install` 済み。
- 2台で作業するので、切り替えのたびにpush/pullする。デプロイ前に `git log origin/main..HEAD` と `git status` で本番に出す版を確認する（CLAUDE.mdのworktree確認ルールと同じ趣旨）。

## 4. 出発時点の本番の状態（2026-09-13）

- ESP32実機: `toytalker_v07_serial_nowait`（2026-09-12夜書き込み）。詳細はCLAUDE.md「ESP32-S3ファーム開発」。
- ZakiCorp TTS: バッチ推論エンジン第2版、公開はCloudflare Tunnel `https://tts.zakicorp.com`、ngrokは予備。
- Lambda 5本の `ZAKICORP_TTS_URL` は上記固定URL。監視タスク `TTS-AutoStart` が維持する。
- Cartesia TTS: 本文・相槌・読み上げの5 Lambdaで利用可能（Proプラン）。アプリからのクローンボイス作成はデバイス設定Lambda（`POST /custom-voices` provider=Cartesia、タイムアウト60秒）。ボイス一覧の並びは `toytalker-voices.sort_order` でサーバー制御。[Cartesia TTS導入](cartesia-tts.md)。
- TTSフォールバック: 主プロバイダーが429/5xx等で失敗したら再試行→ずんだもん（返答単位で固定、Sakura分は別行で記録）。5 Lambdaに導入済み。[仕様と実測](tts-fallback-and-notifications.md)。Proでも同時64件まで429は出ず、96件で27件が切り替わることを実測済み。
- アプリ: 0.8.6 (24) をTestFlightへ送信済み。内部グループのみで、外部グループ「tester」への追加は未実施（追加すると新バージョンのBeta審査が入る）。開発ビルド（development、24）も端末に入っている。
- コスト: `service#margin` は2.0。単価表の全行に `provider` / `api_type` 列あり。`cartesia#tts` は$0.00005/字（Pro）、`serper#tool` は$0.001/回。為替2026-09は154.04円（ECB）。月次運用レポートLambdaは毎月1日にメール（10/1が初回本番）。
- Cartesiaへの問い合わせ（同時接続・組織・クローンの扱い）は2026-09-13に回答済み。要点は [フォールバック仕様の背景](tts-fallback-and-notifications.md)。

## 5. 残タスク（出張中に着手できるもの）

- CLAUDE.md「未確認」に挙がっている項目のうち、実機とスマホがあればできるもの: スマホからのZakiCorp会話確認、長文分割境界の聞こえ方、stream終端の切断・救済経路の再現。
- Cloudflare側の未実施: Accessのサービストークン、公開 `/health` の話者一覧非表示、話者登録名の検証。これはCloudflareダッシュボードとLambda側の作業なのでMacからできる。ただしTTSサーバー側の変更が要るものはWindows PCが必要。
- 先送り項目は [deferred-items.md](deferred-items.md)。
- 2026-09-13夜時点で次に手を付ける順番（合意済み、いずれも未実装）:
  1. 認証（Cognito: Apple・Google・LINE）。設計は [deferred-items.md](deferred-items.md) の「ユーザー認証」。
  2. 前払いポイント制（ウォレット・消費記録・Web購入ページ Stripe Checkout・プッシュ通知）。仕様は [原価と課金の考え方](pricing-and-cost-model.md) 第11節。購入ページは認証の後。
  3. 単価のモデル単位化（`provider#api_type#model` → `provider#api_type` の順で引く）と、利用状況の行をプロバイダーごとに分ける変更（同じ日に同じ端末で2プロバイダーを使うと `provider` が上書きされる既存の制約）。
  4. フォールバックの遅延条件（主プロバイダーの応答3秒超で切り替え）と、月次レポートへの「ピーク同時本数」「切り替え回数」の追加。
  5. Fish Audio (demo) のボイス16件は版権声のため、いずれ削除（使用中キャラクターの確認が先）。

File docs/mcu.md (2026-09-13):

# マイコン
このページは、ToyTalkのマイコン版（ESP32などを用いた構成）のパーツリストや接続、実装メモをまとめたものです。

## パーツ一覧
### マイコン部品
- メイン基盤：ESP32‑S3 DevKitC USB‑C 開発ボード：USB‑C給電、BLE・WIFI・I²S完備。
Espressif純正で信頼性高く、260MHzデュアルCPU、8 MB Flash & 2 MB RAM 
- マイク：INMP441 I²S MEMSマイクモジュール：高性能24bit/48 kHz I²S出力対応マイク。：ノイズに強い
- アンプ：MAX98357A I²S アンプモジュール：I²S信号→アナログ変換＋D級アンプ内蔵。
小型でも3 W駆動可能でスピーカ接続に最適。
- スピーカー：40 mm 8 Ω スピーカー　：ほどよい音量と品質。
- ブレッドボード（400～830穴）	：部品仮組用
- ジャンパーワイヤ（オス‑メス／40本）：各部品を安定接続。色分けで配線ミスも防げる。
- バッテリー：薄型LiPo（654060）	3.7V / 2000mAh / 厚さ6.5mm
- バッテリー補助①：TP4056（USB-C・保護付き）
- バッテリー補助②：MT3608：電圧を3.7V→5Vにして、ESP32に電力供給できるようにする
- ミニスライドスイッチ：3 pin 2mm
- JSTケーブル：バッテリー用。JST PH 2.0mmピッチ 2ピン 10CM
- レジスター：LED用。一式のセット
- LED：RGB 5mm。1つのランプで複数色を実現　※ちょい複雑になりそう
- プッシュボタン：色々セットで試す
- スピーカー用ワイヤ：22AWG silicone wire red black
- 絶縁チューブ：色々セットで試す

### 工具
- はんだごて
- テスター
- ノギス
- ニッパー
- 3M：絶縁テープ、両面テープ、マスキングテープ

### 今後必要なもの（本番向け）
- ユニバーサル基板：72x47mmくらい？
- ぬいぐるみ化に必要な素材
- 裁縫セット・マジックテープ
- 声の出口用 メッシュ布 or プラスチックメッシュ
- ユニバーサル基板（両面タイプ）
- ピンヘッダ／ピンソケット：モジュールの取り外しや交換できるように
- タクトスイッチの台座 or 小基板：押しやすく＆がたつき防止
- スペーサー・ネジセット（M2/M2.5）：スピーカーや基板の仮固定に便利
- DCジャック変換プラグ：USB-Cでの電源供給からモバイルバッテリーにも流用可
- ホットボンド or 小型グルーガン：固定用や絶縁補強に使える。低温型が安心

## 設計
これから

## 構成図
これから

## 基板設計の覚え書き

### 発注前チェック
- 寸法・配置・向きの根拠は、データシートの縮尺付き実寸図（Physical Dimensions）とファイル座標の実測にする。「not to scale」の模式図で判断しない。過去にESP32-S3-MINI-1を正方形と誤認した（実寸15.4×20.5、アンテナ含む）。
- 発注前に、3Dビューア確認、原寸紙テスト（実物部品を1:1印刷に載せる）、DRC・ERCゼロ、JLCPCBのDFMとガーバービューア確認を行う。

### 次の基板改修で行うこと
- 録音用I2SのBCLK/WSを再生用と別ピンに割り当てる。現在は録音/再生でクロックピン（BCLK=4, WS=3）を共有しており、サンプルレートが違う（16kHz/24kHz）ため同時動作できない。分離するとソフト側はピン番号の変更だけで再生中の録音が可能になる。優先度は低め。

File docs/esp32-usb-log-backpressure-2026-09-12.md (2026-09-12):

# USBログ未受信時の遅延

## 症状と根拠

2026-09-12、ログ取得が22:26:11で終了した後にユーザーが大きな遅延を報告。22:53:06に受信を再開し、ユーザーも正常に戻ったと確認。

受信再開直後のturn=10はamp_to_mic_ms=9969、mic_drop=389、ref_drop=254、clock_resets=57。以降のturn=13はamp_to_mic_ms=4、mic_drop/ref_drop/clock_resets=0。受信中断中の全文はなく、遅延の全てをこの原因に確定しない。本文生成待ちも別にある。

インストール済みArduino ESP32 3.3.11の `cores/esp32/HWCDC.cpp` では送信待ち既定100ms、連続タイムアウト20回で打ち切り。USBが接続されたままPCが読まない場合、送信キューが埋まると一度の書き込みで約2秒待ち得る。ファームは音声/STT処理と同じタスク内でもSerialへ出力するため、ログ待ちが処理を遅らせ得る。

## 修正

v0.7のsetupでSerial.begin直後、Hardware USB CDC使用時に `Serial.setTxTimeoutMs(0)` を設定。キュー空きや送信ロックを待たず、送れないログは欠落を許容する。起動ログ `[SERIAL] hwcdc_tx_timeout_ms=0 drop_on_backpressure=1` で確認可能。

対象は現行ボードのHardware USB CDC。UARTやNative USB用の動作変更ではない。Arduinoコアのファイルは編集せず、ファーム内で公開APIを使用。音声PCM・音量・AEC判定・ボタン処理は変更しない。ログ整形などのCPU処理は残るため、全処理が無コストになる意味ではない。大量出力や複数タスクの競合では、受信中でもログの一部が欠ける可能性がある。

## 検証・運用

受信再開後、ユーザーが「いい感じ」と報告し、今回の改修をコミット・統合する方針を指定。ログ未受信の長時間試験を完了したとの明示報告ではないため、その耐久性は未検証として保持する。

23:00台にビルド成功（Flash 1,477,126 bytes / 静的RAM 67,144 bytes）、COM12へ書き込みとハッシュ検証を完了。20秒の起動確認で `[SERIAL] hwcdc_tx_timeout_ms=0 drop_on_backpressure=1` とSTT送信157件/fail=0を複数回確認。確認後はポートを閉じた。USB未受信時の会話の聴取確認はユーザー確認待ち。既存ログファイルへの追記はファイルロックで失敗したため、この起動確認の証跡はツール出力と本記録に保持する。

FQBNは従来どおり `esp32:esp32:esp32s3:PSRAM=enabled,FlashSize=4M,PartitionScheme=no_fs,CDCOnBoot=cdc`。AGGR指定 `compiler.cpp.extra_flags=-DTOYTALKER_AEC_NLP_LEVEL=1`、ビルド先 `$env:TEMP/toytalker_v07_serial_nowait`。

コード確認：HWCDCの送信ロック、リングバッファ送信の待ち時間がともに0となる。キュー満杯時のリトライは最大20回で打ち切り。v0.7にSerial.flush呼び出しはない。

実機確認は通常の起動/STTと、PCが受信していない状態での会話を区別する。後者ではUSBケーブルを接続したままログ取得を終了し、会話・ボタン停止・録音復帰が遅くならないか確認する。再受信時に本体の電源を入れ直す必要はない。受信していなかった期間のログは完全には復元できない。

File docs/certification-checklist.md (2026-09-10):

# ToyTalker 製品化 認証チェックリスト（日本市場・STマーク目標）

対象: 自作ペンダント型ToyTalker（ESP32-S3 + LiPo + スピーカー/マイク + WiFi/BLE、子供向け）。
作成: 2026-09-09。認証は法規制が絡むため、本チェックリストは方向性の整理であり、確定情報は各所管団体・試験機関に確認すること。

## A. おもちゃ本体の安全 — STマーク【本丸】

発行: 一般社団法人 日本玩具協会。完成品を第三者機関（CERI等）に出して試験。3本柱:

- [ ] 機械的安全性: 誤飲（小部品）・尖り・強度。**ペンダント型は紐/ストラップの誤飲・首まわりの窒息リスクが要注意**
- [ ] 可燃安全性: 筐体・部材の燃えにくさ
- [ ] 化学的安全性: 鉛・可塑剤など有害物質の移行
- [ ] 電池は筐体内に固定し露出させない設計（ST基準の電池要件）

## B. 電波 — 技適【ESP32があるため必須】

- [ ] **ESP32-S3-MINI-1モジュールが日本の技適を取得済みか確認** → 済みならモジュール認証を流用でき、製品側の追加取得は不要
- [ ] 自作アンテナ・別モジュールに変更すると自分で取り直しになる → 技適済みモジュールを使い続ける

## C. 電池の安全書類【部品選定に直結】

- [ ] 使用する電池モデルの **UN38.3 試験報告書**を業者から入手（名義より、使用モデルと一致していることが重要）
- [ ] **IEC 62133** 証明の要否を **日本玩具協会/試験機関に確認**（ST必須かは未確認。「あれば有利」までが確実、「無いと不可」とは言えない）
- [ ] **電池の体積エネルギー密度（Wh/L）を業者に確認** → PSE（菱形/電池）対象判定用。現行候補は約385Wh/L で 400Wh/L 未満＝対象外の可能性が高いが**400にギリ近いため実測値で要確認**

## D. PSE 整理

- **充電器（ACアダプター）**: 菱形PSEが必要だが、**自社で充電器を売らず市販PSE済みアダプター運用なら、自社取得は不要**
- **電池そのもの**: 上記Cの通り、単電池400Wh/L以上でPSE対象。候補は境界付近のため実測要確認

## E. 誰がやるか（切り分け）

- **自分**: 技適済みモジュールの確認 / 電池書類の入手 / 誤飲・紐まわりの設計配慮 / 電池の体積エネルギー密度確認
- **専門家・試験機関**: ST試験の実施 / PSE該当性の最終判定 / IEC62133要否の回答
- **パートナー企業（AI抱き枕側）**: 抱き枕版の安全はパートナー(寝具メーカー)の品質・コンプラチームが主導（可燃・熱安全は寝具メーカーの本領）

## 参考

- 日本玩具協会 STマーク: https://www.toys.or.jp/jigyou_st_top.html
- 経産省 リチウムイオン電池PSE FAQ: https://www.meti.go.jp/policy/consumer/seian/denan/lithium_faq.html

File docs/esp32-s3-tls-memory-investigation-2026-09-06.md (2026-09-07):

# ESP32-S3 v0.5 TLSメモリ調査（2026-09-06）

対象: `devices/mcu/esp32_s3/toytalker_mini_v0.5/toytalker_mini_v0.5.ino`

## 修正・実機確認後の結論（同日追記）

相槌タスクのStringリーク修正を採用した。修正コミットは `0d1037a`（`Fix backchannel task String leak before task deletion`）。修正後、ユーザーの実機試験で従来の8〜10ターンを超えて会話を継続でき、報告された試験範囲ではTLS接続失敗が再発しなかった。相槌タスクのリークが主要因だった可能性が高い。

**TLSのPSRAM移行は見送り、リーク修正を適用した状態で通常使用を続ける。** 以下に残すPSRAM移行案は、再発時に検討できる未採用の回避策であり、現在のファームには入っていない。

### 採用した修正と検証

- 相槌取得処理を通常のヘルパー関数 `fetchBackchannel()` に分離した。
- ヘルパーから戻る際に `partial`・`charId`・`url`・`payload` を破棄し、その後タスク側で完了状態を更新して `vTaskDelete(NULL)` を呼ぶ。
- `[BC] Free heap after` は上記Stringの解放後に出力する。タスクスタック自体の回収完了を示すログではない。
- Arduinoコア3.3.10でファーム全体のコンパイル・リンクに成功。FQBN: `esp32:esp32:esp32s3:PSRAM=enabled,FlashSize=4M,PartitionScheme=huge_app`。Flash 1393435 bytes、静的RAM 50032 bytes。
- ユーザーが修正版を実機で試験。途中で約15ターンとの申告があり、その後も会話を継続して問題なしとの報告。正確な総ターン数は未計数。

### 提供されたスクリーンショットの計測値

すべて再生終了時の `[MEM]` 行。撮影時刻ごとの抜粋であり、連続する全ターンの記録ではない。

| 撮影時刻 | free (bytes) | max_blk (bytes) |
|---|---:|---:|
| 22:41:17 | 100080 | 34804 |
| 22:44:23 | 90332 | 31732 |
| 22:45:23 | 88804 | 31732 |
| 22:56:53 | 94704 | 31732 |

後半の最大連続ブロックは31732 bytesを維持し、freeも最後の抜粋では回復している。各画像で再生完了から録音への復帰が確認できた。ただし接続直前の `[DIAG] pre-connect` とは計測フェーズが異なり、以前の失敗時の約17KBと直接比較するものではない。全条件での解決や長時間の耐久性を保証する試験ではない。

最終画像の `underruns=13` は音声リングバッファが空になった記録。TLS接続失敗とは別の症状であり、これ自体はリーク継続の証拠ではない。音声供給の遅れの原因は未特定で、音切れが問題になる場合に別途調査する。

以下は修正前にまとめた調査記録。行番号と未実施事項は当時の状態を示し、採用状況・検証結果は上記追記を優先する。

## 当初の調査結論

Arduino IDEのまま回避できる有力な方法がある。インストール済みArduino ESP32コア3.3.10では、`mbedtls_platform_set_calloc_free()`でmbedTLSのアロケータを起動時に差し替え、PSRAMへ直接確保できる。SDK再ビルドもPlatformIO移行も不要。実機の改善効果は未検証だが、このAPIを使用する最小スケッチのコンパイルとリンクは成功した。

同時に、対象コードには相槌タスクのローカル`String`が解放されない問題がある。TLSのnew/deleteだけを原因とするのは早く、リーク修正も必要。

## 確認した環境と検証範囲

- ローカルArduino ESP32コア: `Arduino15/packages/esp32/hardware/esp32/3.3.10`
- ESP32-S3 SDK: `Arduino15/packages/esp32/tools/esp32s3-libs/3.3.10`
- SDKコンパイル定義: ESP-IDF v5.5.4、mbedTLSヘッダー: 3.6.5。
- `qio_qspi/include/sdkconfig.h`: `CONFIG_MBEDTLS_INTERNAL_MEM_ALLOC=1`、`CONFIG_MBEDTLS_SSL_MAX_CONTENT_LEN=16384`。
- `esp_config.h`: `MBEDTLS_PLATFORM_MEMORY`有効、標準calloc/freeはEspressif関数に設定されている。
- 実際の`libmbedcrypto.a`を付属`xtensa-esp32s3-elf-nm.exe`で調べ、`mbedtls_platform_set_calloc_free`の定義と`mbedtls_calloc`経由の参照を確認。
- Arduino IDE付属arduino-cli 1.5.1で最小スケッチをビルド。FQBN: `esp32:esp32:esp32s3:PSRAM=enabled,FlashSize=4M`。正常終了、Flash 540241 bytes、静的RAM 26348 bytes。
- 最小スケッチは`C:/Users/exodj/AppData/Local/Temp/toytalker_tls_psram_probe/toytalker_tls_psram_probe.ino`。hook設定、20KBのmbedTLS確保、外部RAM判定、`mbedtls_ssl_setup()`を含む。ネットワーク接続を行うものではない。
- 実機への書き込み、実機ログの取得、ファーム全体のビルドは実施していない。実機に現在書き込まれたコアの版は別途起動ログで照合すること。
- 対象inoには調査開始前から変更がある。今回の調査で対象inoは編集していない。

## 1. 第一候補: TLSのアロケータをPSRAMに変更

`heap_caps_malloc_extmem_enable(12288)`は通常mallocの振り分け方針を変える。一方、現行SDKのmbedTLS標準アロケータは次のように内部RAMを明示するため、その閾値では変更できない。

```cpp
heap_caps_calloc(n, size, MALLOC_CAP_INTERNAL | MALLOC_CAP_8BIT);
```

これは「TLSがハードウェア上PSRAMを使えない」という意味ではない。Espressif自身の外部RAM用設定も`MALLOC_CAP_SPIRAM | MALLOC_CAP_8BIT`を使用する。[ESP-IDF v5.5.4の実装](https://github.com/espressif/esp-idf/blob/v5.5.4/components/mbedtls/port/esp_mem.c)

今回のビルドでは実行時に関数ポインタを差し替えるAPIが利用できる。`CONFIG_MBEDTLS_CUSTOM_MEM_ALLOC`をスケッチでdefineする必要はない。[mbedTLS 3.6.5の実装](https://github.com/Mbed-TLS/mbedtls/blob/mbedtls-3.6.5/library/platform.c)

追加する関数:

```cpp
#include <esp_heap_caps.h>
#include <mbedtls/platform.h>

static void* tlsPsramCalloc(size_t n, size_t size) {
  return heap_caps_calloc(n, size, MALLOC_CAP_SPIRAM | MALLOC_CAP_8BIT);
}

static void tlsPsramFree(void* p) {
  heap_caps_free(p);
}
```

`setup()`のSerial初期化後、WiFi・HTTPS・WebSocketなどの開始前に一度だけ実行する:

```cpp
if (!psramFound()) {
  Serial.println("[TLS] PSRAM unavailable; initialization stopped");
  while (true) delay(1000);
}
int rc = mbedtls_platform_set_calloc_free(tlsPsramCalloc, tlsPsramFree);
if (rc != 0) {
  Serial.printf("[TLS] allocator setup failed: %d\n", rc);
  while (true) delay(1000);
}
```

注意点:

- mbedTLS全体の設定なので、LambdaだけでなくSonioxや相槌HTTPSにも適用される。接続のたびに切り替えず、起動時に設定して固定する。
- この例は内部RAMへフォールバックしない。大きなTLS確保が内部RAMへ戻ることを避け、PSRAM不足なら明確に失敗させるため。
- 確保はcallocでゼロ初期化し、解放は内部RAMにもPSRAMにも対応する`heap_caps_free`を使う。
- DMA用メモリ、WiFi内部構造、タスクスタック、通常のStringなどがすべてPSRAMに移るわけではない。
- quad PSRAMの帯域・容量を既存の音声リングバッファと共有するため、接続時間、音切れ、PSRAMの最大ブロックも実機で確認する。
- 将来コアを変更する際はAPIとビルド設定を再確認する。ここで実証したのはインストール済み3.3.10。

## 2. コード上のリーク: fetchBackchannelTask

該当箇所: 911〜1017行付近。

関数外側のスコープに`String partial`, `charId`, `url`, `payload`があり、そのスコープを抜ける前に`vTaskDelete(NULL)`を呼んでいる。タスク自己削除はC++の通常のreturnではなく、スタックを巻き戻してローカルオブジェクトのデストラクタを呼ぶ処理ではない。このため、各Stringがヒープに確保したバッファが残る。SSOに収まる短い文字列を除き、少なくともURLや通常のpayloadが該当する。

`HTTPClient http`は既に内側のブロックに置かれており、そのブロックを出るときに破棄される。しかし外側のStringは対象外。`[BC] Free heap after`も、これらがまだ生存している時点の計測。

対策は、HTTP処理だけでなく**ローカルStringを含む処理全体**を通常のヘルパー関数に移し、その関数から戻った後でタスクを終了すること。あるいは全体を内側のスコープで囲み、そのスコープを抜けた後に完了通知・`vTaskDelete`を行う。タスクエントリ自体をreturnさせない。

FreeRTOSはタスク自身が確保した任意のメモリを自動回収しない。タスク削除前にアプリ側で解放する必要がある。[ESP-IDF FreeRTOS](https://docs.espressif.com/projects/esp-idf/en/v5.5.4/esp32s3/api-reference/system/freertos_idf.html#deletion)

これが報告された8〜10ターンの失敗をどの程度説明するかは、修正前後の同一フェーズの計測が必要。リークにより内部RAMの穴が埋まり続けると、freeと最大ブロックの両方に影響し得る。

## 3. 断片化・ピーク使用量を増やす箇所

| 箇所 | 観察 | 対策 |
|---|---|---|
| 1034 / 1178行 | 相槌とLambda接続タスクを毎回16384 bytesのスタック付きで生成 | 常駐タスク＋通知/キューへ変更し、起動時に一度確保。スタック縮小はhigh-water mark実測後 |
| 1178 / 1200行 | タスク生成の戻り値を無視。生成失敗するとsent/failedが変わらず無限待ち | `pdPASS`確認、失敗時に既存エラー復帰経路へ。待ち時間を制限する場合はワーカーと引数の寿命も保証 |
| 1109〜1124行 | 相槌abortの待ち時間を過ぎてもタスクが残り得る。そのままabortフラグを戻す | 終了確認・所有権移譲を確実にする。稼働中タスクを強制削除して済ませない |
| 1145〜1173行 | `messagesJson`, `payload`, `req`に本文のコピーが重複し、関数終了まで生存 | 再利用バッファ、事前reserve、ヘッダーと本文の分割送信。ワーカーの送信終了を同期してから解放 |
| 436 / 175行 | 履歴をString代入でずらす。長寿命の文字列確保がTLSなどと混在 | 履歴をリング構造にし、上限を設けて容量を再利用。必要ならPSRAMの明示バッファへ |
| 862 / 1050行 | 音声変換用最大16KBなどを繰り返しmalloc/free | 起動時にPSRAMの作業領域を確保して再利用。並列利用しないことを確認 |
| 491〜519行 | 再生I2SのDMA設定は8×1024×stereo 16-bit、約32KBのデータ領域 | リングバッファがあるのでDMA深さを段階的に減らす比較実験。音切れ・アンダーランで評価 |
| 1238 / 1274行付近 | Lambdaが残っている間にSonioxのTLS接続を進める | 切り分けでは先行接続を一時無効化。製品ではTLSをPSRAMへ移して並列性を維持する案を優先 |
| 1265行以降 | 正常な受信終了後に明示的なclient.stopがなく、ドレイン・履歴追加・録音再開まで進む | 受信完了直後にstop。既に相手切断を検出してstop済みの場合は効果なしだが、解放時点を明確にできる |

16KBの一時音声バッファについて、通常mallocが実際にどちらのRAMを使うかはArduinoの閾値・空き状況による。「必ず内部RAM」とは断定できない。PSRAM明示＋再利用で予測可能にする。

タスク常駐化はスタックの反復確保をなくすが、常駐分のRAMは消費する。相槌とLambdaを直列化できるなら共通ネットワークワーカーも候補。

## 4. WiFiClientSecureの再利用だけでは不十分

現時点の対象inoは1175行のローカル`WiFiClientSecure client;`を使っている。明示的なnew/deleteという依頼文と少し異なるが、内部のSSLコンテキストは動的確保される。

Arduinoコア3.3.10の`NetworkClientSecure::stop()`は`stop_ssl_socket()`を呼び、そこから`mbedtls_ssl_free()`などでTLSリソースを解放する。したがってclientをstaticやグローバルにしても、切断・再接続時の大きなTLS確保はなくならない。少量のオブジェクト確保削減にはなるが主対策ではない。

また、約40KBというTLS接続全体の使用量と、1回のcallocに必要な連続サイズは区別する。16384 bytesのコンテンツにプロトコルの余裕分などが加わる。`max_blk=17KB`という丸めた値だけで特定の失敗確保サイズを断定しない。

## 5. 追加のメモリ破壊リスク

相槌PCM取得の980〜989行付近で、バッファを一度だけ倍増した後に、`avail`をそのまま`readBytes(pcm + totalRead, avail)`へ渡している。一度の拡張後も`avail > bufSize - totalRead`の場合、書き込みが領域を超える。今回のログで発生した証拠はないが、ヒープ破壊を断片化と取り違えないため、読み取り量を残容量で制限し、応答長の上限も検証する必要がある。

## 6. 実機検証の順番

1. 相槌タスクのStringリークを直し、同じ会話条件でベースラインと比較。
2. TLS PSRAM hookを有効化し、mbedTLSから確保した20KBが`esp_ptr_external_ram()`でtrueになることを確認。実際のTLS割り当て先も必要に応じてカウンタ等で検証。
3. 同一条件で最低50〜100ターン。会話履歴が満杯になった後、内部RAMとPSRAMのfreeが低下し続けないこと、接続失敗・音切れ・遅延を確認。
4. 通常終了、相槌タイムアウト、割り込み発話、ネットワーク切断を別々に確認。
5. まだ内部RAMの最大ブロックが低下するならタスク常駐化、音声作業バッファ固定化、履歴リング化を順に比較。

各ターンで内部RAMとPSRAMの`free / largest_free_block`を、相槌開始前、相槌のString破棄後、I2S切替前後、接続タスク生成前、TLS接続直前、TLS解放後、関数から戻った後の同じフェーズで計測する。自己削除したタスクのスタックはidleタスクによる回収待ちになる場合もある。

`heap_caps_register_failed_alloc_callback()`で失敗した要求のバイト数とcapsを記録すると、TLSなのか16KBスタックなのかを区別できる。コールバック内で動的確保や重いログ処理をせず、固定領域に記録して後で出力する。`heap_caps_check_integrity_all(true)`もフェーズ境界で用いてヒープ破壊を切り分ける。[Espressifのヒープ診断](https://docs.espressif.com/projects/esp-idf/en/stable/esp32s3/api-reference/system/heap_debug.html)

## 採用優先度の低い案

- `setBufferSizes()`は確認したNetworkClientSecureにはない。
- `.ino`で`CONFIG_MBEDTLS_EXTERNAL_MEM_ALLOC`やバッファ長のマクロだけを書き換えても、既にビルドされたSDKライブラリは変わらない。構造体の設定不整合にも注意。
- `client`のグローバル化だけ、接続失敗時の同じ状態での即時リトライだけでは原因を取り除けない。
- 任意の生きたC/C++オブジェクトを移動して内部ヒープを圧縮する汎用APIはない。寿命・確保先・ピーク使用量を管理する。
- keep-aliveは今回の解決策に依存させていない。接続ごとにTLSを作り直す構成で成立する対策。
- 同じモジュール/コア3.3.10で3.3.7との差を報告した[上流issue #12769](https://github.com/espressif/arduino-esp32/issues/12769)もあるが、別アプリの利用者報告であり、本件と同じ原因と確定したものではない。ダウングレードは追加比較候補にとどめる。

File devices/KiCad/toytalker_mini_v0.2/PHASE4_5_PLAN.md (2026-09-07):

# Phase 4/5 再開手順書（基板待ち中断用）

> ## ✅ 検証結果(2026-09-05夜、基板到着当日)
> **合格。** v0.5(=v0.4+ピン載せ替え)を2号機で実機検証: 短ターンでunderruns=0(bc=0)/1(bc=1)が安定、**指押さえでRSSI約7dB劣化してもunderruns不変** → v0.1の「押すと直る」グラウンド問題は根治。
> - **全5枚検査完了(9/6): 良品4枚(2〜5号機)、不良1枚(1号機のみマイク音響不良**=電気的には生きているが感度20dB級低い。X-ray警告が1/5で現実化)。1号機は充電・温度・スピーカー検証機として温存
> - 指押さえ追加実測(9/6): 押すとRSSI約14dB劣化(-64〜-68→-78〜-82)でもunderruns正常 → v0.1の「押すと直る」はRF不利下でも起きていた=グラウンド説の完全裏付け。基板内アンテナ成立(バッテリー重ねは未検証)
> - **v0.5にDC除去フィルタ追加**(SPH0645のDCオフセット≈-13500@16bitが声を埋めていた)。認識感度が体感で向上、v0.4/v0.1実機にも移植価値あり
> - **⚠️発見: メモリリーク 約10KB/ターン**(v0.4由来)。10ターン前後でheap<50KBとなりTLS接続不能→応答なしで録音に戻る。リセットで全回復。**展示(長時間連続会話)のリスク**なので v0.5 で要修正
> - 残タスク: 電池組立(ZH圧着)→バッテリー位置決め(アンテナ直下 vs ずらし)→スピーカー音量確認→Step 2b(温度2系統/VBAT/充電STAT/[STATS]拡張)

> **このファイルの役割: 「基板が届いたらここから再開」。** 2026-08-31にPCB待ちでアプリ開発へ切り替えたため、Phase 4/5の計画をここに退避。再開時はこのファイルをClaudeに読ませて「基板届いた」と言えばOK。
> 現状の正: 部品=PARTS_LIST.md / GPIO=PINMAP.md / 経緯=PARTS_AND_POWER.md / レイアウト記録=LAYOUT_PLAN.md

## 現状スナップショット（2026-08-31時点）

- **発注済み**: JLCPCB 5枚、注文番号 W2026083023483163（PCB=Y10-10808084A / PCBA=SMT026083061270）、$158.47
- 工場出荷予定 9/3、**到着見込み 9/5〜9/8頃**
- v0.2の使命: v0.1の「ESP32を指で押すと音途切れが直る」問題の根治（ビアファーム+ベタGND+アンテナ基板内蔵）

## ⚠️ 到着前でも対応が必要なもの（メール見張り）

JLCPCBから2種類のメールが来る可能性あり。**来たら早めに返答**（放置すると製造が止まる）:
1. **マイク実装レビュー結果** — SPH0645は実装難度High・X-ray検査対象。少額の追加費用を求められたら承認してよい
2. **実装前の配置確認** — コネクタ(J2/SP1)とマイク(MK1)の向きを重点チェック。EasyEDA系部品はプレビューで原点ズレして見える持病あり（発注時に手動補正済み。回転ズレの方が実害大）

## Phase 4: ファームv0.5（着荷前に書き始めてもよいが、実機テストはv0.2必須）

新ピンは全てv0.2基板前提なので、**v0.1実機では動作確認できない**（アプリ開発を優先した理由の一つ）。

やること:
1. **ピン定義の載せ替え** — PINMAP.mdの`#define`一式をそのまま使う（MIC=48/33/34, AMP=37/36/38/39, LED=40, BUTTON=35, VBAT_ADC=1, BOARD_TEMP=2, STAT1/2=13/14）
2. **温度2系統読み** — ESP32内部`temperatureRead()`とTH2(GPIO2の分圧)の両方を読み、差分を[STATS]へログ（自己発熱と基板温度の分離）
3. **電池残量ADC** — GPIO1、470k×2分圧なので実電圧=読み値×2。WiFi動作中はADC1のみ使用可（設計済みなのでコード側は普通に読むだけ）
4. **充電状態STAT1/2** — GPIO13/14、プルアップ済みオープンドレイン。充電停止推定=「STATが止まった＋VBATが満充電未満＋USB挿入中」→ TH1の温度保護が働いた可能性としてログ
5. **[STATS]拡張** — 既存のunderruns/rssiに加えvbat/temp2種/statを1行に追加

## Phase 5: v0.2実機検証

**合格ライン: 何も押さえずに underruns 0〜1**（v0.1ベースラインは途切れ時6、押さえて1）

手順:
1. 到着後の目視 — アンテナ領域の銅箔なし・切り欠き形状・コネクタ向き
2. 組立 — 電池ケーブルはZH化で**今回からスペック内圧着**（ZHR-2ハウジング+SZH-002T-P0.5、工具SN-03BM）。⚠️電池リードは必ず1本ずつ加工・露出端は絶縁してから次へ。スピーカーは付属MX1.25プラグが無加工で挿さるはず（初回は嵌合確認）
3. ファームv0.5書き込み → [STATS]計測（v0.1と同一場所で比較）
4. 指押さえテスト — 押さえても改善しない（=最初から良い）ことを確認
5. **バッテリー位置決定** — アンテナ直下貼付(RSSI約5dB劣化だがunderruns=0実績)か数mm避けるか、[STATS]見て決める
6. スピーカー音量 — アンプVDD=V_SYS化で最大約1.2W。歪む/うるさければソフト音量上限かGAINピン設定

## 済み・不要になったもの

- マイク代替選定 → **完了**。v0.3はSPH0655LM4H-1-8(1軍)/Goertek SD18OB261-060(2軍)の共通フットプリント方針。詳細はPARTS_AND_POWER.md「v0.3 マイク代替検討」
- PDMブレボ事前検証 → **不要と判断**（結果がどうあれPDM採用は変わらず、ファーム問題はv0.3実機で修正可能）

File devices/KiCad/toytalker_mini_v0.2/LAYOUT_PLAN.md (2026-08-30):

# v0.2 レイアウト設計書

## 0. 進捗ボード（2026-08-31: 発注完了🎉）

**発注記録**: 2026-08-31 00:48 / 注文 W2026083023483163 (PCB: Y10-10808084A, PCBA: SMT026083061270) / 5枚・2層1.0mm・片面実装 / 合計$158.47(送料$16.79) / 工場出荷予定9/3 / ステータス: レビュー中+Advanced option review(マイクの実装審査)
**待ちアクション**: JLCからのメール①マイク審査結果(追加費用なら承認) ②実装前配置確認(来たら向き再チェック)

### ✅ 済み
- [x] 配置 全部品QA合格(パスコン距離・熱源距離・重なり・基板端すべて✓)
- [x] ピン割当10本 回路図反映+機械検証(ERC 0/0)
- [x] 外形+左下切り欠き(閉じ検証済み)
- [x] ネットクラス3種(Power 0.6 / Power3V3 0.4 / Default 0.2)+ビア規格化(0.5/0.3, 電源0.6/0.3, 穴0.2問題解消)
- [x] 配線: **VBUS** / **VBAT**(裏ルート) / **V_SYS**(表ルート+U4玄関ネック) / CC1/CC2 / USBデータの根元交差 / J1周りGNDスティッチ

### ✅ 配線 全ネット完了(未配線ゼロ・実害DRCゼロ 2026-08-30 23:45)

(以下は完了済みの記録)
- [ ] VBATの相棒ビア×2箇所(U字橋方式)
- [ ] +3V3幹線: U2.5→C5→R14/R12/R13串刺し→x28.3北上→y16でx29.7ジョグ→上回廊→C6→U3.3
- [ ] +3V3枝: C8(→MK1.5) / R6(台帳C: 裏をy30で東進15mm)
- [ ] USBデータ続き: J1→ピン23/24。**V_SYS縦線との交差(22.5,28付近)でV_SYS側を2mm潜らせる改造**(そのとき声かけて)
- [ ] STAT1/2: U1.9/U1.3→R12/R13の信号パッド経由→ピン17/18(+3V3幹線の下をビアでくぐる×2 = 台帳E,F)
- [ ] ADC: R10/R11中点→y17-18帯→C10.1→ピン5 / TH2→C11.1→ピン6
- [ ] BOOT: S3.1→上回廊→ピン4
- [ ] PWR_EN: S1.2→R9→x20付近南下→U2.3
- [ ] ESP_EN: R6/C7→ピン45
- [ ] マイク3本: ピン28/29/30→MK1(平行ファン)
- [ ] アンプ4本+LED+BUTTON: 下辺ピン→S2東レーン→U4西面ファンアウト / R8.2 / R7
- [ ] OUT±: U4.A3/B3→東→南→SP1(0.3幅ペア)
- [ ] D1のGND側、その他の未配線をゼロに

### 🔧 Claude側TODO(次のエディタ閉じタイミング〜最終)
- [ ] U1の放熱穴12/13にGNDネット割当+11番パッドのベタ接続をソリッド化(DRCレガシー2件解消)
- [ ] **ビアファーム再追加**(U3直下3×3+アンテナ側スティッチ4本 — 広域削除で消えたため)
- [ ] TH1のGND側にサーマルビア1〜2個
- [ ] 浮きビア(via_dangling)掃除
- [ ] ベタGND最終調整(starved_thermal解消)+フルDRCゼロ
- [ ] 台帳最終化(B:V_SYS表ルート化で消滅/D:TH2北残留で消滅)

### 📋 発注前(Phase 3)
- [ ] 原寸紙テスト(1:1印刷+実物部品) / スピーカー耐入力vs1.2W / MSKペグ穴Φ0.8確認
- [ ] ガーバー出力→JLCPCBのDFMチェック→発注

> **このファイルの役割: 「何と何が繋がるか、どこに置くべきか」。** 手動配置のための地図。値はPARTS_LIST.md、GPIOはPINMAP.mdが正。
> 進め方: **①この流れを見て配置 → ②配置に合わせて最寄りピンを選ぶ → ③配線**（ピンは後決め。ESP32-S3はGPIOマトリクスでほぼ全信号を任意ピンに振れる）

## 1. 信号の流れ（これだけ見て配置できる版）

```
■ 電源の幹線(太線0.5〜0.6mm)
USB J1 ─VBUS→ C1 → U1充電IC ←VBAT→ C2 → J2電池
                     U1 ─V_SYS→ C3 → ┬→ C4 → U2 LDO → C5 ─+3V3→ みんなへ
                                     └→ C9 → U4アンプ(V_SYS直結)

■ 電源ON/OFF(細線でOK)
S1スイッチ ─PWR_EN→ U2のENピン   (R9=100kをPWR_EN-GND間のどこかに)

■ 音声出力(この順に一直線に置くと配線が素直)
U3 ══I2S 4本══> U4アンプ ──OUT± 2本──> SP1コネクタ → スピーカー

■ 音声入力
MK1マイク ══I2S 3本══> U3    (+3V3とC8がMK1のそばに必要)

■ 監視(全部細線・遅い信号)
J2のVBAT ── R10 ─┬─ R11 ── GND     ┬の点 → U3のADCピンへ (C10はピン側)
+3V3 ── R14 ─┬─ TH2 ── GND        ┬の点 → U3のADCピンへ (C11はピン側)
U1のSTAT1/2 ──→ U3へ2本            (R12/R13=100kで途中どこかから+3V3へ)

■ 操作・表示(細線)
S2ボタン ── R7 ── U3へ1本
S3ブート ── U3のGPIO0へ1本(固定)
U3から1本 ── R8 ── D1 LED ── GND

■ その他
J1のD+/D- ── U3のGPIO19/20へ2本(固定)
+3V3 ── R6 ─┬─ U3のENピン(右下角に固定)   C7も┬の点に
U1まわりの設定部品: R3(ILIM), R4(ISET), TH1(TSピン直結)
```

## 2. ピン割当 確定案（2026-08-30 配置実測から計算。承認待ち）

| 信号 | 旧 | 新 | 新ピンの物理位置 | 理由 |
|---|---|---|---|---|
| MIC_WS | GPIO5 | **IO33** | 左列 y25.75 | MK1へ西進4〜6mm、3本が平行で交差なし |
| MIC_DATA | GPIO9 | **IO34** | 左列 y26.6 | 〃 |
| MIC_BCLK | GPIO4 | **IO48** | 左列 y27.45 | 〃 |
| BUTTON | GPIO7 | **IO35** | 下辺 x32.82 | R7へ真下2.7mm |
| AMP_BCLK | GPIO10 | **IO36** | 下辺 x33.67 | S2東レーン→U4西面へ |
| AMP_WS | GPIO11 | **IO37** | 下辺 x34.52 | 〃 |
| AMP_DIN | GPIO12 | **IO38** | 下辺 x35.38 | 〃 |
| AMP_SD | GPIO6 | **IO39** | 下辺 x36.22 | 〃 |
| LED | GPIO8 | **IO40** | 下辺 x37.07 | アンプと同じS2東レーンで南下→R8の2番へ北から |

**変更なし**: GPIO0(BOOT)・GPIO1/2(ADC)・GPIO13/14(STAT)・GPIO19/20(USB)・EN。**回避継続**: GPIO3/IO26/IO45/IO46/TXD0/RXD0

## 3. 配置のルール（守らないと性能・製造に響くものだけ）

1. **パスコンは相棒ピンから2mm以内**: C6→U3の3V3ピン / C9→U4のVDD / C5→U2出口 / C4→U2入口 / C1,C2,C3→U1 / C8→MK1
2. **ADCは「コンデンサだけピン側、抵抗・サーミスタは源流側」**(C10/C11をU3の近くに)
3. **TH2は熱源(U3・U4)から遠く**、電池の近く
4. **アンテナ帯(x46.2〜52, y12〜29.5)**: 銅・部品・配線すべて禁止(設定済みキープアウト)
5. **裏面(B.Cu)はベタGNDの聖域**: 部品は置かない。裏面配線ジャンプはDC/低速のみ・短く・モジュール直下(x30.8〜51.8)に入れない・この文書の台帳に記録
6. **スピーカー円(中心41.75,41.75 r10)の内側**: 部品NG(音抜き穴と実物スピーカーの領域)
7. **基板端から銅0.5mm**、部品の専有領域(courtyard)は重ねない(0402同士は中心間1.9mm以上、0603は3.0mm以上)
8. 大電流ペアは短く: J2⇔U1、U4⇔SP1

## 4. アンカー（既決事項。動かすときは事前共有→OK後）

| 要素 | 位置 | 経緯 |
|---|---|---|
| U3 ESP32 | (41.3, 21.5) rot270 | アンテナ右辺内蔵 |
| J1 USB-C | 左上辺 | 筐体の充電口 |
| スピーカー円+穴 | 中心(41.75, 41.75) | 筐体 |
| J2電池+切り欠き | 下辺、切り欠きx25〜31 | 電池の線は右下出し |
| S1スイッチ | 左辺、ノブ外向き | 筐体の左側面操作 |
| ビアファーム(U3直下)+キープアウト | 設置済み | 触らない |

## 5. 全ルート表（2026-08-30 実測配置から計算。この表の通りに引けば詰まない）

前提の微調整(先にやる):
- [ ] TH2+R14を左下へ移動(TH2≈(16, 38.8)、R14その隣)。※温度を測る対象=電池の上へ。今の場所(モジュール左肩)はESP32の排熱を測ってしまう
- [ ] C9を(24.5, 37.1)へ(U4のV_SYSボールA2の真上2mm)
- [ ] S2を北へ0.4mm(S2東レーンの最狭部を1.8mmに広げる)
- [ ] R1/R2を西へ0.3mm(J1寄せ。x20.1〜21.3に南北レーンを作る)
- [ ] R8の向き: LED信号側パッドが**西**を向くように

### 幹線(先に引く)
| # | ネット | 幅 | ルート | 裏くぐり |
|---|---|---|---|---|
| 1 | VBUS | 0.5 | 済み | - |
| 2 | VBAT | 0.5 | J2(15,44)→ビア→**裏をx14.5で北上(J1の下)**→ビア(19,24)→C2→U1.BAT | 台帳A(約10mm) |
| 3 | V_SYS北 | 0.6 | U1.SYS(19.3,20)→C3→C4→U2.VIN(22.34,23.4)。S1.1(15.25,16.3)へは C3付近から北west枝0.4 | - |
| 4 | V_SYS南 | 0.5 | C4→ビア(23,26.5)→**裏をx23.5で南下**→ビア(23.8,37.2)→C9→U4.A2(北から進入) | 台帳B(約10mm) |
| 5 | +3V3幹 | 0.4 | U2.5→C5→R14/R12/R13の3V3パッド串刺し→x28.3北上→**y16でx29.7へジョグ**(C10/C11を回避)→上回廊(y12.7〜13.4)→東進→C6→U3.3V3ピン | - |

### +3V3の枝
| # | 行き先 | 幅 | ルート | 裏くぐり |
|---|---|---|---|---|
| 6 | C8→MK1.5 | 0.3 | C5からC8(26.5,26.4)へ南下→MK1の3V3パッド(27,28.5) | - |
| 7 | R6(ENプルアップ) | 0.25 | R13付近でタップ→ビア(30.4,25.3)→**裏: 南下+y30.0を東進x42.5まで**→ビア(42.5,30.1)→R6 | 台帳C(約15mm。マイク線とアンプ落下線の下を全部くぐる) |
| 8 | R12/R13プルアップ | - | 串刺し済み(幹線が通過) | - |
| 9 | R14(温度) | 0.2 | 移動後: C8付近タップ→ビア→**裏を南西へ**→ビア(16.5,37.5)→R14 | 台帳D(約12mm) |

### 信号
| # | ネット | ルート | 裏くぐり |
|---|---|---|---|
| 10 | USB D±(GPIO19/20) | J1(18.1,30.6/31.1)→**北東へ並走**→ピン23/24(31.77,21.5/22.35)。3V3幹線とは交差しない(幹線はx28.3でy18.6以北のみ)…※D±はy21〜31の対角線。**幹線がD±を横切る場合は幹線側がくぐる**→今回の経路では交差なし | 済(コネクタ根元の1回のみ) |
| 11 | STAT1/2 | U1.9/U1.3→東進y16.4/17.25→**+3V3幹線(x28.3)の手前でビア→裏1.5mm→ビア**→R12/R13の信号パッド経由→ピン17/18 | 台帳E,F(各1.5mm) |
| 12 | MIC 3本 | ピン28/29/30(31.3, y25.75/26.6/27.45)→西南西へ平行に→MK1.1/.6/.4。WS=IO33→(25.2,28.5) / DATA=IO34→(26.1,28.5) / BCLK=IO48→(27,29.3) | - |
| 13 | BUTTON | ピン31(32.82,28.5)→真下→R7→S2 | - |
| 14 | AMP 4本 | ピン32〜35(33.7〜36.2, 28.5)→南下→**S2東レーン(x32〜33.5)**→y42で西進→U4を南西から回り込みファンアウト(C1/C3=南から, B1/A1=西から, 0.15幅/0.15間隔) | - |
| 15 | LED | U3の36番パッド(37.07,28.5)→南下→S2東レーン(アンプ4本と並走、レーン幅2.7mm)→y36.2で西進→R8の2番パッドへ北から→R8の1番→D1→GNDビア | - |
| 16 | OUT± | U4.A3/B3(25,39.0/39.4)→東へ出て(x29.5〜31.7の袋小路)を南下→y41.5で西進→SP1(22.03,46.6/47.8)へ東から進入。2本並走0.3幅 | - |
| 17 | ADC1中点 | R10/R11(16,41)→R1/R2東レーン(x20.1〜21.3)を北上→y25から北東→C10西パッド(27.4,13)→東パッド→上回廊→ピン5 | - |
| 18 | ADC2中点 | R14移動後(16.5,38)→ADC1と並走北上→C11(27.4,15)→上回廊→ピン6 | - |
| 19 | BOOT | S3.1(26.05,14)→上回廊を東進→ピン4(42.17,14.5) | - |
| 20 | PWR_EN | S1.2(16.75,16.3)→R9タップ→U1の西脇(x16.5〜17.2)を南下→y25でR3/R4の下をくぐって東進→U2.3(22.34,25.33) ※全部表面 | - |
| 21 | ESP_EN | R6/C7→ピン45(44.72,28.5) 直結 | - |
| 22 | CC1/CC2 | 済み | - |

### 上回廊の車線割り(y12.6〜13.5、4本、0.15幅/0.15間隔)
北から: +3V3幹(y12.75) / ADC1(y13.05) / ADC2(y13.35) / BOOT(y13.35の南…実配線で微調整)。C6は回廊東端(x43.5)で幹線を受け止める。

## 6. 裏面ジャンプ台帳(確定版)

| # | 線 | 場所 | 長さ | 種別 |
|---|---|---|---|---|
| A | VBAT | x14.5, J1の下を北上 | 10mm | DC電源 |
| B | V_SYS南 | x23.5, y27→37 | 10mm | DC電源 |
| C | 3V3→R6 | (30.4,25)→y30を東進→(42.5,30) | 15mm | DCプルアップ |
| D | 3V3→R14 | 西南西へ | 12mm | DCプルアップ |
| E,F | STAT1/2 | x28付近, 幹線の下 | 各1.5mm | 低速信号 |
| G | LED | x27付近, D±の下 | 1.5mm | 低速信号 |
| (済) | USB D-交差 | コネクタ根元 | 1mm | 済み |

**全てx<31(モジュール外形の西)・アンテナ帯外。** モジュール直下(x30.8〜51.8)とアンテナ帯の裏面は無傷を維持。合計B面欠損≈52mm×0.2〜0.5幅 ≒ v0.1の無計画配線の1/10以下。

## 7. 手順

1. 保存 → Claudeがファイルから機械チェック(重なり・基板端・アンテナ帯・パスコン距離・通り道の幅)
2. 配置に合わせてピン割当を一緒に決定 → 回路図修正 + ERC/ネットリスト機械検証 + PINMAP.md更新
3. 配線(幹線→信号→ベタGND) → フルDRCゼロ → 原寸紙テスト → 発注

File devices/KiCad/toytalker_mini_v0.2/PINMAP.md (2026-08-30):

# ToyTalker Mini v0.2 ピンマップ

> **このファイルの役割: 「GPIOの正」。** ピン割当の唯一の基準+ファームv0.5用のdefine。ピンを変えたら必ずここを更新する。部品の値 → PARTS_LIST.md

v0.1からの変更点: I2Sマイク/アンプ分離、GPIO3(ストラップ)解放、電池残量ADC・充電STAT追加、ネット名誤記修正。

## v0.2 割当表（2026-08-30 配置最適化で改訂。旧v0.2案からの変更は★）

| 信号 | GPIO | v0.1 | 備考 |
|---|---|---|---|
| MIC_BCLK | **48** ★ | 4(共有) | I2S0(録音)。左列下段=マイクへ最短 |
| MIC_WS | **33** ★ | 3(共有) | |
| MIC_DATA | **34** ★ | 9 | SPH0645 DOUT |
| AMP_BCLK | **37** ★ | 4(共有) | I2S1(再生)。下辺=アンプへ南ルート(2026-08-30配線都合で36⇔37入替) |
| AMP_WS | **36** ★ | 3(共有) | |
| AMP_DIN | **38** ★ | 5 | MAX98357 DIN |
| AMP_SD | **39** ★ | 6 | アンプシャットダウン |
| LED | **40** ★ | 8 | R8→D1(S2東レーン経由) |
| BUTTON(S2) | **35** ★ | 7 | R7経由 |
| BOOT(S3) | **0** | 0 | ストラッピング(固定) |
| VBAT_ADC | **1** | — | ADC1_CH0(固定。WiFi中測定可はGPIO1〜10のみ) |
| BOARD_TEMP | **2** | — | ADC1_CH1(固定) |
| CHG_STAT1 | **13** | — | BQ25185 STAT1+100kプルアップ |
| CHG_STAT2 | **14** | — | BQ25185 STAT2+100kプルアップ |
| USB D-/D+ | 19/20 | 19/20 | USB-Serial/JTAG(固定) |
| (解放) | 3,4,5,6,7,8,9,10,11,12 | | 旧割当は全て未接続に。3はストラップ、他は将来用 |

**回避ピン**: GPIO3(ストラップ)/IO26(PSRAM CS)/IO45・46(ストラップ)/TXD0・RXD0(デバッグ温存)
※IO33〜48系はoctal PSRAM機(R8)制約の対象だが、本機N4R2(quad)は全て使用可(データシート確認済み)

## 制約検証(機械チェック済み)

- ✅ ストラップピン: GPIO0はBOOTボタン専用(正しい用途)。GPIO3は解放。GPIO45/46は未使用のまま
- ✅ VBAT_ADC=GPIO1、BOARD_TEMP=GPIO2はADC1系(GPIO1〜10)→ WiFi動作中も測定可能
- ✅ 新規使用の1,2,10,11,12,13,14はv0.1で全て未接続(PCBネットリストで確認。GPIO2は2026-08-19追加)
- ✅ GPIO19/20(USB)・GPIO43/44(UART0、将来のデバッグ用)は温存
- ⚠️ IO26/IO33〜37は内蔵PSRAM/フラッシュとの兼ね合いがあるため今回は使わない(全て回避済み)

## ファームv0.5側の対応(Phase 4)

```cpp
// v0.2基板 (2026-08-30 配置最適化ピン)
#define PIN_MIC_BCLK 48
#define PIN_MIC_WS   33
#define PIN_MIC_DATA 34
#define PIN_AMP_BCLK 37
#define PIN_AMP_WS   36
#define PIN_AMP_DIN  38
#define PIN_AMP_SD   39
#define PIN_LED      40
#define PIN_BUTTON   35
#define PIN_VBAT_ADC 1
#define PIN_BOARD_TEMP 2
#define PIN_CHG_STAT1 13
#define PIN_CHG_STAT2 14
```

## ファームv0.5メモ(2026-08-30)
- 温度は2系統読む: `temperatureRead()`(ESP32内蔵=チップ温度) と TH2(GPIO2=基板温度)。差分もログ(大=CPU負荷、両方高=環境が暑い)
- TH1はハードウェア専用(ファームから読めない)。充電停止の推理: STAT=停止 かつ VBAT_ADC=満充電未満 かつ USB挿入 → 温度保護の可能性大

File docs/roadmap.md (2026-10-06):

# ロードマップ: 残りの作業と順番

「残っていること全部」の入口。順番と、誰の手が要るかだけを持つ。各項目の中身・経緯・手順は右端の文書へ。終わった行は消さず「済（日付）」にし、全部済んだらこの文書を消す。着手しないと決めた項目はここに書かず [先送り項目](deferred-items.md) へ。

## 方針（2026-10-07合意）

- 書いてあることを順に全部終わらせる。優先度の議論はしない。
- Claudeだけで進められる部分は、ユーザーの手待ち（アカウント作成・実機確認など）の間に先へ進める。各セッションの冒頭で「このセッションでユーザーにやってもらうこと」を先に列挙する。
- 本番影響の操作は説明→OKの原則どおり。同種の操作をまとめて1回のOKで進めてよいかは、その場で聞く。

## 順番

| 順 | 項目 | Claudeだけで | ユーザーが要る | 状態 | 詳細 |
|---|---|---|---|---|---|
| 1 | 命名の決定 | 案を出す | 最終OK | 推奨案あり（下記）、未確定 | [複数アカウント計画](multi-account-iac-plan.md) の「命名の見直し」 |
| 2 | STGアカウント作成 → `cdk bootstrap` → SSM投入 → `cdk deploy` → マスターデータ投入 | bootstrap以降 | Organizationsでアカウント作成、SSM投入のOK | 未着手 | [CDK引き継ぎ](handoff-cdk-infra-2026-09.md)、[infra/README](../infra/README.md) |
| 3 | CloudFront固定ドメイン（`api-stg.zakicorp.com` 等）とアプリ・ESP32の接続先切替 | CDK・アプリ・ファーム | Cloudflare DNS追加、実機確認 | 未着手 | [複数アカウント計画](multi-account-iac-plan.md) |
| 4 | 認証（Cognito + Google / Sign in with Apple）→ 前払いポイント制 | CDK・Lambda・アプリ | Google Cloud / Apple Developer側の設定、実機確認 | 設計メモあり、未着手 | [先送り項目](deferred-items.md) の「ユーザー認証」、[原価と課金](pricing-and-cost-model.md) 第11節 |
| 5 | Cartesia 429時のずんだもんフォールバック、ZakiCorp TTS待ち行列の可視化 | 全部 | 実機確認 | 仕様あり、未着手 | [TTSフォールバック](tts-fallback-and-notifications.md)、[先送り項目](deferred-items.md) の「待ち行列の可視化」 |
| 6 | ESP32: 検索後の誤停止対策、OTA検証3件（電源断・SHA改ざん・ロールバック）、`stable` 発行、配布機のUSB書き込み、アプリの版表示と `fw_channel` 切替 | コード | 実機・S3操作・USB書き込み | 誤停止は原因仮説のみ・対策未合意 | [OTA引き継ぎ](handoff-esp32-ota-2026-09-16.md) |
| 7 | RnDの改名 → 自分用本番（CMK込み）→ DG向け本番 → GitHub Actions + OIDC | 大半 | アカウント作成×2、実機確認 | 未着手。3の後 | [CDK引き継ぎ](handoff-cdk-infra-2026-09.md) |
| 8 | 小物: v1残骸の削除（旧ロール・旧Lambda 2本・API Gateway・孤立ロググループ）、`toytalker-firmware` のCDK取り込み、Soniox Lambda 128→256MB、`.local/tts-service/` へ supervisor.py 反映 | 全部 | 削除のOK | 未着手 | [CDK引き継ぎ](handoff-cdk-infra-2026-09.md) の「判断待ち」 |

並べた理由: 1は2以降の名前の前提。4〜6は2〜3と独立なので、ユーザーの手待ちの間にClaudeが進められる。7は本番なので最後。

## 1の推奨案（確定したらここを「決定」に書き換え、計画メモの節も更新する）

- 計画メモの「名前の案」をそのまま採用する（`toytalker-<env>-<機能>-<相手>`、例 `toytalker-stg-chat-app`）。
- **DynamoDBのキー名（`owner_id#device_id` 等）は変えない。** 変えるとデータ移行とコード全面修正が入り、環境名を付ける目的とは無関係。
- 未ログイン端末の扱い（4で必要: ログイン必須かゲスト継続か）は4の着手時に決める。

## 済

- 秘密の実行時取得（2026-10-06）。Lambda 8本がSSMから鍵を読む。[CDK引き継ぎ](handoff-cdk-infra-2026-09.md)

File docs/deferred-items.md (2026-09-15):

# 意図的に先送りしている項目

コードから読み取れない「やらないと決めた理由」と、着手時の設計メモ。着手したらここから消す。

## 読み上げモード（`toytalker-tts-only-lambda` / `app/components/ReadAloud.tsx`）
- 長文分割: 単一TTS呼び出しのみ。OpenAIの4096字などプロバイダー上限を超えるとエラーがそのままアプリに出る。
- 日英分割読み: 単一ボイスで一括読み。
- Androidのバックグラウンド再生: フォアグラウンドサービスが必要。現状アプリはiOSのみ提供。
- iOSのバックグラウンド再生は `app.json` に `UIBackgroundModes: ["audio"]` を追加済みだが、EASのネイティブ再ビルドが必要でOTA更新では反映されない。

## ユーザー認証
- 現状の `owner_id` はアプリ初回起動時のランダムUUIDで、認証なし。iOSはキーチェーンに保存、Androidはアンインストールで消える（許容済み）。
- 本格認証はCognito + Sign in with Appleを想定。実装時はJWT検証をLambda内のJWKSキャッシュでローカル完結させ、音声パイプラインにネットワーク認証を挟まない（会話レイテンシ維持）。既存 `owner_id` のデータは初回ログイン時にアカウントへ紐付け移行する。
- いまの見え方の制御は「クライアントが送る `owner_id` を信用する」方式。公開一覧は `owner_id` 付きの行を除外し、カスタムボイス（ZakiCorp / Cartesia）の一覧・作成・削除・合成は本人確認なし。他の利用者には見えないが守ってはいない（IDが推測できない長さであることだけが壁）。
- 導入時の原則は **Lambdaがクライアントの `owner_id` ではなく検証済みトークンの本人IDを使う**。これで一覧・作成・削除・合成のすべてが本人に限定され、クローン機能の作りはそのまま活きる。決めておく点は次の4つ。
  1. `owner_id` は内部IDのまま残し、`sub → owner_id` の対応表（例: `toytalker-users`）を1つ持つ。初回ログイン時に端末の `owner_id` を紐づければデータ移行が要らない。未ログイン端末の扱い（ログイン必須かゲスト継続か）は導入時に決める。
  2. ESP32はログインしない。本体は `device_id` だけ送り、Lambdaが `toytalker-devices` からオーナーを引く現在の方式を維持。代わりにデバイス登録をログイン必須にする。
  3. トークン検証は本文Lambdaの中で行う（Function URLのストリーミング構成を崩さない）。JWKSはLambdaでキャッシュ。相槌・Soniox一時キー発行なども同じ検証関数を共通化。CloudFrontは静的配信・WAF等の目的があれば別途で、認証の必須要素ではない。
  4. 本文・読み上げLambdaで、キャラクターとボイスの `owner_id` がトークンの本人（またはシステム）と一致するかを確認する。デバイス経由はデバイスのオーナーとキャラクターのオーナーの一致を確認。
- 影響範囲: デバイス設定Lambda（`/voices` `/custom-voices` `/characters` `/devices` `/usage`）、本文・読み上げ・相槌Lambda、アプリ（ログイン画面・トークン付与・初回紐づけ）。ESP32ファームは変更なし。

## ESP32 本文開始の高速化（2026-09-10の検討、[v0.7記録](esp32-v07-aec.md)）
- 19:02の実機画像では `sendToLambdaAndPlay()` 開始から最初の本文テキストまで2,239ms、TTSヘッダー2,282ms、8KB読了2,370ms、I2S書き込み2,502ms。相槌待ち・端末準備・TLS・サーバー処理を含む値で、サーバー時間そのものではない。
- 実装したのは「相槌の再生予定を本文要求の `backchannel_fired` に正しく反映する」修正だけ。
- **保留: 相槌取得待ちと本文要求の並行化。** 現在は相槌取得タスクの終了を待ってから本文の接続・要求を始める。並行化は相槌自体の取得速度や負荷に影響し得るため後回し。着手するなら先に `BC wait done` の経過時間を複数ターンで測り、ほぼゼロなら対象をサーバー側へ移す。相槌タスクの履歴・文字列・PCMの寿命と、遅着した前ターン結果の再生防止が必要。
- **保留: 本文プリバッファ32KBの縮小。** 初回だけ16KBにすると8KB読み込み1回で開始できるが、ユーザー希望で32KBを維持。音切れ再発と比較してから。
- その他の候補: Lambdaの設定取得（voice・LLM）の並行化、最初の文とTTS準備の見直し。AECをCore 0へ移す・毎ターン初期化をやめる案は、移すだけでは改善しない可能性があり初手にしない。

## TTS音声の逐次中継（2026-09-11の調査、コード変更なし）
- 本文Lambda（App / ESP32）はTTSプロバイダーからの音声を `arrayBuffer()` でブロック全体受信してから端末へ送っている。到着分を順次渡せば再生開始を早められる可能性があるが、ESP32のサイズ先行通知、ブロック全体を対象にした無音処理、Appのbase64送信との整合が要る。効果は未計測。
- ログの `tts_first_byte` マークはTTS呼び出し前に記録されており、初回音声到着時刻ではない。初回音声の評価に使わない。
- ElevenLabsの同時実行枠はHTTPでは各要求が数えられ、WebSocketは生成中のみ。分割を細かくすると先頭は早いが合計時間と要求数は増える。着手時は現行方式を計測してから、逐次中継・ブロック長・WebSocketを個別に比較する。

## アプリの通信失敗の診断記録（2026-09-10のXHRエラー、原因未確定）
- 9/10朝、PCの計画再起動後にアプリで「XHR error」が出た件。ずんだもんでも出たためPC上のTTS停止だけでは説明できず、根本原因は未確定。同日のPC再起動対策（[Windows更新](windows-update-restart-control.md)）とログオン不要のTTS起動（[起動・復旧](tts-boot-recovery.md)）は実装済み。
- 未実装: `xhr.onerror` は画面のログに固定文言を足すだけで、経過時間・受信済み量・HTTP状態を残さず、履歴再読込で消える。改修するなら、送信前に要求IDを発行し、送信開始・応答開始・初回音声・完了・再生完了・失敗を端末内に永続保存してから送信し、LambdaのRequest IDと照合できるようにする。DynamoDBの会話テキストがあることは音声の生成・受信・再生の成功を意味しない。

## ZakiCorp TTS 待ち行列の可視化（2026-09-13の検討、コード変更なし）
- 本番は同時16件構成で、17件目以降は `batch_engine.py` の待ち行列に入る。待ちが発生しても音声は壊れないが、待ち行列の長さと待ち時間はログにも `/health` にも出ておらず、混み始めたことに気づく手段が無い。
- 案: `/health` に `queue_length`（待ち中の要求数）と `max_wait_ms`（直近の最大待ち時間）を出し、監視タスク（`tools/tts-service/supervisor.py`）が閾値超えを記録する。内側からの `/health` のみ（公開側は `status` だけを返す仕様を維持）。
- 待ちが常態化したら `.env` の `TTS_BATCH_CLASSES` を `1,2,4,8,16,32` に戻す（VRAM約19GB）。48件構成は未実装・未計測で、見込みは [バッチエンジンの文書](qwen3-tts-batch-engine-2026-09-12.md) 第3版。

## Lambda初期化の短縮（2026-09-15の検討、コード変更なし。[複数アカウント計画](multi-account-iac-plan.md)）
- 温め（EventBridge 5分ごと + 実リクエスト中の予備インスタンス温め）が効いていて、実リクエストのコールドスタートは7日で10件未満。初期化約400msはユーザーに届いていないため、短縮は優先度が低い。
- **却下: `openai` パッケージの遅延読み込み。** 温めpingは `openai` を読まないので、温まった後の最初の実リクエストが読み込み代を払うことになり、今より悪化する。
- **却下: `openai` を外して `fetch` 直叩き。** ストリーミングとツール呼び出しの解析を書き直す危険の割に、温まった状態の応答は速くならない。
- **却下: Provisioned Concurrency。** 温めで同じ効果が出ている。月数千円/関数の固定費だけ増える。SnapStartはNode.js非対応。
- arm64とAWS SDKのtree-shaking同梱はCDK化のときに入れる（効果は小さいが手間もゼロ）。

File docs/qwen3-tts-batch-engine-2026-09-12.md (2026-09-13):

# Qwen3-TTS バッチ推論エンジンの実装と検証（2026-09-12）

**要求ごとに独立したKV行を持つバッチ推論を実装し、HTTP経由の同時16件で総音声生成倍率20.95倍、初回PCM p95 0.84秒、模擬再生枯渇0件を確認した。** 現行実装は同時16件で約3.1倍・初回PCM p95 33.6秒・全件枯渇だった。数値は本番プロセスが同じGPUに常駐（アイドル）した状態の測定で、本番への適用はまだ行っていない。聴取と音声認識による内容確認は未実施。

## 実装

`tts-models/faster-qwen3-tts/` に追加。元の `api_server.py`・インストール済みライブラリは変更していない。

| ファイル | 役割 |
|---|---|
| `batch_engine.py` | 推論エンジン本体。1本のワーカースレッドが全要求を1ステップずつ進める |
| `api_server_batch.py` | `api_server.py` と同じHTTP契約（`/health`、`/v1/tts/stream`、`/v1/speakers/*`）のバッチ版サーバー |
| `benchmarks/concurrency/batch_selftest.py` | HTTPなしの自己検証（隠れ状態の一致、同一seed比較、別話者同時、同一文バースト） |
| `benchmarks/concurrency/batch_step_bench.py` | 実装前の見込み計測（下記「設計の根拠となった事前計測」） |

設計の要点:

- **KVキャッシュは `[最大同時数, heads, 2048, dim]` の共有バッファで、要求ごとに1行を占有する。** 元実装の「サーバーに1つのStaticCache」を置き換え、同時要求が互いの文脈を上書きする問題（[現状まとめ](qwen3-tts-current-status.md)）を構造的に解消する。
- **全行が同じキャッシュ位置 `g` に書き込む。** 要求ごとの参加時刻の差は、行ごとのattentionマスク（自分のprefill以降だけを見る）とRoPE位置（`prefill_len + step + rope_delta`）で表す。transformersのStaticCacheはバッチ全体で1つの `cache_position` しか受け付けないため、この方式にした。`g` が末尾に近づいたら全行を前へ詰める（relocation）。
- **バッチ数1/2/4/8/16のCUDA graphを起動時に捕捉し、活動中の行数以上で最小のものを使う。** 各クラスのStaticCacheは共有バッファのviewを指すので、クラス切替時にKVのコピーは不要。行が完了したら末尾の行を詰めて連続に保つ。
- 予測器（15コードブック）もバッチ数別のgraph。波形デコーダーは同じステップでチャンクを出す行をまとめて1回で復号する（左文脈25フレーム＋新規4フレーム、元実装と同じ窓）。
- 1ステップの手順（予測器→埋め込み和→talker→codec head→反復ペナルティ→サンプリング→EOS/最大長判定）は `fast_generate_streaming` を行単位で再現。反復ペナルティは語彙マスク方式（下記の事前計測で元実装と厳密一致を確認済み）。
- HTTP側は要求ごとの `asyncio.Queue` から音声を受け取るだけ。推論はイベントループを占有しないので、受付・health・切断の応答性も改善する。クライアント切断時は次のステップで行を解放する。
- 制約: x-vector話者のみ（ICL方式の `ref_code` は非対応、本番はx-vectorのみ使用）。prefill長は128トークン以下、本文は1024トークン以下、生成は958ステップ（約77秒）以下。

## 設計の根拠となった事前計測（2026-09-12、元実装での測定）

バッチ化と第2版の最適化箇所を決めた計測。数値は元実装（`api_server.py`、1件ずつ処理）で測ったもので、詳細ログは `benchmarks/concurrency/results/`（Git対象外）にある。

**バッチ推論の見込み（`batch_step_bench.py`、cache長2048）。** talkerと予測器のCUDA graphをバッチ次元Nで捕捉し直し、1ステップ時間を測った。N=1で19.9msのステップがN=8で27.9ms、N=16で38.3ms、N=32で52.1ms、N=48で66.0ms。1件あたり実時間比はN=16で1.58倍、N=24で1.30倍、N=32で1.06倍、N=48で0.80倍と実時間を下回る。N=8以降はtalker部分が1件あたり約0.9ms、波形復号が約3.1msずつ線形に増え、この2つが上限を決める。同時クラスを32で打ち止めにしたのはこの結果による。N=16でtalker部分が伸び始める要因としてcache長2048への注意計算を挙げていたが、第2版のcache長1024で実際に短縮した（N=16 38.3→29.2ms）。

**GPU時系列（torch.profiler）。** 単独生成でトークン生成区間はGPU活動80%、波形変換区間は15%。波形変換区間にはcudaLaunchKernelが22,631回記録され、小さなカーネル起動で埋まっていた。これが第2版で波形デコーダーをCUDA graph化した動機。トークン生成区間では `apply_repetition_penalty` の `token_history.unique()` が毎ステップ（94回）呼ばれ、`aten::_unique2` と `aten::item` のCPU区間が各666msあった。ただしこれらはGPU処理と重なっているため、消せば同じ時間が短縮するわけではない。GPU活動の割合はSM飽和率や帯域使用率ではないので、「余力34%」のような換算はしない。

**反復ペナルティのマスク方式。** `unique()` を語彙サイズ固定のboolマスクへ置き換えた。CPU/CUDA、float32/bfloat16、logitsの2形状、履歴長0/1/94/2048、penalty 1/1.05/1.5の96条件で元実装と厳密一致（許容誤差0、NaN同士は一致扱い、正・負・ゼロ・無限大・NaNのlogitsと重複履歴を含む）。単独逐次のABBA比較20件で同一seedの波形SHA256が5ブロックすべて一致し、モデル生成時間は約1.2%短縮。効果は小さいが、音声を変えない置き換えとしてバッチ版に採用した。

**波形変換の間隔（chunk_size）。** 4を8/12に広げると処理量は8.7%/13.2%増えるが、初回PCMは平均0.22秒/0.35秒遅くなる。ユーザーが4/8/12の音声を聴取し違和感なしと報告。先頭だけ小さくする可変チャンク（先頭6チャンクは4、以後8）は処理量7.2%増・初回0.079秒増で、既存APIが末尾フェード用に1チャンク保留するため先頭2チャンクだけでは初回が速くならない。いずれもバッチ化で論点ごと置き換わったため不採用。

## 検証

### 隠れ状態の一致（ライブラリのgraph対自作graph、同一入力）

実際の生成で記録したtalker入力40ステップ分を、元のTalkerGraphと自作エンジンのバッチ1 graphの両方に流し、出力の最大差を比較した。

| 項目 | 値 |
|---|---:|
| 自作との最大差（40ステップ） | 0.14〜0.5 |
| 出力の最大絶対値 | 23〜51 |
| 対照（prefill文脈を見せない誤った設定） | 18〜48 |

差はbf16の1〜2ulp相当で、KV行・マスク・位置の扱いが元実装と数値的に同等であることを示す。同じseedでのトークン列の完全一致は、サンプリングが微小差で分岐するため確認できなかった（1〜3フレーム目で分岐）。

### HTTPなしの自己検証（`batch-selftest-20260912-234431` 以降）

- 別文・別話者8件同時（vivian/seiko/zackey、12〜113文字）: 8/8完了、初回チャンク0.36秒、音声長は文字数に比例（12文字→2.0秒、41文字→7.7秒、113文字→19.6秒）。
- 同一文8件バースト: 59.9秒分を3.91秒で生成（15.3倍）、各要求の完了3.3〜3.9秒。
- 直後の単独1件: 初回チャンク0.14秒、3.19倍。
- ストリーミングで送った合計サンプル数は全体復号と一致（1フレーム=1,920サンプル、末尾補正不要）。

### HTTP経由の同時要求（`api_server_batch.py`、localhost:8001）

既存クライアント `run.py --capacity --save-audio --case short`、同じ41文字、vivian、ウォームアップ1件、期限120秒。本番8000番は停止せずアイドルのまま同じGPUに常駐。

| 同時数 | 成功 | 初回PCM p50 | 初回PCM p95 | 完了 p95 | 総音声生成倍率 | 枯渇があった要求 |
|---:|---:|---:|---:|---:|---:|---:|
| 1 | 10/10 | 0.247秒 | 0.269秒 | 2.95秒 | 3.28倍 | 0/10 |
| 2 | 10/10 | 0.309秒 | 0.366秒 | 3.45秒 | 5.39倍 | 0/10 |
| 4 | 20/20 | 0.377秒 | 0.419秒 | 3.11秒 | 9.42倍 | 0/20 |
| 8 | 40/40 | 0.496秒 | 0.527秒 | 3.91秒 | 15.45倍 | 0/40 |
| 16 | 48/48 | 0.795秒 | 0.837秒 | 5.38秒 | 20.95倍 | 0/48 |

現行実装（[4〜32件測定](qwen3-tts-capacity-2026-09-12.md)）は4件で3.15倍・初回p95 4.12秒・12/12枯渇、16件で3.12倍・初回p95 33.6秒だった。単独の初回PCMも0.75秒→0.25秒に短くなっている（推論がイベントループを塞がなくなったため）。

別文・別話者8件をHTTPで同時送信した結果も8/8完了、初回0.54秒、合計63.3秒分を7.68秒で受信（`results/batch-http-20260912/mixed-*.wav`）。

結果ディレクトリ: `20260912T145338_616630Z`（1件）、`20260912T145426_652308Z`（2件）、`20260912T145455_160559Z`（4件）、`20260912T145525_178332Z`（8件）、`20260912T145559_719031Z`（16件）。各先頭バーストのWAVを保存。

### 本番適用後の確認（2026-09-13、ngrok公開URL経由）

10:27にユーザー指示で本番を `api_server_batch.py` へ切り替え（[手順](tts-boot-recovery.md)）。切替後、公開URL経由で同じ試験を実施。

| 同時数 | 成功 | 初回PCM p50 | 初回PCM p95 | 総音声生成倍率 | 枯渇があった要求 |
|---:|---:|---:|---:|---:|---:|
| 1 | 5/5 | 0.321秒 | 0.369秒 | 3.06倍 | 0/5 |
| 4 | 12/12 | 0.503秒 | 0.542秒 | 6.75倍 | 0/12 |
| 8 | 24/24 | 0.621秒 | 0.632秒 | 14.75倍 | 0/24 |

ngrok経由のため初回PCMはlocalhostより約0.1秒遅い。別話者8件同時も8/8完了、初回0.69秒（`results/prod-batch-20260913/mixed-*.wav`）。

4件の生成倍率6.75倍は、`measure-001-00` が41文字に対して28.32秒を生成した1件（受信は正常、枯渇なし）で全件完了時間が伸びたため。この要求は他3件の完了後に単独で走り続けた。切り分けとして次を確認した。

- バッチ版の全要求229件（8001番128件、本番41件、本番の単独60件）のうち12秒超はこの1件のみ。単独60件は6.64〜8.56秒に収まった。
- 同時実行の構造が1行の計算を変えないことを直接検証した（`batch_selftest.py --parity-only`、`concurrency_parity`）。同じ入力に対して、他の行が動いていてもその行の出力は単独時と**完全一致（差0）**、行の移動（compaction）後も差0。バッチ4用graphとバッチ1用graphの間には、bf16の行列演算カーネルの丸め順序の違いによる差（現実の入力40ステップで最大3.2、中央値1.1、出力の絶対値20〜50に対して）があるが、これは他の行の有無によらない固定的な数値差で、構造的誤り（対照: 差30）とは区別できる。
- 実装の差として、prefill直後に得た最初のトークンが反復ペナルティの履歴に入っていなかった点を修正した（元実装は最初のステップからペナルティ対象にする）。10:40に本番を再起動して反映済み。

以上から、28秒の1件は同時実行による干渉ではなく、サンプリングで稀に生成が伸びる現象（元実装の単独でもseedにより10秒になる例あり）が第一候補。発生率は低く（229件中1件）、原因確定には音声認識付きの長時間観測が要る。

### 未確認

- 聴取による内容確認（繰り返し・抜け・声の混入がないか）。自動検出（メルスペクトログラム自己相似）では0.25〜0.3秒の短い反復候補が別話者8件中3件にあるが、元実装の単独音声にも同程度出るので判定材料にしない。音声認識による本文照合が必要。
- 長時間運用（relocationの発生、行の解放漏れ、メモリ）、クライアント切断、話者登録エンドポイント、本番と同じngrok経由の遅延。
- 本番プロセスを停止した単独占有での性能。今回は本番がアイドルで常駐した状態。

## 実行方法

```powershell
$env:PORT='8001'; $env:TTS_BATCH_CLASSES='1,2,4,8,16'; $env:TTS_MAX_SEQ_LEN='2048'
$env:ZAKICORP_API_KEY='<キー>'; $env:PYTHONIOENCODING='utf-8'
python api_server_batch.py
```

起動時にモデル読込約10秒、graph捕捉と波形デコーダー確認約4秒。VRAMは本プロセスで約9GiB（最大同時16、cache長2048）。

自己検証:

```powershell
python benchmarks/concurrency/batch_selftest.py --out benchmarks/concurrency/results/batch-selftest-<日時> --classes 1,2,4,8,16 --burst 8
```

本番へ適用する場合は、監視タスク（`tools/tts-service/supervisor.py`）が起動するスクリプトを `api_server.py` から `api_server_batch.py` へ切り替える必要がある。今回は切り替えていない。適用前に聴取・音声認識照合・切断試験を行う。

## 第2版（2026-09-13 昼）：キャッシュ長1024・波形復号のCUDA graph・同時32件・長文分割

本番適用後の追加検証と改善。ngrok経由の本番で同時16件 32/32成功・初回PCM p95 0.99秒・枯渇0、クライアント切断3件は1秒以内に行を解放（完了件数は増えない）を確認した上で、次の3点を実装した。

| 変更 | 根拠となる計測 |
|---|---|
| static cache長を2048→1024（`TTS_MAX_SEQ_LEN` 既定値） | 1ステップ時間 N=1 19.9→17.5ms、N=16 38.3→29.2ms、N=32 52.1→36.6ms（`batch_step_bench.py --max-seq-len 1024`）。1行あたりVRAMも235→118MB |
| 波形デコーダー（`speech_tokenizer.model.decoder`）を定常窓29フレーム・クラス別にCUDA graph化 | 出力は逐次実行と完全一致（差0）。n=1 15.5→3.7ms、n=4 20→9ms、n=8 33→22ms、n=16 57→45ms、n=32 104→91ms（`codec_graph_bench.py`）。起動時に逐次実行と照合し、差があれば自動で無効化 |
| クラスに32を追加（`TTS_BATCH_CLASSES` 既定 `1,2,4,8,16,32`） | 上記2点で同時32件でも各要求が実時間の約1.3倍以上を保つ見込み |
| 長文をサーバー側で文末分割（`TTS_SEGMENT_CHARS`=120、先行4分割まで並列、分割間120ms） | cache長1024では1要求の生成が446フレーム（約36秒）までになる。読み上げLambdaは全文を1要求で送るため、文末で分けて同じ応答に順に流す。分割境界は30msフェード＋120ms無音 |

分割は `split_text()` で、文末（。！？!?改行）で切り、120文字を超える一文は読点か120文字で切る。テストケース4種と300文字の一文・改行混在で欠落なしを確認。

### 8001番での再検証（本番8000番はアイドルで常駐、同じGPU）

`batch_selftest.py --classes 1,2,4,8,16,32 --max-seq-len 1024 --burst 16`: 隠れ状態の一致・行独立性の検査は第1版と同じ結果。別話者8件 9.77倍（第1版8.14倍）、同一文16件バースト 24.9倍、単独の初回チャンク0.14秒。

| 同時数・本文 | 成功 | 初回PCM p50 | 初回PCM p95 | 完了 p95 | 総音声生成倍率 | 枯渇 |
|---|---:|---:|---:|---:|---:|---:|
| 1・short | 5/5 | 0.236秒 | 0.273秒 | 2.11秒 | 3.83倍 | 0 |
| 8・short | 24/24 | 0.468秒 | 0.506秒 | 3.32秒 | 18.06倍 | 0 |
| 16・short | 32/32 | 0.743秒 | 0.767秒 | 4.68秒 | 24.62倍 | 0 |
| 32・short | 64/64 | 1.272秒 | 1.300秒 | 6.97秒 | 33.02倍 | 0 |
| 1・long（423文字、5分割） | 2/2 | 0.355秒 | 0.367秒 | 6.98秒 | 10.69倍 | 0 |
| 4・long | 4/4 | 0.874秒 | 0.874秒 | 12.42秒 | 23.88倍 | 0 |
| 2・medium（113文字） | 4/4 | 0.296秒 | 0.354秒 | 6.53秒 | 6.36倍 | 0 |

第1版（8001番）は1件3.28倍・8件15.45倍・16件20.95倍だった。long 1件は約70秒分の音声を7秒で受信（分割が並列に走るため）。

注意: 本プロセスのVRAMは最大同時32・codec graph 6クラスで約20GiB（第1版約12GiB）。本番単独では収まるが、同じGPUで実験を並走させる余地は減った。

### 本番反映後の確認（12:06反映、ngrok公開URL経由）

起動ログ: `codec graphs captured for classes [1, 2, 4, 8, 16, 32] ... max|graph-eager| = 0`、`engine ready: ... max_seq_len=1024 rows=32 max_new_tokens<=446`。エラー0、GPU使用量21.6GiB（本番のみ）。

| 同時数・本文 | 成功 | 初回PCM p95 | 完了 p95 | 総音声生成倍率 | 枯渇 |
|---|---:|---:|---:|---:|---:|
| 1・short | 5/5 | 0.340秒 | 2.02秒 | 3.66倍 | 0 |
| 8・short | 16/16 | 0.632秒 | 3.47秒 | 17.27倍 | 0 |
| 16・short | 32/32 | 0.970秒 | 5.87秒 | 17.75倍 | 0 |
| 1・long（423文字） | 1/1 | 0.476秒 | 6.58秒 | 10.66倍 | 0 |

同時16件はlocalhostの24.6倍に対して17.8倍だったが、続けて測った同時24件は48/48成功・初回p95 1.25秒・18.2倍・枯渇0、同時32件は64/64成功・初回p95 1.57秒・32.5倍・枯渇0。32件で32.5倍が通っているので、ngrok経由が16件で頭打ちという見方は撤回する（16〜24件の倍率の低さはバースト構造による計測の揺れ）。ngrokエージェントは東京拠点（jp、往復10ms）に自動接続済み。長文の保存音声: `benchmarks/concurrency/results/prod-v2-long-20260913.wav`（分割境界の聴取用）。

### 未確認

- 分割境界の聞こえ方（30msフェード＋120ms無音）。読み上げの長文をユーザーが聴取して確認する。
- 同時32件時の各要求は実時間の約1.15倍（完了p95 6.97秒に対し音声約8秒）で、余裕は小さい。実運用の上限は24件程度と見る。

## 第3版（2026-09-13 夜）：波形復号の左文脈を25→12フレームに短縮

同時数の上限を決めているのは波形復号の時間（同時32件で1チャンクの4割）だったので、復号窓の左文脈（元実装の25フレーム）をどこまで縮められるかを測った。資材は `benchmarks/concurrency/codec_context_bench.py`（復号時間と波形誤差）、`codec_context_relative.py`（文脈25基準）、`codec_context_perceptual.py`（log-mel距離・境目クリック指標・聴取用WAV）。実音声4本（vivian/seiko、短文〜長文）。

| 左文脈 | log-mel距離（一括復号との差） | 現行25からの増分 | 境目クリック指標（>2で疑い） | 復号時間 同時32件（graph） |
|---:|---:|---:|---:|---:|
| 25（旧） | 0.72dB | — | 1.22 | 91ms |
| 16 | 0.93dB | +0.21dB | 1.08 | 62ms |
| 12（採用） | 1.12dB | +0.40dB | 1.03 | 49ms |
| 8 | 1.33dB | +0.61dB | 1.02 | 37ms |
| 4 | 1.63dB | +0.91dB | 1.02 | 24ms |

波形SNRでは文脈による差が大きく見える（25対16で15dB）が、これは位相のずれで、位相に依らないlog-mel距離では0.2〜0.4dBの差に留まる。一括復号自身のクリック指標は1.14で、どの文脈でも境目の段差は出ていない。ユーザーが `vivian-short` の文脈4〜25の音声を聴き比べ、区別がつかないと確認した。安全側に12を採用。

| 構成 | 文脈25 | 文脈12 |
|---|---|---|
| 同時16件 | 各要求1.9倍、合計30倍 | 各要求2.4倍、合計38倍 |
| 同時32件 | 各要求1.4倍、合計45倍 | 各要求1.7倍、合計55倍 |
| 同時48件 | 0.8倍（不可） | 約1.3倍、合計約62倍（見込み、未計測） |

設定は `scripts/.env` の `TTS_CONTEXT_FRAMES=12`（`api_server_batch.py` の既定値は25）。19:02に本番へ反映し、起動ログに `context_frames=12` を確認。聴取用WAVは `benchmarks/concurrency/results/codec-context-perceptual-20260913/`（話者・文ごとに full / ctx25 / ctx16 / ctx12 / ctx8 / ctx4）。48件構成は未実装・未計測。

### 見込みと次の一手（2026-09-13 夜、未計測の判断）

- **48件構成は「ぎりぎり捌ける」見込み止まり。** 上表の1.3倍は32件までのステップ時間の外挿で、48クラスのグラフは未実装・未計測。1.3倍は再生に対する余裕が3割しかなく、長文やサンプリングのばらつきで一部の要求が再生に追いつかない可能性がある。VRAMは約25GBになるので画像生成などとの同居は難しい。安心して言えるのは実測済みの32件（各1.7倍）まで。混んできたら `.env` の `TTS_BATCH_CLASSES` を `1,2,4,8,16,32` に戻すのが現実的な次の一手。
- **枠（同時生成数）と利用者数は別。** 枠を占有するのは音声を生成している間だけで、5秒の返答なら16件構成（2.4倍速）では約2秒で空く。会話は聞く・考える時間が長いので、1人が枠を使う割合は1〜2割。1ターン5秒の返答を20秒に1回話す想定で1枠あたり約10人、16件構成で100人規模、32件構成で200人規模の同時会話まで待ち行列がほぼ出ない目安。全員が同時に話すピークでは待ちが出るが、待ち行列に入るだけで音声は壊れない。相槌・読み上げも同じ枠を使うので実際はこれより少し減る。Cartesia Pro（同時5）で32台の運用が回った経験とも整合する。
- **混雑を知る手段が無い。** 待ち行列の長さと最大待ち時間はログにも `/health` にも出ていない。`/health` に `queue_length` と `max_wait_ms` を出す小さな変更で気づけるようにする（[先送り項目](deferred-items.md)）。

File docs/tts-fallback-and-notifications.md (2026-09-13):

# TTSフォールバックとプッシュ通知の仕様（2026-09-13 合意、未実装）

Cartesiaの同時接続上限（Pro 3 / Startup 5 / Scale 15、超えると即429、キュー無し）に当たっても会話を止めないための仕様と、それに付随する通知の考え方。ユーザーと合意済み。実装はまだ。

## 1. 背景

- Cartesiaは声の品質と速度で本命だが、同時接続数がプランで固定されている。1人の会話が消費する同時接続は平均0.3本程度（1文0.5〜1秒の要求）で、Scaleなら40〜50人が同時に会話できる見込み。ただし瞬間的な重なりで16本目が来れば429になる。
- 複数アカウントで上限を回避する案は却下。規約がグレーなことに加え、クローンボイスがアカウント単位なので利用者を分けると声の資産が分断される。上限の追加購入・Enterpriseの条件はCartesiaに問い合わせ中（2026-09-13送信、返答待ち）。
- **Cartesiaの回答（2026-09-13、営業担当）**: (1) Scaleの15を超える同時接続はEnterpriseのみで、追加購入は無い。Enterpriseは月$1,750から、月67,000分（約5,000万字）込み、同時接続と単価はコミット量で改善。(2) サーバー側の順番待ちは無く、クライアント側の再試行が想定どおりの使い方。エラーはクレジットを消費しない。(3) 同一組織の複数APIキーは同時接続の枠を共有（上限は組織単位）。本番と検証を分けるなら別組織。(4) クローンボイスは組織単位なので、バックエンドが1組織の認証情報で作れば全部同じ組織に集まる。
- 線引き: Enterpriseの入口（月$1,750、5,000万字≒AI発話2,400時間）は1人月10時間で約240人分。そこまではScale（15）で運用し、検証用はFreeの別アカウントを作る。
- 実測（2026-09-13、Pro、読み上げLambda経由で1文ずつ同時に投げた）:

| 同時件数 | 中央値 | 90%点 | 最大 | 429で切り替わった数 |
|---|---|---|---|---|
| 16 | 1.3秒 | 2.2秒 | 2.4秒 | 0 |
| 32 | 2.6秒 | 4.0秒 | 4.4秒 | 0 |
| 48 | 4.2秒 | 6.5秒 | 6.9秒 | 0 |
| 64 | 4.5秒 | 7.6秒 | 8.5秒 | 0 |
| 96 | 3.1秒 | 7.8秒 | 9.1秒 | 27（全部429、フォールバックで利用者にはエラーなし） |

  Proの「同時3」は短い要求には実質64件程度まで拒否されず、代わりに待たされる。「順番待ちは無い」という回答とは食い違うが、短い要求は瞬間的に枠が空くためと見ている。実用上の上限は429の手前ではなく「遅くなり始める16〜32件」で、同時に話す10人程度ならPro、それ以上はScale。
- 次の候補（未実装）: 失敗だけでなく「主プロバイダーの応答が3秒を超えたら、その返答の残りはずんだもん」に切り替える遅延条件。待たされる状態でも会話のテンポを守れる。月次レポートに「ピーク同時本数」「切り替え回数」を足し、Scaleへ上げる時期をデータで判断する。
- フォールバック先はSakura Internet（ずんだもん）。原価が1文字0.0003円と最安で、円建て・国内・同時接続の制約が緩い。

## 2. フォールバックの動き（本文Lambda: App / ESP32 共通）

```
文ごとのTTS呼び出し
  → 主プロバイダー（キャラクターの声）で生成
  → 429 または 5xx なら 0.3秒待って再試行、だめなら 0.6秒待ってもう1回
  → それでもだめなら、その文からずんだもん（Sakura）で生成
```

- 追加の遅延は最大1秒程度。それ以上待つより声を変えたほうが体感は良い。
- 主プロバイダーもフォールバック先もPCM 24kHz（Appは同じWAV化経路）なので、再生側の変更は不要。
- **返答単位で固定する。** 一度切り替えたら、その返答の残りの文はずんだもんのまま。文ごとに声が行き来しないようにする。次の返答からは再び主プロバイダーを試す。
- **切り替わった最初の返答の頭に一言足す**（例:「いまは混んでるから別の声で話すね」）。ESP32は画面が無いので、子供にはこれで伝える。
- Cartesia専用にせず「主プロバイダーが失敗したらSakuraへ」の共通の仕組みにする。ElevenLabsやOpenAIの障害・上限にも同じコードが効く。
- 判定は例外のHTTPステータスで行う。各プロバイダーの関数は `status` を持つエラーを投げるように揃える（現在はメッセージ文字列に埋め込んでいるだけ）。

## 3. コスト記録

- 実際に使った声で記録する。返答内の文字数を主プロバイダー分とSakura分に分け、`toytalker-usage` に2行（例: `cartesia#tts` と `sakura#tts`）として加算する。現在は返答全体を1プロバイダーで記録しているため、集計側の変更が要る。
- 会話ログにも `tts_fallback: { from, to, chars }` を残す。
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

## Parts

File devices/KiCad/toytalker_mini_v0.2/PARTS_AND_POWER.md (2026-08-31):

# ToyTalker Mini 部品の役割と電源の流れ

> **このファイルの役割: 「なぜそうしたか」。** 設計判断の経緯・実測・データシート裏取りのアーカイブ。**現在の値・ネットの正は PARTS_LIST.md**(このファイル内の値は当時の記録で、更新保証なし)。

v0.1実基板のネットリストから検証済み(2026-08-12)。v0.2の変更計画も末尾に記載。

## 電源の流れ(v0.1 現状)

```
USB-C(J1)                     バッテリー(J2)
   │VBUS                          │VBAT
   │ C1 10uF                      │ C2 10uF
   └────→ U1 BQ25185 ←───────────┘
           │  充電IC+パワーパス:
           │  ・USBがあればUSBからV_SYSへ給電しつつVBATを充電
           │  ・USBがなければVBAT→V_SYSへ放電
           │V_SYS (C3 22uF)
           ▼
        S1 スライドスイッチ ← ★全システム電流が接点を通過(定格10mAに対し実力500mA級=50倍オーバー)
           │V_SYS_SW (C4 22uF)
           ▼
        U2 AP2112K (3.3V LDO, 定格600mA)
           │+3V3 (C5 22uF)
           ├──→ U3 ESP32-S3-MINI (C6 0.1uF直近)
           ├──→ MK1 マイク SPH0645 (C8 0.1uF直近)
           └──→ U4 アンプ MAX98357 (C9 10uF直近) → SP1 スピーカー
```

### 電流の制限ポイント早見表

| 場所 | 上限 | 意味 |
|---|---|---|
| 入口: BQ25185 ILIM (R3=13kΩ) | 約1.1A | USBから引き込める上限。バッテリー接続時はピーク不足分をバッテリーが補う |
| 充電: BQ25185 ISET (R4=620Ω) | 500mA | バッテリーへの充電電流 |
| 出口: AP2112K | 600mA | 3.3Vを作れる上限。ESP32(WiFiピーク~500mA)+アンプが同居=窮屈 ★v0.2検討事項 |
| S1接点 | **10mA** | ★大幅超過中 → v0.2でEN方式化 |

## パーツ一覧

→ **PARTS_LIST.md に移管**(2026-08-29。値の二重管理による更新漏れ防止)。各部品を「なぜそうしたか」はこのファイルの変更一覧と各節を参照。

## ⚠️ 名前の衝突に注意: 「EN」が2つある

| | どこのEN | 役割 | v0.2での扱い |
|---|---|---|---|
| ESP_EN | **ESP32の**ENピン(R6/C7) | チップのリセット(LOWでリセット) | 現状維持。ネット名を`ESP_EN`に |
| PWR_EN | **AP2112Kの**ENピン | 3.3V電源のON/OFF指示 | ★v0.2でS1がここを制御(EN方式) |

## v0.2 電源の流れ(計画)

```
USB-C / バッテリー → U1 BQ25185 → V_SYS ──直結──→ U2 AP2112K → +3V3 → ESP32/マイク
                                    │                ↑PWR_EN
                                    │            S1(common→PWR_EN, 片側→V_SYS, 片側→GND)
                                    │            +100kΩプルダウン(保険)
                                    └──→ U4 アンプ VDD(V_SYS直結に確定 2026-08-15。LDO負荷半減)
                                          ※C9(10uF)もV_SYS側アンプ直近へ移動
                                          ※外付けプルダウン不要(SD_MODEに内部100kΩプルダウン内蔵。
                                            ESP32死亡時は自動でシャットダウン0.6µAに落ちる)
```

**アンプV_SYS直結のデータシート裏取り(2026-08-15完了、MAX98357A/B datasheet)**:
- ✅ VIH=1.3V固定(VDD非依存)→ VDD=4.2VでもESP32の3.3V信号(BCLK/LRC/DIN/SD)は正常認識
- ✅ SD_MODEは**内部100kΩプルダウン内蔵**(92〜108k保証)→ 外付けR14不要。電源OFF時(SD浮き)は自動シャットダウン
- ✅ シャットダウン電流 0.6µA typ / 2µA max → 常時通電でも発熱・電池消耗は無視できる
- ✅ 電源範囲 2.5〜5.5V(V_SYS 3.0〜4.2Vは余裕で範囲内)
- ⚠️ 最大出力(8Ω, THD10%, gain12dB): 3.7Vで0.93W → 4.2Vで約1.2W(現3.3Vは約0.75W)。**スピーカー耐入力の確認をPhase 3までに**。超える場合はソフト音量上限 or GAINピン設定で対処

v0.2追加部品: 470kΩ×2+0.1uF(電池残量分圧→GPIO1)、100kΩ×2(STAT1/2プルアップ→GPIO13/14)、100kΩ(PWR_ENプルダウン)、NTCサーミスタ×2+10kΩ+0.1uF(TH1充電保護/TH2温度可視化, C77131)、MX1.25ヘッダ(スピーカー用, HC-1.25-2PWT / C2845379)、ZHヘッダ(電池用, S2B-ZR-SM4A-TF / C265329)、サイド型スライドスイッチ(MSK12C02G15-B / C22435661)

## 部品単位の変更一覧(v0.1→v0.2)

### 変更なし(そのまま)
J1(USB-C), R1/R2(CC), C1, C2, R3(ILIM), R4(ISET), R5(TS), C3, C5, C6, R6+C7(ESP_EN ※ネット名改名のみ), D1, R7, S2, C8
※C9(アンプ用10uF)は部品同じだがネットが+3V3→V_SYSに変わるため「配線が変わる」へ移動

### 配線が変わる(部品は同じ)
| Ref | v0.1 | v0.2 |
|---|---|---|
| U1 BQ25185 | STAT1/2未接続 | STAT1→GPIO13, STAT2→GPIO14(+プルアップ) |
| U2 AP2112K | EN=VINに縛り常時ON、VIN=V_SYS_SW | **VIN=V_SYS直結、EN=S1で制御(PWR_EN)** |
| U3 ESP32 | I2S共有(3,4,5,9) | **I2S分離**: MIC=4/5/9, AMP=10/11/12。GPIO1=電池ADC, 13/14=STAT。GPIO3解放 |
| MK1 マイク | WS→GPIO3 | WS→**GPIO5** |
| U4 アンプ | BCLK=4, LRC=3, DIN=5、VDD=+3V3 | BCLK=**10**, LRC=**11**, DIN=**12**。**VDD=V_SYS直結に確定**(C9も移動。SD内部プルダウン内蔵のため外付け不要) |
| S1 スイッチ | V_SYS→V_SYS_SWの経路上 | **PWR_ENの切替**(common→PWR_EN, 両端→V_SYS/GND) |
| C4 22uF | V_SYS_SWのデカップリング | そのまま残すがネットはV_SYS(LDO入力直近)に |

### 部品自体が変わる
| Ref | v0.1 | v0.2 |
|---|---|---|
| **J2 バッテリー** | JST SH (SM02B-SRSS) | **JST ZH** S2B-ZR-SM4A-TF (C265329, 横型SMD, **高3.7mm≦4mm制限OK**, 1A)。ケーブル側: ハウジング**ZHR-2**+太線用コンタクト**SZH-002T-P0.5**(AWG26〜28・被覆φ1.1mmまで→電池リードφ0.93〜1.0が**スペック内**、SN-03BMで直接カシメ可)。SH案は電池リード被覆がSH上限0.8mm超過のため撤回(2026-08-16実測)。手持ちSHピグテール(オーディオファン10本)はv0.1機の保守用に温存 |
| SP1 スピーカー | JST SH | **MX1.25(PicoBlade互換)** HCTL **HC-1.25-2PWT (C2845379**, 横型SMD, **高3.57mm≦4mm制限OK**, 1A, **在庫309,946・$0.05**)。購入スピーカー付属のMX1.25プラグ(ハウジング幅4.3mm実測で確定)が無加工で挿さる=v0.1でやっていた「付属プラグ切断→SH付け直し」が不要に。電池(ZH)と別規格=挿し間違い防止。フットプリントはHCTL自身のEasyEDAデータを使用(互換品は本家と半田タブ位置が違う場合あり)、Phase 3で実物嵌合確認。代替=Molex純正53261-0271(C177225, $0.16)。※当初のZH案(C265329)は破棄(2026-08-15) |
| S1 | ALPS SSAJ110100(サイド操作、ノブ極小) | **MSK12C02G15-B (C22435661、ノブ1.5mm) に確定**(2026-08-15)。筐体側面(スマホ式)で操作、蓋側からの操作にも対応可。掛かり代1.5mmはケース側の設計で吸収する方針(ユーザー決定)。本体6.7×2.8×1.45mm、SPDT、0.1A/12VDC、操作力160gf、在庫34,904・$0.027。基板の縁に配置(ノブが縁からはみ出す向き)+位置決めペグ用Φ0.8穴×2。**掛かり代が足りない場合はG20-B(ノブ2.0mm、在庫3,000)へ — 同一フットプリントなのでBOM差し替えのみ**。※上面操作型ALPS SSSS820101/820201は側面操作方針のため見送り(ケース方針が変われば復活可) |
| R8 LED抵抗 | 47Ω(≈27mA、眩しすぎ) | **470Ω**(≈2.8mA=1/10)。暗すぎたら手交換 or PWM調整 |

### 新規追加

→ 一覧は **PARTS_LIST.md**「監視・計測」ほか参照。

※旧R14(AMP_SDプルダウン)は一旦計画したが、MAX98357のSD_MODEに内部100kΩプルダウンが内蔵と判明し**不要**(2026-08-15)。R14の欄番は温度分圧用に再利用

## v0.3 マイク代替検討（2026-08-31、データシート裏取り済み）

背景: SPH0645LM4H-1-8のJLC在庫が残4、姉妹品-B-8は在庫0（プリオーダー$9.65〜）。KnowlesのI2S世代は事実上入手難。

| 候補 | JLC# | 価格/在庫 | 出力 | 判定 |
|---|---|---|---|---|
| SPH0655LM4H-1-8 (Knowles Cornell II) | C22376158 | $0.75 / 2,679 | **PDM**（I2Sではない） | v0.3候補①。フットプリント・ファーム両方の変更が必要 |
| ICS-43434 (TDK InvenSense) | C5656610 | $4.08 / 4,916 | I2S | v0.3候補②。ファームほぼ無変更。ピン配置互換性は未照合 |

**SPH0655の裏取り結果**（Knowles datasheet Rev C）:
- 出力は「single bit PDM output」= クロックとデータの2線式。I2SのWS（左右の合図線）が存在しない
- ピン配置: 1=DATA / 2=SELECT / 3=GND / 4=CLOCK / 5=Vdd の**5パッド**。SPH0645は6パッド（1=WS/2=SELECT/3=GND/4=BCLK/5=VDD/6=DATA）で、パッド列間隔も1.675mm vs 1.80mmと異なる → **載せ替え不可、v0.3でフットプリント変更必須**
- 外形は同一 3.5×2.65×0.98mm、底面ポート。電源1.65〜3.6V（3.3V駆動OK）
- クロック1.2〜4.8MHz（Normal）。ESP32-S3はPDMマイク受信に対応しており、既存のMIC_BCLK線→CLOCK、MIC_DATA線→DATAの2本で足り、WS線(GPIO33)が空く
- 音質はむしろ向上: SNR 66dB(A)（現行65）、AOP 132.5dB SPL（現行120）= 大音量で歪みにくい
- X-ray検査対象なのは現行と同じ（実装費条件は変わらず）

**未決定**: 安さ・在庫のSPH0655（PDM化）か、変更最小のICS-43434か。ICS-43434のピン配置がSPH0645と互換かの照合が次のタスク。

**生産状況の裏取り（2026-08-31追記）**: SPH0645系（-1/-B共）はDigiKeyで**Obsolete（生産終了・流通在庫限り）**。SPH0655LM4H-1は**Active**（DigiKey在庫1万個超）。なおKnowlesのコンシューマ向けマイク部門は2024年にSyntiant社へ売却され、現在の流通ブランド表記はSyntiant。I2S出力のMEMSマイク自体が市場でニッチ化しており（現行品はTDK ICS-434xxの$4〜5帯くらい）、安価な主流はPDM。

**PDMの対抗馬（JLCカテゴリ568件から、SNR64dB以上・在庫あり）**:
| 部品 | JLC# | 価格/在庫 | SNR | 感度 | 備考 |
|---|---|---|---|---|---|
| SPH0655LM4H-1-8 | C22376158 | $0.75 / 2,679 | 66dB | -37dBFS | 本命。ゲイン+11dB要 |
| Goertek SD18OB261-060 | C2895290 | $0.93 / 6,525 | 65dB | **-26dBFS** | 対抗。感度がSPH0645と同じでゲイン調整不要。同3.5×2.65mm 5P。Goertekはスマホマイク大手 |
| ST MP34DT06J | C503097 | $2.14 / 3,733 | 64dB | -26dBFS | 4×3mmで一回り大きい |
| Infineon IM69D130 | C536262 | $4.12 / 441 | **69dB** | -36dBFS | 高音質枠。将来の上位モデル用 |

v0.3設計時はSPH0655とSD18OB261の2枚看板でデータシート照合（フットプリントが同一なら基板1版で両対応も狙える）。

**SD18OB261-060の裏取り結果（2026-08-31、Goertek SPEC V1.0 2018.10.05、LCSC掲載PDF）**:
- 電源: **VDD 1.60〜3.6V → 3.3V駆動OK**（JLC一覧の「1.8V」はテスト条件の代表値だった）
- 出力: PDM。クロック Standard Mode **1.2〜3.5MHz** / Sleep 0〜150kHz。SPH0655(1.2〜4.8MHz)と重なる帯域→**ファーム設定は16kHz×128=2.048MHzで両者共通にできる**（×64=1.024MHzは両者とも下限1.2MHz未満で不可）
- ピン配置: **1=DATA / 2=L/R(SELECT) / 3=GND / 4=CLK / 5=VDD → SPH0655と番号・機能とも完全一致**
- パッケージ/ランドパターン: 3.50×2.65×0.98mm、AP Ø0.325、パッド0.725×0.522、列間1.675mm・行間0.822mm、リングパッドØ1.025/1.625・中心から1.513mm → **SPH0655のランドパターンと寸法一致 = フットプリント共通化可能**（ピン1の向きだけv0.3設計時に両図面の表裏基準を突き合わせて最終確認）
- 感度-26dBFS（ゲイン調整不要）、SNR 65dB、AOP 120dB SPL、周波数特性100Hz〜8kHz（16kHz STT用途では十分。SPH0655は〜10kHz超で広め）
- **結論: v0.3は共通フットプリント1個で、1軍=SPH0655($0.75/SNR66)、2軍=SD18OB261-060($0.93/ゲイン不要)のデュアルソース体制が可能**

### ネット名の整理(誤記・紛らわしさ解消)
- `GPIO27` → `GPIO0_BOOT`(実体はGPIO0だった)
- `Net-(U3-EN)` → `ESP_EN`(ESP32のリセット)
- 新設 `PWR_EN`(AP2112KのEN)
- `V_SYS_SW` → 廃止(V_SYSに統合)

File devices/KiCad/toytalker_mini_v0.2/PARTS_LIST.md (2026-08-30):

# v0.2 パーツ一覧（回路図から機械抽出した実値・2026-08-29検証）

> **このファイルの役割: 「今の正」。** 部品の値・ネット・役割の唯一の基準。BOM作成・発注チェック・値の確認はこのファイルだけを見る。変更したら必ずここを更新する。
> 経緯・理由 → PARTS_AND_POWER.md / 作業ログ → SCHEMATIC_CHECKLIST.md / GPIO → PINMAP.md

検証方法: `toytalker_mini_v0.2.kicad_sch` から全Reference/Valueを抽出し、ネットリストで接続先を照合。

## パーツ一覧 ※電気の流れ順

### USB受電 → 充電IC
| Ref | 値 | ネット | 役割 |
|---|---|---|---|
| J1 | TYPE-C-31-M-12 | VBUS | USB-C電源入力 |
| R1 | 5.1kΩ | CC1 | USB-C「5V/3Aください」の名札(必須) |
| R2 | 5.1kΩ | CC2 | 同上(ケーブル裏表対応) |
| C1 | 10uF | VBUS | BQ25185のIN入力デカップリング |
| U1 | BQ25185 | - | 電源制御。充電しながら電力供給(パワーパス) |
| R3 | 13kΩ | ILIM/VSET | USBから最大1.1A受電の設定 |
| R4 | **620Ω** | ISET | バッテリーへ500mA充電の設定 |
| TH1 | NCP15XH103F03RC | TS/MR | 🆕 充電温度保護サーミスタ。高温/低温でBQが充電を自動停止(旧R5の置き換え) |

### バッテリー
| Ref | 値 | ネット | 役割 |
|---|---|---|---|
| J2 | S2B-ZR-SM4A-TF | VBAT | 🆕 バッテリーコネクタ(JST ZH。旧SHから変更、φ1.0被覆線対応) |
| C2 | 10uF | VBAT | BQ25185のBAT側デカップリング |

### システム電源 V_SYS（常時通電）
| Ref | 値 | ネット | 役割 |
|---|---|---|---|
| C3 | 22uF | V_SYS | BQ25185のSYS出力デカップリング |
| C4 | 22uF | V_SYS | 同上追加分 ※旧V_SYS_SW用→v0.2でV_SYS_SW系統は廃止 |

### 電源スイッチ（EN方式 = 信号だけを切り替える）
| Ref | 値 | ネット | 役割 |
|---|---|---|---|
| S1 | MSK12C02G15-B | PWR_EN | 🆕 スライドスイッチ。V_SYS/GNDを選んでPWR_ENへ(大電流は流れない) |
| R9 | 100kΩ | PWR_EN | プルダウン。スイッチ切替中にENが宙ぶらりんになるのを防ぐ「重り」 |

### LDO → +3V3
| Ref | 値 | ネット | 役割 |
|---|---|---|---|
| U2 | AP2112K-3.3 | - | LDO。V_SYS→3.3Vに降圧。ENピンがPWR_ENで電源ON/OFF |
| C5 | 22uF | +3V3 | LDO出力デカップリング |
| C6 | 0.1uF | +3V3 | ESP32直近の高周波デカップリング |
| C8 | 0.1uF | +3V3 | マイク直近デカップリング |

### ESP32まわり
| Ref | 値 | ネット | 役割 |
|---|---|---|---|
| U3 | ESP32-S3-MINI-1-N4R2 | - | 本体（実寸15.4×20.5mm、アンテナ部5.05mm含む） |
| R6 | 10kΩ | ESP_EN | ENプルアップ |
| C7 | 0.1uF | ESP_EN | ENの立ち上がり遅延+ノイズフィルタ |
| S3 | B3U-1000P | GPIO0_BOOT | Bootボタン |
| S2 | SKRPABE010 | (GPIO7) | 機能ボタン(押すとGND) |
| R7 | 10kΩ | GPIO7 | ボタンとGPIOの間の直列抵抗(ピン保護) ※プルダウンではない |
| D1 | KT-0805W | (GPIO8) | 単色LED |
| R8 | **470Ω** | GPIO8 | LED電流制限。v0.2で47Ω→470Ωに変更(減光、約2.8mA) |

### 監視・計測（v0.2新設）
| Ref | 値 | ネット | 役割 |
|---|---|---|---|
| R10 | 470kΩ | VBAT→GPIO1 | 🆕 電池残量分圧の上側 |
| R11 | 470kΩ | GPIO1→GND | 🆕 電池残量分圧の下側 |
| C10 | **0.1uF** | GPIO1 | 🆕 ADC安定化(WiFiノイズ平滑) |
| R12 | 100kΩ | GPIO13 | 🆕 充電状態STAT1プルアップ(STATはオープンドレインのため必須) |
| R13 | 100kΩ | GPIO14 | 🆕 充電状態STAT2プルアップ |
| R14 | 10kΩ | +3V3→GPIO2 | 🆕 基板温度分圧の上側 |
| TH2 | NCP15XH103F03RC | GPIO2→GND | 🆕 基板温度サーミスタ(分圧の下側) |
| C11 | 0.1uF | GPIO2 | 🆕 ADC安定化 |

### 音声
| Ref | 値 | ネット | 役割 |
|---|---|---|---|
| MK1 | SPH0645LM4H | GPIO4/5/9 | I2Sマイク |
| U4 | MAX98357A | - | I2Sアンプ。VDDは**V_SYS直結**(v0.2変更。3.3Vでは音量パワー不足のため) |
| C9 | 10uF | **V_SYS** | アンプVDDデカップリング ※+3V3ではない |
| SP1 | HC-1.25-2PWT | OUTP/OUTN | 🆕 スピーカーコネクタ(MX1.25互換。旧SHから変更) |

## v0.1からの削除
- R5 (10kΩ TS/MR固定抵抗) → TH1に置き換え
- 旧J2/旧SP1 (JST SH) → ZH / MX1.25に変更
- 旧S1 (SSAJ110100) → MSK12C02G15-Bに変更
- V_SYS_SWネット → EN方式化により廃止

## プレフィックス順サマリ
- **J**: J1 USB-C / J2 バッテリー(ZH)
- **U**: U1 BQ25185 / U2 AP2112K / U3 ESP32-S3-MINI-1 / U4 MAX98357A
- **S**: S1 電源スライド / S2 機能 / S3 Boot
- **R**: R1,R2=5.1k(CC) R3=13k(ILIM) R4=620(ISET) R6=10k(EN) R7=10k(ボタン直列) R8=470(LED) R9=100k(PWR_ENプルダウン) R10,R11=470k(残量分圧) R12,R13=100k(STATプルアップ) R14=10k(温度分圧)
- **C**: C1,C2=10u(VBUS/VBAT) C3,C4=22u(V_SYS) C5=22u,C6=0.1u,C8=0.1u(+3V3) C7=0.1u(EN) C9=10u(V_SYS アンプ) C10,C11=0.1u(ADC)
- **TH**: TH1 充電保護 / TH2 基板温度 (同一品NCP15XH103F03RC)
- **他**: D1 LED / MK1 マイク / SP1 スピーカー

## パッケージサイズの使い分け（2026-08-30追記）

サイズ表記: **0402** = 1.0×0.5mm / **0603** = 1.6×0.8mm（インチ由来の呼び名。メートル表記だと1005/1608でKiCadのフットプリント名はこちら）

| 種類 | サイズ | 理由 |
|---|---|---|
| 抵抗 全部(R1〜R14, TH1/TH2) | **0402** | 抵抗のサイズは**発熱**で決まり、値は無関係。本基板の最大はR8の34mW(旧47Ω時)で0402定格62.5mWに収まる。470Ω化後は3.7mWでさらに余裕 |
| コンデンサ 0.1µF (C6/C7/C8) | **0402** | 小容量は小さい体積で作れる |
| コンデンサ 10〜22µF (C1〜C5, C9) | **0603** | 容量は物理体積が必要。0402の10µFは高価な上、電圧がかかると実効容量が大きく落ちる(DCバイアス特性)ため0603が定石 |

※C10/C11(0.1µF)がv0.2追加時の初期値で0603になっている → **0402へ統一予定**(BOMがC6/C7/C8と同一品目にまとまり実装費・面積とも有利)

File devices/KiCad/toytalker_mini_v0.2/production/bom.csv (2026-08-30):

Designator | Footprint | Quantity | Value | LCSC Part #
C1, C2, C9 | 0603 | 3 | 10uF
C10, C11, C6, C7, C8 | 0402 | 5 | 0.1uF
C3, C4, C5 | 0603 | 3 | 22uF
D1 | LED_KT-0805W | 1 | KT-0805W
J1 | HRO_TYPE-C-31-M-12 | 1 | TYPE-C-31-M-12
J2 | CONN-SMD_S2B-ZR-SM4A | 1 | S2B-ZR-SM4A-TF(LF)(SN) | C265329
MK1 | MIC_SPH0645LM4H-B | 1 | SPH0645LM4H-1-8
R1, R2 | 0402 | 2 | 5.1k
R10, R11 | 0402 | 2 | 470k
R12, R13, R9 | 0402 | 3 | 100k
R14, R6, R7 | 0402 | 3 | 10k
R3 | 0402 | 1 | 13k
R4 | 0402 | 1 | 620
R8 | 0402 | 1 | 470
S1 | SW-SMD_MSK12C02G15-B | 1 | MSK12C02G15-B | C22435661
S2 | SW_SKRPABE010 | 1 | SKRPABE010
S3 | SW_B3U-1000P | 1 | B3U-1000P
SP1 | CONN-SMD_2P-P1.25-HC-1.25-2PWT | 1 | HC-1.25-2PWT | C2845379
TH1, TH2 | R0402 | 2 | NCP15XH103F03RC | C77131
U1 | IC_BQ25185DLHR | 1 | BQ25185DLHR
U2 | SOT95P285X140-5N | 1 | AP2112K-3.3TRG1
U3 | XCVR_ESP32-S3-MINI-1-N4R2 | 1 | ESP32-S3-MINI-1-N4R2
U4 | BGA9N40P3X3_134X143X69N | 1 | MAX98357AEWL_T

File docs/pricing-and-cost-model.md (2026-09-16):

# 原価と課金の考え方（2026-09-13 時点の方針）

従量課金で「使った分だけ、安く、気軽に」を実現するための、原価の見方と料金の組み立て。月次運用レポートLambda（第10節）の前提になる。2026-09-10の市場調査（旧 cost-estimate.md）と2026-09-12のツールコスト記録（旧 search-cost-tracking.md）は末尾に統合した。

## 1. 原価の記録と請求額の関係

```
請求額（円） = API単価（USD） × 使用量 × その月の為替 × マージン
```

- **API単価**: `toytalker-api-unit-prices` にドル建てで保存（Sakuraのみ円建て）。プロバイダー×種別ごと（`google#llm` など）。自動更新はしない。
- **為替**: `toytalker-exchange-rates` に月ごとの行。毎月1日に運用Lambdaが ECB（欧州中央銀行）の公表レートを保存し、その月は固定。行が無い月は150円で計算される。
- **マージン**: `service#margin` の1行。現在 **2.0**。これが従量課金の「売価」そのもの。
- 記録される種別は `stt / llm / tts / tool` の4つ。相槌のLLM・TTSと、AWS・為替・カード手数料は記録しない（マージンで吸収）。

## 2. 1時間の会話の原価（マージン前）

前提: 40ターン、AI発話30分、子供の発話15分、LLMはGemini 2.5 Flash（1ターン入力2,500トークン・出力80トークン）、為替152円。

| 項目 | Sakura（ずんだもん） | Cartesia（リアル系） |
|---|---|---|
| TTS | 3.6円（12,000モーラ） | 約160円（1万字超、$0.00005/字） |
| LLM | 5.8円 | 5.8円 |
| STT（Soniox） | 3.3円 | 3.3円 |
| ツール（検索2回） | 0.3円 | 0.3円 |
| **記録される原価** | **約13円** | **約170〜180円** |
| 相槌（Gemini Flash 40回＋TTS） | 1.6円 | 約2円 |
| AWS（Lambda実行が中心、転送・ログ・DynamoDB） | 3.3円 | 約4円 |
| カード海外手数料（約2%） | 0.3円 | 約4円 |
| **本当の原価** | **約18円** | **約190〜200円** |

- DynamoDBは1時間で0.1円未満。ログを何年ためても問題にならない。
- 記録外の原価は「ターン数に比例」なので、TTSが安いSakuraでは記録原価の約40%、Cartesiaでは約3%にあたる。

## 3. マージン2.0での収支

| ボイス | 請求（1時間） | 本当の原価 | 決済手数料（Stripe 3.6%） | 手元に残る割合 |
|---|---|---|---|---|
| Sakura | 約26円 | 約18円 | 約1円 | 約27% |
| Cartesia | 約350〜400円 | 約200円 | 約13円 | 約45% |

どちらも赤字にならない。**マージン2.0で進め、月次レポートで実請求と見比べて薄ければ2.5に上げる**。値はDynamoDBの1行なのですぐ変えられる。過去の記録は計算時の値を保持するので遡って変わらない。

### 1ターンあたり・500円で遊べる量（Sakura）

| | 1ターン請求 | 500円で | 1日20分（約13ターン）なら |
|---|---|---|---|
| 返答ふつう | 約0.65円 | 約770ターン（約19時間） | 約2か月 |
| 返答長め | 約0.85円 | 約600ターン（約15時間） | 約1か月半 |

Cartesiaは1ターン約9円で、500円は約1.3時間。

## 4. 為替と手数料の扱い

- **為替は月初にECB値で固定**。市場レート（Googleの表示など）とは1〜2%ずれることがあるが、月単位の記録としては誤差の範囲。実勢に寄せたければ運用Lambdaを毎日更新に変えられる。
- **各社からの請求**はドル建て都度課金（OpenAI・Anthropic・Soniox・FishAudio）、前払いクレジット（Cartesia月額・Serperパック）、円建て（Sakura、Googleは請求アカウント次第）が混在する。カードで払う分には海外事務手数料（1.6〜2.2%）が乗る。
- 実支払いと記録額を一致させようとせず、**ずれはマージンで吸収し、月次レポートで確認する**。
- ユーザーから受け取る側の決済手数料（Stripe約3.6%、App Store 15〜30%）は別物で、売上から引かれる。

## 5. 従量課金の形

- **前払いポイント制**を採る。例: 500円分を購入し、会話のたびに請求額ぶんを減らす。未払いリスクが無く、少額決済の繰り返しを避けられ、ユーザーにも上限が見える。
- いまの記録（利用者・日・種別ごとの円額）がそのままポイント減算の元データになる。
- iOSアプリ内でポイントを売るとApp Store手数料がかかるため、Web購入の経路を検討する。規約・法規制は実装前に確認。
- アプリの声の選択画面に「この声は1回約9円」「ずんだもんは1回約0.7円」のように単価を出し、従量の納得感を作る。

## 6. ポケとも（シャープ）との比較

| | 1回あたり | 400回ぶん |
|---|---|---|
| ポケとも（ノーマル495円/400回、他プランも同単価、無制限3,300円） | 約1.24円 | 495円 |
| ToyTalker Sakura | 約0.65円 | 約260円 |
| ToyTalker Cartesia | 約9円 | 約3,600円 |

Sakuraならほぼ半額で、使わない月は0円。ポケともの1回1.24円は市場が受け入れている水準なので、マージンを上げる余地はある。

## 7. プレミアムボイス（声優の声など）の料金体系

- **使い放題の定額はしない**。声優クローン級の単価（1ターン原価約4.5円）だと、月730ターンで原価割れになる。子供が気に入って使い込むほど赤字になる構造は避ける。
- 採る形は「**月額固定（解放料）＋従量（今までどおり）**」。
  - 月額は声優へのライセンス料をまかなう。ライセンスが売上分配型なら月額は低めでも成立する。
  - 会話はその声の原価×2.0をポイントから消費（1回約9円）。使われ方に関係なく変動費は従量が必ずカバーする。
  - 二重取りに見えないよう、月額にポイントを少し含める（例: 月額500円に300円分のポイント込み）。
- 声優のライセンス条件（用途・期間・停止時の扱い・分配率）は料金設計より先に固める。AIによる声の合成は業界的に敏感なので契約を明確にする。
- 実装: `toytalker-voices` にプラン印を付け、アプリの出し分けに加えて**Lambda側でも加入者かを確認**してから合成する。コスト記録は声ごとの単価で計算しているので変更なし。

## 8. 今後の課題

- **単価をモデル単位にする**: 現在はプロバイダー単位（`google#llm`）。同じ会社で2つ目のモデルを使う前に、`google#llm#gemini-2.5-flash` → `google#llm` の順で探す二段構えにする。既存行のキーは変えず、モデル付きのキーで行を足す。
- **単価行の属性**: 2026-09-13に全行へ `provider` / `api_type` を属性として追加した（キーを `#` で分けた値）。コンソールでの絞り込みと集計コードの簡略化のためで、計算はこれまでどおりキーで引く。新しい行を足すときもこの2つ（モデル付きなら `model` も）を入れる。
- **Sonioxの見積もり**: 文字数から逆算しているが、実際は音声を流した時間で課金されている可能性がある。ESP32は聞いている間ずっと送るので、月次レポートの手動確認で最初に見る。
- **LLM入力トークン**: 会話履歴を長く持つほど膨らむ。履歴の上限を決めておくと原価が安定する。
- **相槌の定型音声化**: 原価よりレイテンシ改善の効果が大きい。別件として検討。
- **AWS Lambda**: 本文Lambdaは2GBでLLM・TTSの応答待ち中も課金される。記録外の原価では最大の項目。

## 9. 有料ツール（外部API）のコスト記録（2026-09-12）

- LLMのfunction callingで呼ぶツールのうち、外部に料金が発生するもの（現状はSerper検索）だけを `tool` 種別で回数課金として記録する。自前のLambda/DynamoDBを呼ぶだけの無料ツールは何も記録しない。検索は「調べ物をよくする子」と「雑談だけの子」で回数が大きく違うため、一律マージンではなく回数で数える。
- 単価は `toytalker-api-unit-prices` の `${provider}#tool` 行、`input_unit_type = "requests"`。`serper#tool` = $0.001/回（$50 / 5万クレジット、1検索=1クレジット、購入から6か月で失効）。1回検索のターンでツール代は約0.15円（マージン前）。
- 有料ツールを増やすとき: 本文Lambda2つ（App / ESP32）の `PAID_TOOLS` に `ツール名: { provider, model }` を1行足し、単価行を足す。アプリ側は円グラフの色を付けたい場合だけ `CHART_COLORS` に追加。無料ツールを増やすときは何もしない。
- 残骸: 最初は `search` 種別で実装し同日 `tool` へ汎用化した。`2026-09-12#<device>#search` の利用状況行と `serper#search` の単価行が1件ずつ残っている。参照されないので消してよい。

## 10. 月次運用レポートLambda（為替更新・請求突き合わせ・単価点検）

2026-09-12に `toytalker-ops-monthly-lambda` を追加。毎月1日 09:00 JST に動き、結果を1通のメールで送る。値の自動修正はしない。

### やること

1. **為替**: Frankfurter（ECB公表レート、キー不要）からUSD→JPYを取り、`toytalker-exchange-rates` に当月の行が無ければ作る。既存行は維持（`FX_OVERWRITE=true` で上書き）。
2. **先月の記録集計**: `toytalker-usage` を先月分でスキャンし、プロバイダー×種別ごとにマージン後の円額・マージン前のUSD実費・使用量をまとめる。
3. **各社の実績との突き合わせ**: APIで請求を取れる社（OpenAI・Anthropic）は差分と割合を出し、20%超なら要確認印。ElevenLabsは使用文字数。取れない社（Cartesia・Serper・Google・Soniox・Sakura・Fish Audio）は記録実費と確認先URLを並べる。
4. **点検**: 単価行が無くて記録されなかった呼び出し（記録側Lambdaの `[Pricing] missing price` ログをCloudWatchから検索）、180日以上更新されていない単価行、対象月の為替行の有無。
5. **通知**: SNSトピック `toytalker-ops-monthly` にメール。件名はASCII固定（`ToyTalker monthly cost report YYYY-MM`）。

### 記録側の変更（同日）

- App本文・ESP32本文・読み上げの3 Lambdaで、`toytalker-usage` に `cost_usd`（マージン前のUSD実費）を加算する。突き合わせはこの値で行う。2026-09-12より前の行は `cost_jpy / margin / usd_jpy_rate` で割り戻すため概算になる（レポートに行数を表示）。
- 単価行が無いときに `console.warn("[Pricing] missing price for <provider#api_type>")` を出す。以前は静かに記録されなかった。

### 構築と運用

- ディレクトリ: `backend/toytalker-ops-monthly-lambda/`
- 構築・更新はCDK（`infra/`、2026-09-16から）。SNSトピックとメール購読（宛先は `infra/config/stages.ts` の `opsEmail`）、実行ロール、Lambda（Node.js 24、5分、256MB）、EventBridge Scheduler `toytalker-ops-monthly`（`cron(0 9 1 * ? *)`、Asia/Tokyo）をスタックが作る。コード更新も `cd infra && npx cdk deploy --context stage=rnd`。新しいアカウントでは初回deploy後にメール内のリンクで購読を確認する。以前の `setup.sh` / `deploy.sh` は削除済み。
- 手動実行: `{"month":"2026-08","send":false}` のように対象月と送信有無を指定できる。`send:false` は戻り値の `report` に本文を返すだけでメールを送らない。`fx:false` で為替更新を省略。
- 環境変数:

| 変数 | 内容 |
|---|---|
| `OPS_SNS_TOPIC_ARN` | 必須。CDKが設定 |
| `FX_OVERWRITE` | `true` で当月の為替行を毎回上書き。既定は無い月だけ作成 |
| `STALE_PRICE_DAYS` | 単価行の鮮度しきい値。既定180 |
| `OPENAI_ADMIN_KEY` / `ANTHROPIC_ADMIN_KEY` | 任意。組織の請求額をAPIで取る管理者キー。読み取り専用に絞れず漏洩時の影響が大きいため、当面は置かない方針（レポートの数字と各社ダッシュボードを手で見比べる） |
| `ELEVENLABS_API_KEY` | 任意。使用文字数の取得。本文Lambdaと同じ値を設定済みだが `user_read` 権限が無く401になる。権限付きのキーに差し替えると取得できる |

### 確認と見直しの目安

- 2026-09-12に `{"month":"2026-08","send":false}` で8月分（利用者8人、合計81.77円、実費$0.27）を生成し、9-13にメール送信を確認。2026-09の為替行は154.04円（Frankfurter 2026-09-11）。8月以前は為替行が無く150円固定で記録されている。
- 差分が20%を超えて印が付いたら、まず単価行の単位・値を疑う（トークン種別の違い、キャッシュ料金、音声トークン換算など）。
- 「単価行なしの警告」が出たら `toytalker-api-unit-prices` に行を足す。足すまでその呼び出しは記録されない。
- 単価の自動取得はしない。各社がAPIで単価を公開しておらず、料金ページの読み取りは壊れやすいため。
- プロビジョニングプロファイル等の期限は別件（1年）。

## 11. 前払いポイント制の仕様（2026-09-13 合意、未実装）

第5節の方針（従量課金・前払いポイント・マージン2.0が売価）を実装できる粒度に落としたもの。前提は「ログインはCognito（Apple / Google / LINE）、決済はStripe Checkout、購入はWebページ」。認証の設計は [先送り項目](deferred-items.md) の「ユーザー認証」を参照。

### 11.1 決めたこと

| 項目 | 決定 |
|---|---|
| ポイントの単位 | 円。1ポイント=1円で、購入額がそのまま残高になる。表示も「残り 1,230円分」のように円で出す |
| 消費額 | 記録している請求額（マージン2.0後の円）をそのまま引く。単価表・為替・マージンの仕組みは変えない |
| 消費のタイミング | 会話は本文Lambda（App / ESP32）がターン終了時に `cost_total` を引く。読み上げも同様。相槌は引かない（マージンで吸収） |
| 無料枠 | 本体（ESP32）は `device_id` 単位で登録時に付与（初期値 300円分、本体価格に含める見せ方）。アプリだけの利用者は当面 `owner_id` 単位で100円分、認証導入後はアカウント単位に移す |
| 残高0のとき | 会話を止めない。「無料継続モード」としてTTSをずんだもん固定にし、1日50ターンまで続ける。超えたら本体が「ポイントがなくなったよ。おうちのひとにきいてね」と言って、その日は停止 |
| 購入 | Webの購入ページ（`toytalk.zakicorp.com/buy`）でログイン後、500 / 1,000 / 3,000円から選ぶ。Stripe Checkoutへ遷移し、カード・Apple Pay・Google Pay・Linkが使える |
| iOSアプリ | 残高と消費内訳の表示のみ。購入導線はアプリ内課金ルールに触れないよう、Webページの案内にとどめる（スマホ新法の運用が固まったら外部リンクを検討） |
| 通知 | 残高が100円を下回ったら1日1回プッシュ。購入完了時にプッシュ |
| 返金・調整 | 手動。運用者がレジャー（台帳）に調整行を書く |

### 11.2 データ

- **`toytalker-wallets`**（残高の要約、`owner_id` がキー）: `balance_jpy`、`free_mode_turns_today`、`free_mode_date`、`low_balance_notified_date`、`updated_at`。
- **`toytalker-wallet-ledger`**（台帳、`owner_id` ＋ `ts#type` がキー）: `type`（`grant` / `purchase` / `consume` / `adjust`）、`amount_jpy`（消費はマイナス）、`balance_after`、`ref`（`consume` は会話ログのキー、`purchase` はStripeのセッションID、`grant` は `device_id` など）、`memo`。
- 消費は会話ログの1行と1対1。`ref` に会話ログのキーを入れて重複消費を防ぐ。
- 残高更新はDynamoDBの原子的な加算（`ADD balance_jpy :delta`）で行い、読んでから書く方式にしない。

### 11.3 流れ

1. **付与**: 本体登録（`POST /devices`）時に、その `device_id` への付与が未実施なら台帳に `grant` を書いて残高に足す。アプリだけの利用者は初回の `owner_id` 作成時に小額を付与（認証導入後はアカウント作成時に変更）。
2. **消費**: 本文Lambdaがターン終了時、既存のコスト計算のあとに `cost_total` を残高から引き、台帳に `consume` を書く。読み上げLambdaも同じ。残高が負になっても会話は止めない（次のターンから無料継続モード）。
3. **残高確認**: 本文Lambdaはターン開始時に残高を読む。0以下なら無料継続モード（TTSをずんだもん固定、1日50ターンまで）。上限を超えたら停止の文言を返す。
4. **購入**: Web購入ページで金額を選ぶ → デバイス設定Lambdaが `owner_id` をメタデータに付けたStripe Checkoutセッションを作って返す → 支払い完了のWebhook（`checkout.session.completed`）をLambdaが受け、セッションIDが台帳に無ければ `purchase` を書いて残高に足す（同じWebhookが二重に来ても1回だけ処理）→ プッシュ通知。
5. **表示**: アプリの利用状況ページに残高と「今月の消費」を出す。消費内訳は既存の集計をそのまま使う。

### 11.4 認証との関係

- 購入ページで「誰の残高に足すか」を決めるには本人確認が要るので、**購入機能は認証（Cognito）の後**に出す。順番は「認証 → ウォレットと消費記録 → 購入ページ → プッシュ」。
- 認証前でも、付与と消費と残高表示は `owner_id` 単位で先に動かせる。無料枠だけで運用する期間になる。
- 認証導入時に `sub → owner_id` の対応表を作る方針なので、残高は `owner_id` のまま持ち続けられる。

### 11.5 手数料と最低購入額

- Stripeは国内カード3.6%、固定費なし。500円の購入で18円。PayPalは3.6%＋40円、Squareは3.25%〜で、カード決済はどこも3〜4%。App Store課金は15〜30%。
- 手数料と原価を引いた粗利を保つため、購入単位は500円以上にする。

### 11.6 未決定・確認事項

- 無料継続モードの1日上限（50ターン）と、停止時の文言。
- 本体1台あたりの無料枠（300円分）を本体価格にどう含めるか。
- Appleの外部リンクの扱い（スマホ新法の運用）を実装前に確認する。
- Stripe Checkoutで使える支払い手段は日本アカウントの設定次第。PayPalは当面入れない。
- 返金の運用ルール（未使用分のみ返すか）。

## 参考: 2026-09-10の市場調査（単価は当時のリスト値、要再確認）

- **Cartesiaの課金構造**: 月額サブスク＋クレジット枠、超過分は追加課金（純従量ではない）。Free $0/2万字（非商用のみ）、Pro $4/10万字、Startup $49/125万字、Scale $299/800万字。Pro〜Scaleで1文字あたりの単価はほぼ同じ（約$37〜40/100万字）で、違うのは月間の含有文字数だけ。Instantクローンは標準声と同単価・作成無料・個数無制限。PVCクローンは1.5倍。超過単価は非公開。商用利用はFree不可。
- **ElevenLabsのクローン保存数**: Free 3 / Starter 10 / Creator 30 / Pro 160 / Scale・Business 660。全ユーザーが親の声を登録する設計には構造的に不向きで、自前クローン基盤が要る理由の一つ。料金はモデル（Flash $50/100万字、Multilingual $100/100万字）で決まり、クローンかプリセットかは無関係。
- **自前GPUの運用形態（RunPod、RTX 5090 32GB）**: Pod常時起動 $0.99/時（月約¥10.7万）、Serverless $1.58/時（稼働分のみ）。GPU実稼働が1日15時間超ならPod、下回るならServerless。夜ピーク型ならServerless＋keep-warm。NVIDIAはGeForceのデータセンター商用利用に制約があるため、本格量産時はL40S/A100等への移行も検討。立ち上げは従量API、規模が出たら自前GPUが定石。
- **Aivis Cloud**（アニメ調）: ¥44,000/100万字でCartesiaの約7倍。アニメ路線を採るかは製品コンセプト次第。
- 当時の1時間の会話原価の試算（ずんだもん約¥40、Cartesia約¥99、ElevenLabs Flash約¥115）は、第2節の新しい前提（Cartesia $0.00005/字、実測に近いターン数）で置き換えた。

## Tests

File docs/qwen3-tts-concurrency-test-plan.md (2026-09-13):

# Qwen3-TTS 同時要求試験の計測方法と用語の定義

2026-09-12作成、2026-09-13に定義部分だけへ整理。[元実装の測定](qwen3-tts-capacity-2026-09-12.md) と [バッチエンジンの検証](qwen3-tts-batch-engine-2026-09-12.md) の表は、ここで定義した指標で集計している。旧版にあった試験手順・結果表・次の作業は、実施済みの分を上記2本と [調査の経緯](qwen3-tts-current-status.md) に移した。

## 目的と資材の置き場所

ToyTalkerで100人が同時に会話するために、RTX 5090による自前TTSがどこまで対応できるかを測り、Cartesia等の外部APIと比較する。

計画と製品としての判断は `toytalker/docs/`、試験プログラム・入力ケース・生の測定結果はTTS実装の隣に置く（実行手順は [TTS側README](../../tts-models/faster-qwen3-tts/benchmarks/concurrency/README.md)）。音声と生ログはGit対象外。

```text
tts-models/faster-qwen3-tts/benchmarks/concurrency/
├── README.md           # 環境準備・実行コマンド・結果の読み方
├── run.py              # HTTPストリーミング負荷クライアント（--capacity で遅延・枯渇を停止理由にせず記録）
├── cases.json          # 固定の日本語入力と試験条件
├── batch_selftest.py   # バッチ版のHTTPなし自己検証
└── results/<run-id>/   # 設定、要求別計測、GPU計測、集計
```

## 試験環境の3段階

1. **同じPCからlocalhost**: 負荷クライアントはHTTPのみでモデルやCUDAをロードしない。専用のPython仮想環境（標準ライブラリのみ）。既存監視とサーバーを二重起動しない。OS・GPU・ドライバー・Python・PyTorch・ライブラリの版・ソースのハッシュ・生成設定を記録する。
2. **公開経路**: 同じ要求をngrok経由で送り、ネットワーク・トンネルの影響を分ける。
3. **ToyTalker全体**: Lambda経由の会話と端末の実再生。HTTP試験だけでは、STT・LLMの待ち、Lambda中継、ESP32のプリバッファを含む体感速度は保証できない。

APIキーは環境変数から渡し、コマンド引数・MD・結果ファイルに値を記録しない。

## 試験ケース

実ユーザーの会話履歴を使わず、固定の日本語文を使う。全条件で同じケースを使い、長さと本文を結果に紐づける。

| ケース | 目安 | 用途 |
|---|---|---|
| 相槌 | 5〜15文字 | 短い要求が重なる場合 |
| 短文（short） | 30〜60文字 | 通常の先頭応答。既定は41文字の「今日は公園で〜」 |
| 中程度（medium） | 100〜200文字 | 複数文の返答 |
| 長文（long） | 400〜800文字 | 読み上げ・寝かしつけ |

最初は1話者で測り、次に異なる話者を混在させる。同時生成時には音声を保存して聞き比べ、内容欠落・声の混線・破損がないか確認する。

## 計測するもの

| 指標 | 定義・使い道 |
|---|---|
| 初回PCM到着時間（TTFA） | HTTP要求開始から最初の空でない音声データ受信まで。p50/p95/最大 |
| 完了時間 | 要求開始から受信終了まで |
| 受信時刻と累積PCMバイト数 | 初期バッファを仮定して再生中の枯渇をシミュレーション |
| 成功率・失敗内訳 | HTTPエラー、タイムアウト、不正PCM、音声異常を分ける |
| 総音声生成倍率 | 全件の生成音声秒数（末尾追加無音0.5秒を除外）÷バースト実時間。「実時間1秒あたり何秒分の音声を作れたか」で、対応人数ではない |
| 1件あたり実時間比 | 1要求の音声秒数÷その要求の完了時間。1倍を切ると再生が追いつかない |
| RTF | 生成完了までの実時間÷生成音声時間。小さいほど速い。既存ベンチの `RTF` 表示は音声時間÷実時間（速度倍率）なので混同しない |
| GPU | 使用率、VRAM、温度、電力を約1秒間隔で記録。別のデスクトップアプリも含む値 |

注意点:

- 初回PCMが無音の場合もあるため、TTFAは「聞こえる声の開始」と同義ではない。HTTPの受信単位もモデルの生成チャンクと一致しない。
- 音切れはチャンク間隔だけで判断せず、累積受信量と再生速度で評価する。模擬再生の初期バッファは683ms（ESP32のプリバッファ相当）を既定とし、必ず結果に記載する。保存WAVは待ち時間を詰めた音声なので、連続再生しても通信中の待ちは再現しない。
- 24kHz・16bit・モノラルは48,000バイト/秒。末尾の追加無音を含む転送音声時間と、除いた音声時間を分ける。
- p95はnearest-rank。10件では最大値と等しい。小標本のp95は参考値。
- ウォームアップ要求は本計測から除く。再起動直後の試験は別条件として記録する。
- 「同時HTTP要求数」「GPUが実際に並列生成する数」「同時会話人数」は別々に報告する。

## 暫定の評価基準

TTS単体で「初回PCM p95が1秒以内・要求エラーなし・再生シミュレーションで枯渇なし」を仮の目標とする。最終的な合格は実端末の設定・再生ログと、ユーザーが許容する応答時間で決める。有限回のエラー0件は将来のエラー率0を保証しないので、成功数・総数・継続時間を併記する。

100人対応の感度分析には「1人20秒に1回答、約8秒の返答」（約40音声秒/実時間秒）を使えるが、実測された利用パターンとは扱わない。

## 停止・回復条件

- GPUメモリ不足、サーバー異常終了、音声混線・破損が1回でもあれば新規投入を止める。
- クライアント切断でサーバーの生成が止まるとは仮定しない。投入停止後、残存処理・GPU負荷が落ち着くことを確認し、ヘルスと短文生成で回復を確認する。
- 正常に回復しない場合は [起動・復旧手順](tts-boot-recovery.md) に従う。負荷を上げた自動再試行はしない。

## 結果の保存形式

各runに `config.json`、要求別の `requests.jsonl`、受信時刻・累積バイト数、`gpu.csv`、`summary.json`。時刻は実行日と単調時計の経過時間を分ける。モデル・設定・入力ケース・話者ラベルで再現できるようにし、認証情報は保存しない。

## 未実施の試験

- 継続試験（15分以上かつ200要求以上）、要求到着率を固定した試験（待ち行列の増加を見る）。
- 100人分の会話模擬（各人の本文ブロックを順に要求し、再生時間と発話間隔を考慮して次ターンを開始。開始時刻の分散/集中、相槌あり/なしを分ける）。
- 音声認識による本文照合の自動化（現在は聴取のみ）。

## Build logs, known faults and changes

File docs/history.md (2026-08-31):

# toytalk
SS Bootcamp 3rd #2025

## プロジェクト
- 声をかけると返答してくれるAIおもちゃの作成
- 目的は親の時間確保
- 子供がおもちゃに夢中になると同時に、言葉のキャッチボール力の向上もできたらうれしい
- OpenAIのAPIを利用するため、会話のたびに料金が発生する
- APIキーを発行してセットすれば、課金分のみの利用が可能
- APIキーの設定が面倒であれば、月額課金でも利用できる
- 無料で使用することも可能。会話はできないが、ただおうむ返しをしたり、事前にセットした昔話を話してくれる、という機能もあると親としては助かる（実際はサーバー維持費用かかるので検討中）
- おもちゃイメージ　「まねっこぴょこぴょこアンパンマン」
  - https://www.amazon.co.jp/gp/product/B0B4RQ85ZQ/ref=sw_img_1?smid=AN1VRQENFRJN5&th=1

## 音声会話のしくみ
  1. STT（音声→テキスト）
  2. LLM
  3. TTS（テキスト→音声）

前提として
  - OpenAIのAPIキーが必要。API利用のたびに課金が発生する
  - 音声処理はスマホ側で行うため、スマホアプリが必要。課金状況の確認などもアプリで行う

## PJの流れ
- デモサイト構築：マイク→音声→テキスト→LLM→音声返答してくれるサイトを作る　→6月完了
- ラズパイに落とし込む　→7月完了
- スマホアプリを作って、スマホと連動させる
- おもちゃとしてデザインを決めて形にする
- →一旦ここまで出来たらうれしい

サービス化するなら
- 何よりも応答速度が課題：デモサイト上では1往復で5秒前後かかる。すべての処理が直列なのと、サーバーレス構成のためと思われる　→　一旦解決。初回応答まで安定して2秒程度に短縮できた。しかもサーバーレス
  - STT：ここが足を引っ張っているように感じる。websocket通信で高速化できないか検討中　※ここをブラウザのテキスト化機能にしたら（つまりSSTをなくしたら）、往復で1-4秒と速度アップした
  - LLM：4.1-miniを利用。かなり早いはず
  - TTS：回答内容をまとめてmp3にしている？ためか長文だと時間かかるように感じる。子供向けということで、LLMの回答内容をシンプルにすることで短縮できないか
  - ※最悪難しかったら、待ってる間に「相槌を打つ」機能の追加を検討。「そうだね～」、「なるほどね」、「ふむふむ」とかいろいろなパターンを使って時間を稼げないか検討
  - →OpenAIのRealTime APIを使えば、SST→LLM→TTSをリアルタイム&並列化できるため爆速になる。ただ、これには2つのデメリットがある
    - 利用料が高い
    - ボイスをカスタマイズ（キャラクター化）できない
  - この対策として、以下が考えられる
    - STT、LLM、TTSそれぞれ、Stream対応のAPIを利用して、自前でWebRTC環境を整備する
    - TTS（ボイス化）についてはさらにカスタマイズできるものを選ぶ　※Microsoft EdgeTTSが有力
    - 一方で開発が長引く可能性が高いので、どこまで対応するか線引きが必要になりそう
    - 一旦、動作が安定してる現状のサーバーレス構成で進めて、RealTime API利用など検証しつつ落としどころを探る
  - 20250901：速度問題は一旦解決。サーバーレス構成（Lambda）でも、LLM/TTSをストリーム処理することで、話初めの速度を改善できた。STTは現在スマホ側で処理しているので、スマホによって性能の差がある可能性あり
  - 20251005：STTも解決。Soniox STTで一時キーを発行することで、クライアント⇔Soniox間で直接やり取りする。認証は別途必要だが速度には大きく影響しない想定。これで、STT→LLM→TTSの並列化ができ、応答も2秒程度となった
- 音声の精度を高める（くしゃみとか物音も拾ってしまう）　→　スマホでなら問題なし。くしゃみとかキーボードなら拾わない
- アプリ上で課金管理をできるようにする
- 過去の会話を踏まえて会話する機能。3-5つくらいまで保持しして、あとは要約するとか工夫できないか（会話積み重ねると重くなる）　→　実装済み
- APIキー管理の仕組みを設計・実装
- 会話保持、振り返り機能の実装
- 無料で利用する場合のおうむ返し機能、昔話をしてくれる機能の設計・実装
- ボイスとテンションを子供向けにする　→　いろいろなTTSを試しているが、なかなかない。リアルタイム性 + キャラっぽいのがあまりない。ニジボイスは申請中

## デモサイト　※対応済み
- https://toytalk.zakicorp.com/demo/index.html

### レビューいただいてからの修正点まとめ
- 音声を検知するまで何もしない処理にする
- キャラクター入れる
- アニメーション入れる
- キャラクター選択できる
  - 画像をそれぞれ用意する
- 処理時間を表示させる
- 会話ボタンを押したらずっと会話する　※キャンセルボタンないが、一旦再読み込みでキャンセルとなる
- 今までの会話を保持しながら話す
- iPhoneでも音声出力できるようにする
- デモサイトの構成図


### メモ：セキュリティ観点で本番は以下の設定が必要
| 設定項目 | 開発中 | 本番 |
| --- | --- | --- |
| `Access-Control-Allow-Credentials` | （なし） | `true`（必要なら） |
| CloudFront キャッシュキー | （特になし） | `Origin` を含めて設定 |
| APIキーの保護 | Lambda環境変数 | Secrets Manager利用（チーム開発でなければ必須ではない） |

## マイコン化について
- ラズパイだとおもちゃの価格が跳ね上がる。価格を抑えるためにはマイコン化が必要
- マイコン化すると、ラズパイと比べスペックがかなり落ちて機能も制限される
- そのため、おもちゃはマイク/スピーカーの中継にして、BlueTooth/wifiでスマホと連携して、スマホ側で音声処理をする構成にする
- そうすると、スマホアプリ起動が前提になるので、親としては子供がおもちゃと会話している間はスマホを操作できなくなってしまう可能性がある
- アプリをバックグラウンド起動させて対応できないか検討中　※最悪、親がスマホを触る際は、会話モード以外（オウム返しや一方的な話）で楽しんでもらう
- [ToyTalkマイコン実装はこちら](mcu.md)

## ラズパイ対応 ver1　※対応済み
- デモサイトでやってること（ブラウザ部分）をラズパイに置き換えるだけ


- マイク/スピーカーはUSBタイプのものをそれぞれ用意してラズパイに装着
- VADは簡単なものを実装。咳や物音といった短い音を無視（0.4秒以内の音声は検知しない）
- 音声を流している間は、割り込みのマイク入力はoff　※ありだとスピーカーの音をマイクが拾う、の無限ループになるため。マイコン化を考えると制御の難易度が高そう
- 今後の課題も同じく、返答速度・声がメイン
  - 速度：①base64処理とmp3/wavの処理最適化、②システムプロンプトを会話特化に、③相槌機能追加（Lambdaの2重化）で、改善&カバーを検討
  - 声：今のOpenAI APIでチューニングしつつ、別のTTS用APIを検討

## ラズパイ対応 ver2　※対応済み
- スマホアプリ（一旦iOS）を作り、アプリ側で音声処理を行う。ラズパイはマイク/スピーカーの中継だけ（マイコン化に向けた対応）


- このあたりで速度改善、VAD、声のチューニングの本格対応を始める？マイコン化を優先？
- 一旦速度改善できた。Lambdaのストリーミング処理でLLM/TTSをそれぞれ並列化。STT（VADも）は一旦スマホ側で処理。今後SSTもサーバー側へ移行する
- iOSアプリのインストール（TestFlifhtというアプリも必要）：https://testflight.apple.com/join/Aq5D8b62
- [ToyTalkアプリ実装はこちら](../app/README.md)
- 調査進めたところ、アプリ経由でなくても、おもちゃ（ESP32 s3という安価なマイコン）⇔中継サーバーで直接やりとりできそう。ver2の構成はとりやめて、ver3の構成にする

## ラズパイ対応 ver3　※対応済み
- SST（音声のテキスト化）をサーバー側に移行する　→　実装済み
- アプリによるラズパイへのwifi設定は実装していないが、マイコン化が実現できそうなのでそちらを優先で対応する


## マイコン対応　※対応中
- スマホアプリを経由せず、マイコン⇔API基盤（STT + LLM + STT）で音声会話できるか検証
- wifi設定もアプリからできるようにする


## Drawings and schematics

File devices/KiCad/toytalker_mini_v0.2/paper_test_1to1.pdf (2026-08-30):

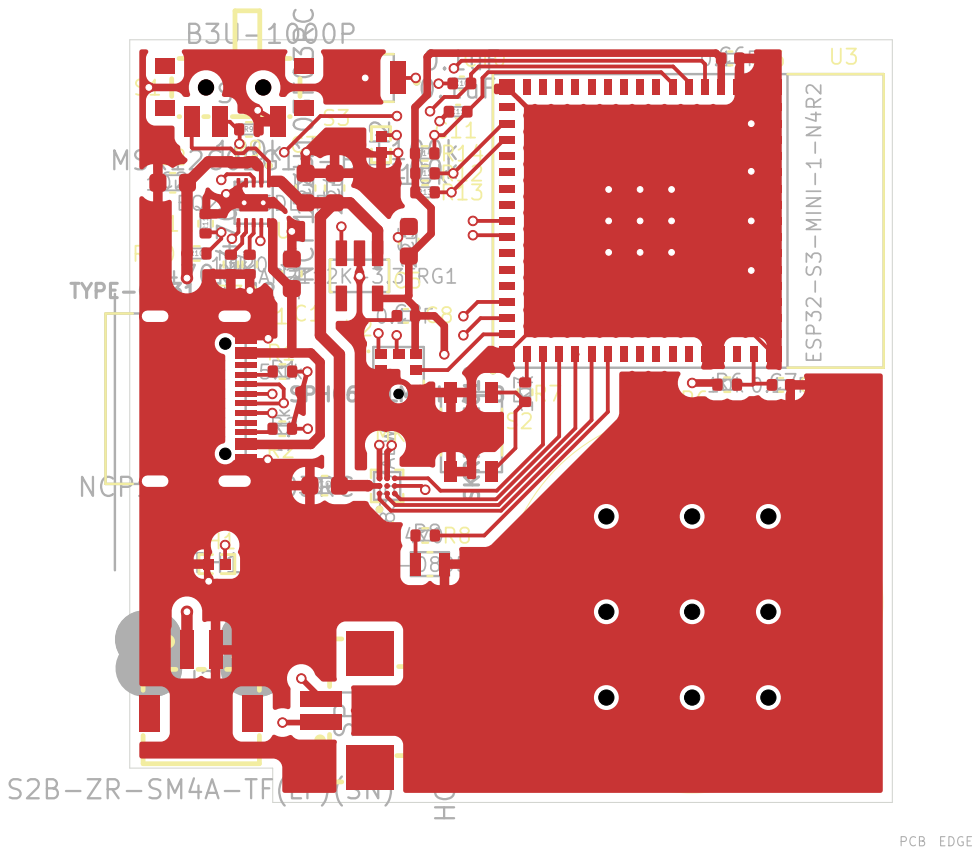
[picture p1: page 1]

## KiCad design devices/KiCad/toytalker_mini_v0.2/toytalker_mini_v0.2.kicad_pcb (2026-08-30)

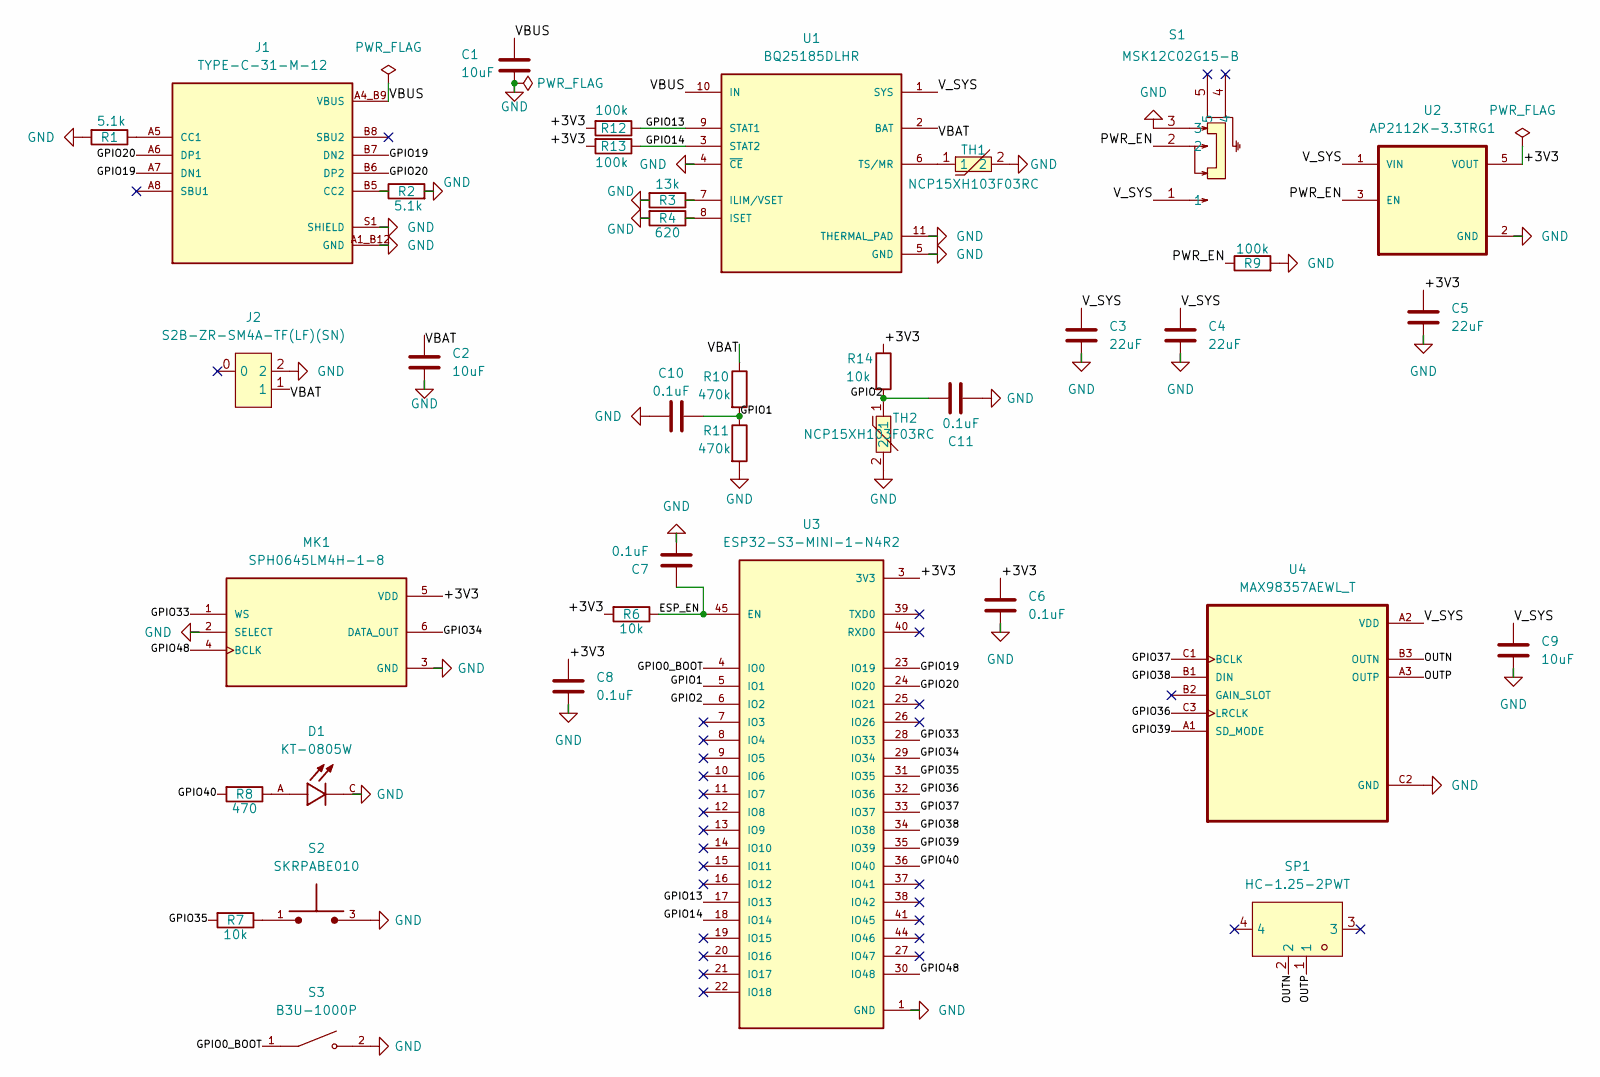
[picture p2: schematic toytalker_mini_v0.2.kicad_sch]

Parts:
C1, C2, C9: 10uF; C_0603_1608Metric
C3, C4, C5: 22uF; C_0603_1608Metric
C6, C7, C8, C10, C11: 0.1uF; C_0402_1005Metric
D1: KT-0805W; LED_KT-0805W; PARTREV 2017.05.16
J1: TYPE-C-31-M-12; HRO_TYPE-C-31-M-12; PARTREV 2020.12.08
J2: S2B-ZR-SM4A-TF(LF)(SN); CONN-SMD_S2B-ZR-SM4A; LCSC Part C265329
MK1: SPH0645LM4H-1-8; MIC_SPH0645LM4H-B
R1, R2: 5.1k; R_0402_1005Metric
R3: 13k; R_0402_1005Metric
R4: 620; R_0402_1005Metric
R6, R7, R14: 10k; R_0402_1005Metric
R8: 470; R_0402_1005Metric
R9, R12, R13: 100k; R_0402_1005Metric
R10, R11: 470k; R_0402_1005Metric
S1: MSK12C02G15-B; SW-SMD_MSK12C02G15-B; LCSC Part C22435661
S2: SKRPABE010; SW_SKRPABE010
S3: B3U-1000P; SW_B3U-1000P
SP1: HC-1.25-2PWT; CONN-SMD_2P-P1.25-HC-1.25-2PWT; LCSC Part C2845379
TH1, TH2: NCP15XH103F03RC; R0402; LCSC Part C77131
U1: BQ25185DLHR; IC_BQ25185DLHR; PARTREV OCTOBER 2023
U2: AP2112K-3.3TRG1; SOT95P285X140-5N; PARTREV 2-2
U3: ESP32-S3-MINI-1-N4R2; XCVR_ESP32-S3-MINI-1-N4R2; PARTREV v0.6
U4: MAX98357AEWL_T; BGA9N40P3X3_134X143X69N

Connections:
/+3V3: C5.1, C6.1, C8.1, MK1.5 (VDD), R6.2, R12.2, R13.2, R14.1, U2.5 (VOUT), U3.3 (3V3)
/ESP_EN: C7.1, R6.1, U3.45 (EN)
/GPIO0_BOOT: S3.1, U3.4 (IO0)
/GPIO1: C10.1, R10.2, R11.1, U3.5 (IO1)
/GPIO2: C11.1, R14.2, TH2.1, U3.6 (IO2)
/GPIO13: R12.1, U1.9 (STAT1), U3.17 (IO13)
/GPIO14: R13.1, U1.3 (STAT2), U3.18 (IO14)
/GPIO19: J1.A7 (DN1), J1.B7 (DN2), U3.23 (IO19)
/GPIO20: J1.A6 (DP1), J1.B6 (DP2), U3.24 (IO20)
/GPIO33: MK1.1 (WS), U3.28 (IO33)
/GPIO34: MK1.6 (DATA_OUT), U3.29 (IO34)
/GPIO35: R7.2, U3.31 (IO35)
/GPIO36: U3.32 (IO36), U4.C3 (LRCLK)
/GPIO37: U3.33 (IO37), U4.C1 (BCLK)
/GPIO38: U3.34 (IO38), U4.B1 (DIN)
/GPIO39: U3.35 (IO39), U4.A1 (SD_MODE)
/GPIO40: R8.2, U3.36 (IO40)
/GPIO48: MK1.4 (BCLK), U3.30 (IO48)
/OUTN: SP1.2, U4.B3 (OUTN)
/OUTP: SP1.1, U4.A3 (OUTP)
/PWR_EN: R9.1, S1.2, U2.3 (EN)
/VBAT: C2.1, J2.1, R10.1, U1.2 (BAT)
/V_SYS: C3.1, C4.1, C9.1, S1.1, U1.1 (SYS), U2.1 (VIN), U4.A2 (VDD)
GND: C1.2, C2.2, C3.2, C4.2, C5.2, C6.2, C7.2, C8.2, C9.2, C10.2, C11.2, D1.C, J1.A1_B12 (GND), J1.B1_A12 (GND), J1.S1 (SHIELD), J1.S2 (SHIELD), J1.S3 (SHIELD), J1.S4 (SHIELD), J2.2, MK1.2 (SELECT), MK1.3 (GND), R1.2, R2.2, R3.2, R4.2, R9.2, R11.2, S1.3, S2.3, S2.4, S3.2, TH1.2, TH2.2, U1.4 (~CE), U1.5 (GND), U1.11 (THERMAL_PAD), U1.12, U1.13, U2.2 (GND), U3.1 (GND), U3.2 (GND), U3.42 (GND), U3.43 (GND), U3.46 (GND), U3.47 (GND), U3.48 (GND), U3.49 (GND), U3.50 (GND), U3.51 (GND), U3.52 (GND), U3.53 (GND), U3.54 (GND), U3.55 (GND), U3.56 (GND), U3.57 (GND), U3.58 (GND), U3.59 (GND), U3.60 (GND), U3.61 (GND), U3.61_1 (GND), U3.61_2 (GND), U3.61_3 (GND), U3.61_4 (GND), U3.61_5 (GND), U3.61_6 (GND), U3.61_7 (GND), U3.61_8 (GND), U3.62 (GND), U3.63 (GND), U3.64 (GND), U3.65 (GND), U4.C2 (GND)
unnamed: D1.A, R8.1
unnamed: J1.A5 (CC1), R1.1
unnamed: J1.B5 (CC2), R2.1
unnamed: R7.1, S2.1, S2.2
unnamed: R3.1, U1.7 (ILIM/VSET)
unnamed: R4.1, U1.8 (ISET)
unnamed: TH1.1, U1.6 (TS/MR)
VBUS: C1.1, J1.A4_B9 (VBUS), J1.B4_A9 (VBUS), U1.10 (IN)

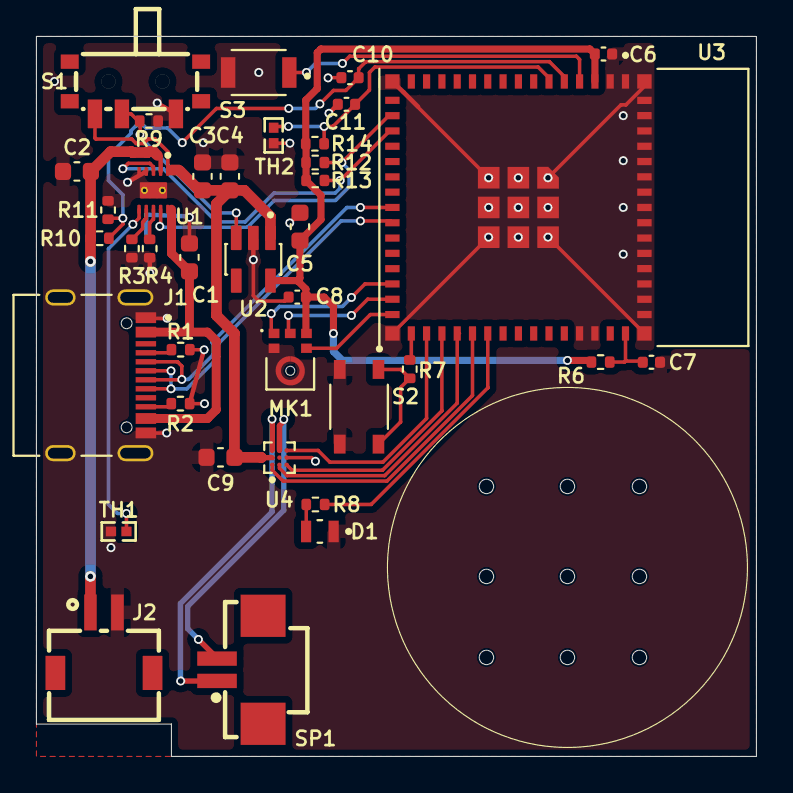
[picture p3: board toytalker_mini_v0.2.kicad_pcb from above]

Board: 2 copper layers, 40.0 x 40.0 mm, 38 parts (0 on the bottom side), 32 nets.

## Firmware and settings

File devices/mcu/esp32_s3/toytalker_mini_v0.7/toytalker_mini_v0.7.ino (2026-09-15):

// toytalker_mini_v0.7 — AEC voice barge-in（実機確認済み構成）+ OTA
// v0.5安定版・v0.6音量方式を保持。このフォルダには最新のソースだけを置き、配布した版は
// git のタグ fw-<版> で残す（tools/publish-firmware.sh が付ける）。版は FirmwareVersion.h。
// OTA: OtaUpdater.h / AmazonRootCA.h、起動時の更新確認（startNormalOperation）、LED_BLINK_OTA。
// NLP既定=AGGR（実機構成）。設計は docs/esp32-ota-settings-plan.md。
// 受信(producer)とI2S再生(consumer)をFreeRTOSタスクで分離し、PSRAMリングバッファで吸収
// LED制御はすべてdigitalWrite

#include <WiFi.h>
#include <WiFiClientSecure.h>
#include <HTTPClient.h>
#include <WebSocketsClient.h>
#include <ArduinoJson.h>
#include "StreamCompletion.h"
#include <driver/i2s_std.h>
#include <esp_wifi.h>
#include <esp_mac.h>  // esp_read_mac (BLEアドバタイズ名用)
#include <BLEDevice.h>
#include <BLEServer.h>
#include <BLEUtils.h>
#include <BLE2902.h>
#include <Preferences.h>
#include <esp_heap_caps.h>  // heap_caps_get_largest_free_block ([DIAG]/[MEM]計測用)
#include <atomic>
#include <esp_timer.h>
#include <math.h>
#include "VoiceLevelGate.h"
#include "VoiceLevelMeter.h"
#include "BargeInFlag.h"
#include "ChunkedBodyDecoder.h"
#include "AecMonitor.h"
#include "TlsMemory.h"
#include "SttMicFilter.h"
#include "SonioxPreconnect.h"
#include "FirmwareVersion.h"
#include "OtaUpdater.h"
#include <esp_arduino_version.h>

// ==== デバッグ設定 ====
#define DEBUG_MEMORY 0

// ==== WiFi（NVSから読み込み） ====
String wifiSSID = "";
String wifiPassword = "";
String pendingSSID = "";
String pendingPassword = "";
Preferences preferences;

// ==== BLE UUIDs（アプリ側toy.tsxと一致） ====
#define SERVICE_UUID           "12345678-1234-1234-1234-123456789abc"
#define CHAR_SSID_UUID         "12345678-1234-1234-1234-123456789ab1"
#define CHAR_PASSWORD_UUID     "12345678-1234-1234-1234-123456789ab2"
#define CHAR_COMMAND_UUID      "12345678-1234-1234-1234-123456789ab3"
#define CHAR_STATUS_UUID       "12345678-1234-1234-1234-123456789ab4"
#define CHAR_MAC_UUID          "12345678-1234-1234-1234-123456789ab5"

// ==== デバイスモード ====
enum DeviceMode {
  MODE_NORMAL,
  MODE_BLE_PROV,
  MODE_CONNECTING
};
DeviceMode currentMode = MODE_CONNECTING;

// ==== BLE ====
BLEServer* pServer = NULL;
BLECharacteristic* pStatusChar = NULL;
bool bleDeviceConnected = false;
bool oldBleDeviceConnected = false;
String deviceMacAddress = "";

// ==== Lambda (TTS) - Binary Streaming ====
const char* LAMBDA_HOST = "koufofwm3w4tidbe52crbyhpyq0cshss.lambda-url.ap-northeast-1.on.aws";
const char* LAMBDA_PATH = "/";

// ==== Lambda (Backchannel) ====
const char* BACKCHANNEL_HOST = "birb7yjw4nkldidcza4xfiyn5e0taluh.lambda-url.ap-northeast-1.on.aws";
const char* BACKCHANNEL_PATH = "/";

// ==== Lambda (Soniox Key) ====
const char* SONIOX_LAMBDA_URL = "https://ug5fcnjsxa22vtnrzlwpfgshd40nngbo.lambda-url.ap-northeast-1.on.aws/";

// ==== Soniox ====
const char* SONIOX_WS_URL = "stt-rt.soniox.com";
const int SONIOX_WS_PORT = 443;
String sonioxKey;
String sonioxModel = "stt-rt-v4";

// ==== I2S PIN ==== (v0.2基板: マイク/アンプでBCLK・WSも分離)
#define PIN_MIC_BCLK 48
#define PIN_MIC_WS   33
#define PIN_MIC_DATA 34
#define PIN_AMP_BCLK 37
#define PIN_AMP_WS   36
#define PIN_AMP_DIN  38
#define PIN_AMP_SD   39
#define SAMPLE_RATE_STT 16000
#define SAMPLE_RATE_TTS 24000

// ==== LED & Button ====
#define PIN_LED      40
#define PIN_BUTTON   35

// ==== 電源・温度・充電（v0.2基板新設。Step 2bで読み取り実装予定） ====
#define PIN_VBAT_ADC   1   // 470k×2分圧: 実電圧=読み値×2。ADC1系なのでWiFi中も測定可
#define PIN_BOARD_TEMP 2   // TH2分圧(基板温度)
#define PIN_CHG_STAT1  13  // BQ25185 STAT1(100kプルアップ済みオープンドレイン)
#define PIN_CHG_STAT2  14  // BQ25185 STAT2

// LED状態（PWMなし、digitalWriteのみ）
enum LEDMode {
  LED_OFF,
  LED_ON,          // 点灯 = 録音中（話してOK）
  LED_BLINKING,    // 600ms周期 = 再生中
  LED_BLINK_SLOW,  // 1.2s周期 = 準備中（起動〜録音準備完了）
  LED_BLINK_FAST,  // 300ms周期 = BLE設定モード
  LED_BLINK_OTA    // 120ms周期 = ファーム更新中（電源を切らない）
};

volatile LEDMode currentLEDMode = LED_OFF;
volatile bool blinkState = false;
hw_timer_t* ledTimer = NULL;
bool ampOn = false;
BargeInFlag bargeInRequested;
volatile bool sonioxPreconnectPending = false;  // 再生中の先行WS接続が進行中か

// (最初の関数定義。Arduinoの自動プロトタイプはこの直前に入るので、enum等より後に置く)
// OTA後の初回起動でコアが自動で有効印を付けるのを止める。有効印は startNormalOperation() で
// Wi-Fi接続とSonioxキー取得に成功してから ota::confirmRunningImage() が付ける。
// それより前に落ちる版はブートローダーが旧版へ戻す。コア側はCなので extern "C" が要る。
extern "C" bool verifyRollbackLater() { return true; }

void IRAM_ATTR onBargeInButton() {
  bargeInRequested.setFromISR(PIN_AMP_SD);
}

// 確保失敗フックでは固定領域への記録だけ行う。Serialやheap APIを呼ばない。
static portMUX_TYPE allocFailureMux = portMUX_INITIALIZER_UNLOCKED;
static uint32_t allocFailureCount = 0;
static size_t allocFailureLastSize = 0;
static uint32_t allocFailureLastCaps = 0;

void IRAM_ATTR recordAllocationFailure(size_t size, uint32_t caps, const char*) {
  portENTER_CRITICAL_SAFE(&allocFailureMux);
  ++allocFailureCount;
  allocFailureLastSize = size;
  allocFailureLastCaps = caps;
  portEXIT_CRITICAL_SAFE(&allocFailureMux);
}

// loop側の会話境界で出力。失敗のない回もdelta=0を残す。
void logMemoryCheckpoint(const char* stage) {
  static uint32_t reportedFailures = 0;
  uint32_t count, caps;
  size_t size;
  portENTER_CRITICAL_SAFE(&allocFailureMux);
  count = allocFailureCount;
  size = allocFailureLastSize;
  caps = allocFailureLastCaps;
  portEXIT_CRITICAL_SAFE(&allocFailureMux);
  Serial.printf("[ALLOC_FAIL] checkpoint=%s delta=%lu total=%lu last_size=%u last_caps=0x%08lX\n",
                stage, (unsigned long)(count - reportedFailures), (unsigned long)count,
                (unsigned)size, (unsigned long)caps);
  reportedFailures = count;
  // 内部RAMとPSRAMの管理情報・canaryを検査。再生中の読み取りループでは実行しない。
  bool intact = heap_caps_check_integrity_all(true);
  Serial.printf("[HEAP_CHECK] checkpoint=%s ok=%d internal_free=%lu max_blk=%lu\n",
                stage, intact,
                (unsigned long)heap_caps_get_free_size(MALLOC_CAP_INTERNAL | MALLOC_CAP_8BIT),
                (unsigned long)heap_caps_get_largest_free_block(MALLOC_CAP_INTERNAL | MALLOC_CAP_8BIT));
  tls_memory::printStats(stage);
}


// ボタン状態
int lastButtonReading = HIGH;
int buttonState = HIGH;
int lastButtonState = HIGH;
unsigned long lastDebounceTime = 0;
const unsigned long debounceDelay = 50;

unsigned long buttonPressStart = 0;
bool buttonLongPressTriggered = false;
const unsigned long LONG_PRESS_MS = 1500;

// ==== WiFi接続状態（イベントベース） ====
volatile bool wifiConnected = false;
volatile bool wifiGotIP = false;

// ==== Soniox STT 状態 ====
WebSocketsClient ws;
static SonioxPreconnect sonioxPreconnect;
static bool sonioxPlaybackPhase = false; // loop-only; worker never changes UI/STT state
String partialText = "";
String sonioxFinalBuf = "";
String lastFinalText = "";
unsigned long lastPartialMs = 0;
const unsigned long END_SILENCE_MS = 800;
bool armed = false;
bool isRecording = false;
bool endpointDetected = false;
bool i2sRecordReady = false;
bool micInstalled = false;
// loopタスク専用。大きな配列をloop/startSTTRecordingのスタックに重ねない。
// 再生監視タスクは自身のraw[320]を使用し、ここには触れない。
static int32_t sttRaw[512];
static int16_t sttPcm[512];
static SttMicFilter sttMicFilter;
static bool sttInputFirstBlock = true;
unsigned long sttRestartMs = 0;  // STT再開計測用

// ==== TTS 受信状態 ====
int curSegmentId = -1;
String responseText = "";
uint8_t* currentPcmBuffer = NULL;
size_t currentPcmSize = 0;
const uint32_t TTS_SEGMENT_GAP_MS = 400;  // 文の区切りに追加する間（先頭・末尾には入れない）
bool ttsAudioQueued = false;
bool ttsGapPending = false;
static std::atomic<uint32_t> ttsTurnStartMs{0};
static std::atomic<bool> ttsFirstWriteLogged{false};
static bool ttsFirstPcmLogged = false;  // loopのみ
static uint32_t ttsRingWaitMs = 0;      // producerのみ
static uint32_t sonioxServiceMaxMs = 0;

String sonioxStartMessage() {
  return "{\"api_key\":\"" + sonioxKey + "\","
         "\"model\":\"" + sonioxModel + "\","
         "\"audio_format\":\"pcm_s16le\",\"sample_rate\":16000,\"num_channels\":1,"
         "\"enable_partial_results\":true,\"enable_endpoint_detection\":true,"
         "\"language_hints\":[\"ja\",\"en\"]}";
}

bool sonioxIsConnected() {
  return !sonioxPreconnect.ownsClient() && ws.isConnected();
}

void finishSonioxPreconnect() {
  SonioxPreconnect::Result result;
  if (!sonioxPreconnect.takeResult(result, webSocketEvent)) return;
  Serial.printf("[WS_PRECONNECT] elapsed_ms=%lu ready=%d cancelled=%d stack_free=%lu\n",
                (unsigned long)result.elapsedMs, result.ready, result.cancelled, (unsigned long)result.stackFree);
  sonioxPreconnectPending = false;
  if (result.ready) sonioxConnectionReady(); // start message was already sent by the worker
}

void prepareSonioxDuringPlayback() {
  sonioxPlaybackPhase = true;
  finishSonioxPreconnect();
  if (sonioxPreconnect.ownsClient()) return;
  ws.disconnect();
  ws.beginSSL(SONIOX_WS_URL, SONIOX_WS_PORT, "/transcribe-websocket");
  ws.onEvent(webSocketEvent);
  ws.enableHeartbeat(15000, 3000, 2);
  sonioxPreconnectPending = true;
  const bool background = sonioxPreconnect.start(sonioxStartMessage());
  Serial.printf("[WS_PRECONNECT] started background=%d core=0\n", background);
}

// During playback, connect/start runs on Core 0 while loop keeps receiving TTS.
// Connected-client polling and all application callbacks stay on loop.
void serviceSoniox(const char* stage) {
  finishSonioxPreconnect();
  if (sonioxPreconnect.ownsClient()) return;
  if (sonioxPlaybackPhase && !ws.isConnected() && sonioxPreconnect.available()) {
    if (bargeInRequested) return; // STT restart will decide how to reconnect
    if (sonioxPreconnect.start(sonioxStartMessage())) {
      sonioxPreconnectPending = true;
      return;
    }
  }
  const uint32_t started = millis();
  const bool connectedBefore = ws.isConnected();
  ws.loop();
  const uint32_t elapsed = millis() - started;
  if (elapsed > sonioxServiceMaxMs) sonioxServiceMaxMs = elapsed;
  if (elapsed >= 50) {
    Serial.printf("[WS_TIMING] stage=%s blocked_ms=%lu connected_before=%d connected_after=%d\n",
                  stage, (unsigned long)elapsed, connectedBefore, ws.isConnected());
  }
}

void logFirstTtsWrite() {
  if (!ttsFirstWriteLogged.exchange(true)) {
    Serial.printf("[LATENCY] first_tts_i2s_ms=%lu (copy completion, not acoustic start)\n",
                  (unsigned long)(millis() - ttsTurnStartMs.load()));
  }
}

// 終了待ちの内訳を計測。出力は最初の録音パケット送信後にまとめる。
// lastI2sWriteMsはDMAへのコピー完了時刻であり、スピーカーの発声終了時刻ではない。
static std::atomic<uint32_t> lastI2sWriteMs{0};
static std::atomic<uint32_t> playbackI2sBytes{0};
static i2s_chan_handle_t micRx = nullptr;
static i2s_chan_handle_t playbackTx = nullptr;
static AecMonitor aecMonitor;  // internal SRAM: ISR capture queues must not be in PSRAM
static portMUX_TYPE playbackDmaMux = portMUX_INITIALIZER_UNLOCKED;
static uint32_t playbackDmaSize = 0, playbackDmaOverflows = 0;
static uint32_t lastPlaybackDmaOverflows = 0;
static constexpr size_t PLAY_DMA_COUNT = 8;
static constexpr size_t PLAY_DMA_FRAMES = AEC_TX_SAMPLES; // actual 1023 frames / 4092 bytes
struct DmaTailTiming {
  bool valid = false;
  bool confirmed = false;
  uint32_t blockBytes = 0;
  uint32_t confirmAfterBytes = 0;
  uint32_t tailPaddingUs = 0;
  int64_t confirmedUs = 0;
  int64_t ampOffUs = 0;
};
static DmaTailTiming dmaTailTiming;

bool IRAM_ATTR onMicDma(i2s_chan_handle_t, i2s_event_data_t* event, void*) {
  aecMonitor.captureRx(event);
  return false;
}
bool IRAM_ATTR onPlaybackDma(i2s_chan_handle_t, i2s_event_data_t* event, void*) {
  portENTER_CRITICAL_ISR(&playbackDmaMux);
  playbackDmaSize = event->size;
  portEXIT_CRITICAL_ISR(&playbackDmaMux);
  aecMonitor.captureTx(event);
  return false;
}
bool IRAM_ATTR onPlaybackDmaOverflow(i2s_chan_handle_t, i2s_event_data_t*, void*) {
  portENTER_CRITICAL_ISR(&playbackDmaMux);
  ++playbackDmaOverflows;
  portEXIT_CRITICAL_ISR(&playbackDmaMux);
  return false;
}

uint32_t i2sTimeoutMs(TickType_t ticks) {
  return ticks == portMAX_DELAY ? UINT32_MAX : ticks * portTICK_PERIOD_MS;
}
esp_err_t readMicI2s(void* data, size_t len, size_t* bytes, TickType_t timeout) {
  *bytes = 0;
  return micRx ? i2s_channel_read(micRx, data, len, bytes, i2sTimeoutMs(timeout)) : ESP_ERR_INVALID_STATE;
}
esp_err_t releaseI2sChannel(i2s_chan_handle_t& channel) {
  if (!channel) return ESP_OK;
  esp_err_t err = i2s_channel_disable(channel);
  if (err != ESP_OK && err != ESP_ERR_INVALID_STATE) return err;
  err = i2s_del_channel(channel);
  if (err == ESP_OK) channel = nullptr;
  return err;
}

// 最後のバッファ内の位置を知るため、相槌・区切り無音も含む全コピー量を数える。
esp_err_t writePlaybackI2s(const void* data, size_t len, size_t* written, TickType_t timeout) {
  *written = 0;
  esp_err_t err = playbackTx ? i2s_channel_write(playbackTx, data, len, written, i2sTimeoutMs(timeout))
                            : ESP_ERR_INVALID_STATE;
  playbackI2sBytes.fetch_add(*written, std::memory_order_relaxed);
  return err;
}

// 新APIのEOF callbackから実バッファサイズと空きキュー溢れを取得する。
// 音声参照のcapture欠落は別途 [AEC_STATS] で扱う。
void pollPlaybackI2sEvents(bool monitoring) {
  portENTER_CRITICAL(&playbackDmaMux);
  uint32_t bytes = playbackDmaSize;
  uint32_t overflows = playbackDmaOverflows;
  portEXIT_CRITICAL(&playbackDmaMux);
  if (monitoring && (bytes != dmaTailTiming.blockBytes || overflows != lastPlaybackDmaOverflows))
    dmaTailTiming.valid = false;
  dmaTailTiming.blockBytes = bytes;
  lastPlaybackDmaOverflows = overflows;
}

void beginDmaTailTiming(bool writerStopped) {
  dmaTailTiming = DmaTailTiming{};
  pollPlaybackI2sEvents(false);  // 再生中の古いイベントを取り除く
  uint32_t total = playbackI2sBytes.load(std::memory_order_relaxed);
  uint32_t block = dmaTailTiming.blockBytes;
  if (!writerStopped || total == 0 || block == 0 || block > PLAY_DMA_FRAMES * 4 || block % 4 || total % 4) return;
  uint32_t used = total % block;
  if (used == 0) used = block;
  // 残りを埋め、他のN-1個も埋め、元のバッファに最初の1フレームを書けるまで。
  // 再取得はドライバのDMA完了キューを待つ。IRQ時刻そのものではなく完了確認の上限時刻。
  dmaTailTiming.confirmAfterBytes = PLAY_DMA_COUNT * block - used + 4;
  dmaTailTiming.tailPaddingUs = (uint64_t)(block - used) * 1000000 / (SAMPLE_RATE_TTS * 4);
  dmaTailTiming.valid = true;
}
static uint32_t turnTimingSequence = 0;
struct TurnEndTiming {
  bool pending = false;
  bool firstReadSeen = false;
  bool interrupted = false;
  bool flushCompleted = false;
  bool wsReadyAtRecord = false;
  uint32_t turn = 0;
  uint32_t receiveEndMs = 0;
  uint32_t lastWriteMs = 0;
  uint32_t parkedMs = 0;
  uint32_t flushWriteMs = 0;
  uint32_t flushWsMs = 0;
  uint32_t flushEndMs = 0;
  uint32_t ampOffMs = 0;
  uint32_t micSetupDoneMs = 0;
  uint32_t recordOnMs = 0;
  uint32_t firstReadMs = 0;
};
static TurnEndTiming turnEndTiming;

void printTurnEndTiming(uint32_t firstSendMs) {
  if (!turnEndTiming.pending) return;
  const TurnEndTiming& t = turnEndTiming;
  Serial.printf("[TURN_END] turn=%lu interrupted=%d recv_end_ms=%lu last_i2s_copy_ms=%lu stop_return_ms=%lu flush_end_ms=%lu flush_ok=%d flush_write_ms=%lu flush_ws_ms=%lu\n",
                (unsigned long)t.turn, t.interrupted, (unsigned long)t.receiveEndMs,
                (unsigned long)t.lastWriteMs, (unsigned long)t.parkedMs,
                (unsigned long)t.flushEndMs, t.flushCompleted,
                (unsigned long)t.flushWriteMs, (unsigned long)t.flushWsMs);
  Serial.printf("[TURN_END] turn=%lu amp_off_ms=%lu mic_setup_done_ms=%lu record_on_ms=%lu ws_ready=%d first_read_ms=%lu first_send_ms=%lu amp_to_mic_ms=%lu amp_to_send_ms=%lu\n",
                (unsigned long)t.turn, (unsigned long)t.ampOffMs,
                (unsigned long)t.micSetupDoneMs, (unsigned long)t.recordOnMs,
                t.wsReadyAtRecord, (unsigned long)t.firstReadMs, (unsigned long)firstSendMs,
                (unsigned long)(t.micSetupDoneMs - t.ampOffMs),
                (unsigned long)(firstSendMs - t.ampOffMs));
  Serial.printf("[DMA_TAIL] turn=%lu valid=%d confirmed=%d block_bytes=%lu tail_padding_us=%lu confirmed_us=%lld after_confirm_us=%lld\n",
                (unsigned long)t.turn, dmaTailTiming.valid, dmaTailTiming.confirmed,
                (unsigned long)dmaTailTiming.blockBytes, (unsigned long)dmaTailTiming.tailPaddingUs,
                (long long)dmaTailTiming.confirmedUs,
                (long long)(dmaTailTiming.valid && dmaTailTiming.confirmed ? dmaTailTiming.ampOffUs - dmaTailTiming.confirmedUs : -1));
  turnEndTiming.pending = false;
}

// ==== 相槌（Backchannel）状態 ====
bool backchannelEnabled = true;
const int BACKCHANNEL_TRIGGER_CHARS = 7;

int utf8Len(const String& s) {
  int count = 0;
  for (int i = 0; i < s.length(); ) {
    uint8_t c = (uint8_t)s.charAt(i);
    if (c < 0x80) i += 1;
    else if (c < 0xE0) i += 2;
    else if (c < 0xF0) i += 3;
    else i += 4;
    count++;
  }
  return count;
}
volatile bool backchannelFetching = false;
volatile bool backchannelReady = false;
volatile bool backchannelFired = false;
volatile bool backchannelAbort = false;
uint8_t* backchannelPcm = NULL;
size_t backchannelPcmSize = 0;
String backchannelText = "";
TaskHandle_t backchannelTaskHandle = NULL;

const int MAX_PAST_BACKCHANNELS = 10;
String pastBackchannels[MAX_PAST_BACKCHANNELS];
int pastBackchannelCount = 0;

void addPastBackchannel(const String& text) {
  if (pastBackchannelCount >= MAX_PAST_BACKCHANNELS) {
    for (int i = 0; i < pastBackchannelCount - 1; i++) {
      pastBackchannels[i] = pastBackchannels[i + 1];
    }
    pastBackchannelCount--;
  }
  pastBackchannels[pastBackchannelCount] = text;
  pastBackchannelCount++;
}

// ==== セッションID ====
String sessionId = "";

// ==== 会話履歴 ====
const int MAX_HISTORY = 5;
struct Message {
  String role;
  String content;
};
Message conversationHistory[MAX_HISTORY * 2];
int historyCount = 0;

// ==== 音量調整 ====
const float VOLUME = 1.5;  // デジタルゲイン（クリップ保護あり）。2.0はノイズ増の割に音量差わずかで、1.5がスイートスポット

// ==== TTS設定 ====
const char* TTS_PROVIDER = "ElevenLabs";
const char* TTS_CHARACTER = "default";
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
void loop() {
  if (currentMode == MODE_BLE_PROV) {
    finishSonioxPreconnect(); // collect cancelled job without touching a running socket
    handleButtonLongPress();
    if (!bleDeviceConnected && oldBleDeviceConnected) {
      delay(500);
      if (pServer) pServer->startAdvertising();
    }
    oldBleDeviceConnected = bleDeviceConnected;
    delay(10);
    return;
  }

  serviceSoniox("recording_loop");
  handleButtonLongPress();

  // ボタンデバウンス
  int reading = digitalRead(PIN_BUTTON);
  if (reading != lastButtonReading) lastDebounceTime = millis();
  if ((millis() - lastDebounceTime) > debounceDelay) {
    if (reading != buttonState) {
      buttonState = reading;
    }
  }
  lastButtonReading = reading;

  // 録音データ送信
  if (isRecording && wifiGotIP && sonioxIsConnected()) {
    static uint32_t lastSend = 0;
    static uint32_t sendOk = 0, sendFail = 0;
    static uint32_t lastStats = 0;
    static uint16_t micPeak = 0;  // -32768の絶対値32768も表現する
    static int32_t rawMin = INT32_MAX, rawMax = INT32_MIN;  // 生データの振れ幅(DCオフセットとクロストークの判別用)
    static uint32_t rawSample = 0;
    if (millis() - lastSend > 5) {
      auto& raw = sttRaw;
      auto& pcm = sttPcm;
      size_t n = 0;
      readMicI2s((void*)raw, sizeof(raw), &n, portMAX_DELAY);
      if (n > 0 && turnEndTiming.pending && !turnEndTiming.firstReadSeen) {
        turnEndTiming.firstReadMs = millis();
        turnEndTiming.firstReadSeen = true;
      }
      int samples = n / sizeof(int32_t);
      sttMicFilter.convert(raw, pcm, samples);
      for (int i = 0; i < samples; i++) {
        uint32_t a = pcm[i] >= 0 ? int32_t(pcm[i]) : -int32_t(pcm[i]);
        if (a > micPeak) micPeak = a;
        if (raw[i] < rawMin) rawMin = raw[i];
        if (raw[i] > rawMax) rawMax = raw[i];
      }
      if (samples > 0) rawSample = (uint32_t)raw[0];
      bool ok = ws.sendBIN((uint8_t*)pcm, samples * sizeof(int16_t));
      if (ok) {
        if (samples > 0) {
          const uint32_t sentAtMs = millis();
          const auto buttonTiming = bargeInRequested.buttonTiming(true);
          if (buttonTiming.pressedUs != 0) {
            Serial.printf("[BUTTON] irq_to_first_send_ms=%lu\n",
                          (unsigned long)((esp_timer_get_time() - buttonTiming.pressedUs) / 1000));
          }
          const uint32_t triggerAtMs = voiceTriggerMs.exchange(0);
          if (triggerAtMs != 0) {
            Serial.printf("[VOICE] trigger_to_first_send_ms=%lu\n", (unsigned long)(sentAtMs - triggerAtMs));
          }
          printTurnEndTiming(sentAtMs);  // 毎ターン最初の音声送信だけ。sendOkの統計リセットとは独立。
          printVoiceLevelSummary();
          if (sttInputFirstBlock) {
            Serial.printf("[STT_INPUT] first_block_samples=%d dc=%ld clips=%lu zero_samples=%lu\n", samples,
                          (long)sttMicFilter.dc(), (unsigned long)sttMicFilter.clips(),
                          (unsigned long)sttMicFilter.zeros());
            sttInputFirstBlock = false;
          }
        }
        sendOk++;
        if (sendOk == 1 && sttRestartMs > 0) {
          Serial.printf("⏱️ STT [%lums] First audio packet sent\n", millis() - sttRestartMs);
          sttRestartMs = 0;
        }
      } else {
        sendFail++;
      }
      lastSend = millis();
    }
    if (millis() - lastStats > 5000) {
      statsRecordRssi();  // 録音中(待機側)のRSSIも記録
      Serial.printf("[STT] send ok=%d fail=%d peak=%d rawMin=%ld rawMax=%ld raw0=0x%08lX RSSI=%d heap=%d\n",
                    sendOk, sendFail, micPeak, (long)rawMin, (long)rawMax, (unsigned long)rawSample, WiFi.RSSI(), ESP.getFreeHeap());
      sendOk = 0; sendFail = 0; micPeak = 0;
      rawMin = INT32_MAX; rawMax = INT32_MIN;
      lastStats = millis();
    }
  }

  // Sonioxエンドポイント検出
  if (endpointDetected && partialText.length() > 0) {
    if (partialText != lastFinalText) {
      lastFinalText = partialText;
      sendToLambdaAndPlay(partialText);
    }
    endpointDetected = false;
    armed = false;
    partialText = "";
    sonioxFinalBuf = "";
  }
  // 無音検出フォールバック
  else if (armed && partialText.length() > 0 && (millis() - lastPartialMs) >= END_SILENCE_MS) {
    if (partialText != lastFinalText) {
      lastFinalText = partialText;
      sendToLambdaAndPlay(partialText);
    }
    armed = false;
    partialText = "";
    sonioxFinalBuf = "";
  }
}

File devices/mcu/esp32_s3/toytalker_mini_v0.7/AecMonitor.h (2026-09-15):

#pragma once
#include <Arduino.h>
#include <driver/i2s_std.h>
#include <esp_aec.h>
#include <esp_heap_caps.h>
#include <esp_timer.h>
#include <math.h>
#include <new>
#include "AecCapture.h"
#include "AecSignal.h"
#include "AecMicHeadroom.h"
#include "AecGateEnergy.h"
#include "AecBargeGate.h"
#include "VoiceLevelMeter.h"

constexpr bool AEC_ENABLED = true;  // false: new I2S driver + original level monitor, for comparison
constexpr bool AEC_RESET_EACH_TURN = true; // compare against the old retained filter state
// Default is AGGR (1), the configuration verified on the device (2026-09-12).
// Build with -DTOYTALKER_AEC_NLP_LEVEL=0 to compare against NORMAL.
#ifndef TOYTALKER_AEC_NLP_LEVEL
#define TOYTALKER_AEC_NLP_LEVEL 1
#endif
static_assert(TOYTALKER_AEC_NLP_LEVEL == 0 || TOYTALKER_AEC_NLP_LEVEL == 1,
              "AEC comparison supports NORMAL(0) and AGGR(1) only");
constexpr aec_nlp_level_t AEC_NLP_LEVEL = static_cast<aec_nlp_level_t>(TOYTALKER_AEC_NLP_LEVEL);
constexpr const char* AEC_NLP_LABEL = TOYTALKER_AEC_NLP_LEVEL == 0 ? "NORMAL" : "AGGR";
constexpr uint32_t AEC_MIC_SAMPLES = 512;   // FD API: 32 ms at 16 kHz
static_assert(AEC_MIC_SAMPLES == AEC_BARGE_FRAME_SAMPLES, "barge-in hold must match AEC frame size");
constexpr uint32_t AEC_TX_SAMPLES = 1023;   // 4092-byte stereo DMA buffer at 24 kHz
constexpr uint32_t AEC_MIC_HOLD_MS = 96;    // maximum wait for matching TX EOF, not a fixed delay
constexpr int32_t AEC_REFERENCE_ADVANCE_MS = 16; // causal margin for filter, not an acoustic delay measurement

// A single static instance lives in internal SRAM. ISR callbacks only access
// its two small SRAM capture queues. Larger history/held audio lives in PSRAM
// and is accessed ONLY by the monitor task. No allocation/logging/DSP in ISR.
class AecMonitor {
  struct RxBlock { int64_t endUs; uint32_t sequence; int32_t data[AEC_MIC_SAMPLES]; };
  struct TxBlock { int64_t endUs; uint32_t sequence; int16_t data[AEC_TX_SAMPLES]; };
  struct MicBlock { int64_t endUs; uint32_t sequence, clips, preScaleClips; bool continuous; int16_t data[AEC_MIC_SAMPLES]; };
  struct Pending { MicBlock blocks[8]; uint32_t head = 0, tail = 0; };
  using History = aec_signal::ReferenceHistory<AEC_TX_SAMPLES, 16>;
  struct Stats {
    uint32_t paired = 0, missing = 0, pendingDrops = 0, clockResets = 0, clips = 0;
    uint32_t preScaleClips = 0;
    uint32_t gateMicRms = 0, gateOutRms = 0, dcRejectedFrames = 0;
    int32_t micMean = 0, outMean = 0;
    uint32_t cpuMaxUs = 0, slowFrames = 0, micRms = 0, refRms = 0, outRms = 0;
    uint64_t micEnergy = 0, outEnergy = 0;
  };
 public:
  bool init() {
    if (!AEC_ENABLED) { Serial.println("[AEC] disabled; raw level monitor only"); return false; }
    uint32_t internalBefore = heap_caps_get_free_size(MALLOC_CAP_INTERNAL | MALLOC_CAP_8BIT);
    uint32_t psramBefore = heap_caps_get_free_size(MALLOC_CAP_SPIRAM | MALLOC_CAP_8BIT);
    void* historyMem = heap_caps_malloc(sizeof(History), MALLOC_CAP_SPIRAM | MALLOC_CAP_8BIT);
    if (historyMem) history_ = new (historyMem) History{};
    void* pendingMem = heap_caps_malloc(sizeof(Pending), MALLOC_CAP_SPIRAM | MALLOC_CAP_8BIT);
    if (pendingMem) pending_ = new (pendingMem) Pending{};
    for (auto& buffer : buffers_) {
      buffer = static_cast<int16_t*>(heap_caps_aligned_alloc(16, AEC_MIC_SAMPLES * sizeof(int16_t),
                                                          MALLOC_CAP_INTERNAL | MALLOC_CAP_8BIT));
    }
    if (storageReady()) handle_ = createHandle();
    if (!handle_) {
      Serial.println("[AEC] init failed or unsupported frame size; raw level monitor only");
      release();
      return false;
    }
    Serial.printf("[AEC] ready=1 mode=FD_LOW_COST nlp=%s frame=%lu max_ref_wait_ms=%lu ref_advance_ms=%ld detect_only=%d barge_rms=%lu barge_hold_ms=%lu min_retained_pct=%lu clip_recovery_ms=%lu reset_each_turn=%d\n",
                  AEC_NLP_LABEL, (unsigned long)AEC_MIC_SAMPLES, (unsigned long)AEC_MIC_HOLD_MS, (long)AEC_REFERENCE_ADVANCE_MS,
                  AEC_BARGE_DETECT_ONLY, (unsigned long)AEC_BARGE_RMS, (unsigned long)AEC_BARGE_HOLD_MS,
                  (unsigned long)AEC_BARGE_MIN_RETAINED_PERCENT, (unsigned long)AEC_BARGE_CLIP_RECOVERY_MS,
                  AEC_RESET_EACH_TURN);
    Serial.printf("[AEC_MEM] internal_delta=%ld psram_delta=%ld internal_free=%lu max_blk=%lu\n",
                  (long)internalBefore - (long)heap_caps_get_free_size(MALLOC_CAP_INTERNAL | MALLOC_CAP_8BIT),
                  (long)psramBefore - (long)heap_caps_get_free_size(MALLOC_CAP_SPIRAM | MALLOC_CAP_8BIT),
                  (unsigned long)heap_caps_get_free_size(MALLOC_CAP_INTERNAL | MALLOC_CAP_8BIT),
                  (unsigned long)heap_caps_get_largest_free_block(MALLOC_CAP_INTERNAL | MALLOC_CAP_8BIT));
    return true;
  }
  // Only before any channel/callback/task is running (initialization failure).
  void release() {
    if (handle_) aec_destroy(handle_);
    handle_ = nullptr;
    heap_caps_free(history_); history_ = nullptr;
    heap_caps_free(pending_); pending_ = nullptr;
    for (auto& buffer : buffers_) { heap_caps_free(buffer); buffer = nullptr; }
  }
  bool ready() const { return handle_ != nullptr; }
  void start(uint32_t generation) {
    if (!storageReady()) return;
    // The previous monitor task has acknowledged stop, and capture is disabled.
    // Input time/history restarts each turn, so the library's adaptive filter
    // and buffered audio must start a new session too. No public reset API is
    // exposed by the installed SDK; only recreate the DSP handle, not capture storage.
    const int64_t resetStarted = esp_timer_get_time();
    const bool recreate = !handle_ || (AEC_RESET_EACH_TURN && turnStarted_);
    if (recreate) {
      if (handle_) aec_destroy(handle_);
      handle_ = createHandle();
    }
    turnStarted_ = true;
    Serial.printf("[AEC_RESET] generation=%lu enabled=%d recreated=%d ready=%d elapsed_us=%lu internal_free=%lu psram_free=%lu\n",
                  (unsigned long)generation, AEC_RESET_EACH_TURN, recreate, ready(),
                  (unsigned long)(esp_timer_get_time() - resetStarted),
                  (unsigned long)heap_caps_get_free_size(MALLOC_CAP_INTERNAL | MALLOC_CAP_8BIT),
                  (unsigned long)heap_caps_get_free_size(MALLOC_CAP_SPIRAM | MALLOC_CAP_8BIT));
    if (!ready()) {
      // Keep reusable storage and retry next turn; caller uses detect-only raw
      // monitoring this turn. Do not reuse a possibly contaminated old instance.
      summaryPending_ = false;
      Serial.println("[AEC] turn reset failed; raw level monitor only, retry next turn");
      return;
    }
    // No old DMA callback can publish while capture is disabled.
    rx_.reset(); tx_.reset();
    rxSequence_ = txSequence_ = 0;
    history_->reset(); pending_->head = pending_->tail = 0;
    rxClock_.reset(); txClock_.reset(); lowPass_.reset();
    micLevels_.reset(); outLevels_.reset(); stats_ = Stats{};
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

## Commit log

2026-08-26 Add auto-retry to app GET requests for flaky-network resilience
    TIB会場での「キャラクター一覧の取得に失敗」の対応。調査の結果、
    リクエストはLambdaに到達し全件正常応答していたが、電波の細い環境で
    レスポンスが端末まで完走できず、アプリ側のfetchが失敗していた。
    - lib/fetchWithRetry.ts 新設: 最大2回の自動リトライ(バックオフ付き)。
    冪等なGET専用(POST/PUTは二重実行防止のため対象外)
    - settings.tsx / toy.tsx のGET系(キャラ・ボイス・LLM・カスタムボイス・
    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
2026-08-26 Add v0.2 design docs (pinmap/power/checklist) and new-part KiCad libraries
    v0.2回路改修の設計確定ドキュメント一式:
    - PINMAP.md: I2S分離・GPIO3解放・電池ADC(GPIO1)・温度ADC(GPIO2)・STAT(13/14)
    - PARTS_AND_POWER.md: 電源フロー、部品役割検証、v0.1→v0.2部品単位差分
    - SCHEMATIC_CHECKLIST.md: 課題16件の対応表+回路図編集手順A〜F+発注BOM
    - easyeda_lib/: 新部品3種(ZH電池コネクタC265329 / MX1.25スピーカーC2845379 /
    スライドスイッチC22435661)のシンボル・フットプリント・3Dモデル
    (easyeda2kicadでEasyEDAから変換、3Dパスは${KIPRJMOD}基準に修正済み)
    - sym-lib-table / fp-lib-table: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
2026-08-29 Complete v0.2 schematic: ERC clean, new parts, temp sensing, EN-mode power
    - New connectors: J2=JST ZH (S2B-ZR-SM4A-TF), SP1=HC-1.25-2PWT (MX1.25),
    S1=MSK12C02G15-B slide switch in EN-mode (signal-only via PWR_EN + R9 100k)
    - Charge temp protection: TH1 (NCP15XH103F03RC) on BQ25185 TS/MR
    - Board temp readout: TH2 + R14 divider on GPIO2 (ADC1_CH1)
    - Battery voltage divider on GPIO1, STAT1/2 to GPIO13/14 with 100k pullups
    - LED R8 47R -> 470R, amp VDD direct to V_SYS, I2S pins separated
    - Fix BQ25185 SYS pin type to power_out; footprint links now use
    project 'footprints' lib; register 3 missing symbol libs project-locally
    - ERC: 0 errors, 0 warnings; all nets verified against PINMAP.md via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
    [toytalker_mini_v0.2.kicad_sch]
2026-08-29 Import v0.2 schematic changes into PCB and remove stale v0.1 footprints
    - Update board from schematic: new connectors (ZH battery, MX1.25 speaker,
    MSK12C02 slide switch), thermistors TH1/TH2, new passives R9-R14/C10/C11
    - Remove 4 ghost footprints left from v0.1: old SH connectors (J2/SP1),
    old SSAJ110100 switch, R5 (replaced by TH1)
    - Keep 9 board-only speaker grille hole footprints
    - File format upgraded to KiCad 10 on save
    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
    [toytalker_mini_v0.2.kicad_pcb]
2026-08-29 Reorganize v0.2 docs: single source of truth per file, fix stale values
    - New PARTS_LIST.md: current values/nets extracted from schematic (the
    canonical BOM reference); purpose headers added to all four docs
    - Deduplicate: remove 3 copies of parts tables from PARTS_AND_POWER /
    SCHEMATIC_CHECKLIST, keep rationale text
    - Fix stale values found by cross-check: R4 620ohm (was 600), R8 470ohm
    final (was 150 tentative), R5 removal noted, SH->ZH stale reference
    - Record ESP32-S3-MINI-1 true size 15.4x20.5mm (antenna 5.05mm included)
    and layout decisions (U3 rot270, left-edge switch, battery cable notch)
    Claude-Session: https://claude.a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
2026-08-29 Finalize v0.2 component placement: antenna in-board, bottom battery notch
    - U3 rotated 270deg at (41.3,21.5): full 15.4x20.5mm module incl antenna
    inside board (right edge 0.45mm margin), 2mm routing channel on top,
    antenna strip covered by new all-layer keepout rule area
    - Battery connector J2 at bottom edge facing 6x1.8mm cable notch (x25-31);
    battery mounts flipped, leads exit bottom-right (case/RFQ note)
    - S1 slide switch on left edge, knob outboard; SP1 mouth toward speaker
    (connector orientations verified from pad/housing geometry)
    - Thermistors stay on front side (single-side assembly, thermal vias later)
    - Monitoring passives moved to old J2 area on left edge; C6 in top chann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
    [toytalker_mini_v0.2.kicad_pcb]
2026-08-30 Reassign 9 signal pins for routing-optimal layout; add full route plan
    - Pins chosen from final hand placement: mic I2S -> IO33/34/48 (left column
    bottom, 4mm west to mic), amp I2S+SD -> IO36-39 (bottom row, south lane),
    BUTTON -> IO35, LED -> IO47; ADC/BOOT/USB/STAT/EN unchanged
    - Schematic labels moved via computed pin endpoints; ERC 0/0; netlist diff
    verified: exactly 9 nets changed, old GPIO4-12 nets eliminated
    - PINMAP.md: new table + firmware defines (v0.5)
    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
    [toytalker_mini_v0.2.kicad_sch]
2026-08-30 Move LED to IO40; placement QA complete, all decap distances pass
    - LED reassigned IO47->IO40 (bottom row): IO47's west path to R8 was
    blocked by C9/S2/MK1 gaps (3 routes checked); IO40 rides the S2-east
    lane with the amp bundle, no B-side jump needed
    - ERC 0/0, netlist verified: /GPIO40={R8-2,U3-36}, GPIO47 eliminated
    - User rework: C1 to 2.2mm from U1.IN with VBUS reroute, C2 4.1mm,
    CC resistors tucked to J1, TH1 relocated away from charger heat
    (19mm, fixes self-heating false charge-stop), TH2 near module kept
    as deliberate ESP32-area sensor (paired with internal die sensor)
    - Fixed C10/C11 footprint symbol-link corruption from earlier template
    copy (duplicate C6/C11 removed,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
    [toytalker_mini_v0.2.kicad_pcb, toytalker_mini_v0.2.kicad_sch]
2026-08-30 Complete v0.2 routing: all nets routed, GND fully stitched, DRC clean
    - All 66 nets routed (user hand-routing + planned B-side jumps, all
    west of module; ESP32 underside and antenna B.Cu kept pristine)
    - GND infrastructure: 9-via thermal farm under ESP32 (datasheet land
    pattern), 4 antenna-side stitch vias (Espressif HW guideline), solid
    zone connects on U3/U1/MK1/J1, U1 thermal holes net-assigned,
    TH1/TH2 thermal vias, 20+ stitch vias for isolated pour pockets
    - Fixed 4 isolated GND clusters found by union-find connectivity
    analysis (incl. U1 charger group fenced in by B-side jumps; final
    link found by BFS maze-solver on B.Cu)
    - Legacy v0.1 antenna keepouts stranded off-board in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
    [toytalker_mini_v0.2.kicad_pcb, toytalker_mini_v0.2.kicad_sch]
2026-08-30 Final GND QA pass: solid connects on S3/R9, cleanup, all audits green
    - S3/R9 pads set to solid zone connection (last starved-thermal items)
    - Redundant via + stub near S3 removed (leftover from two-pass fix)
    - Full QA verified: unconnected 0, schematic parity clean (17 hits =
    9 board-only speaker holes, 2 = intentional U1 thermal-hole GND),
    B.Cu sanctuary clean, antenna strip clean, decap distances pass,
    via ledger 64 vias all accounted (farm 9 / antenna 4 / stitch 18 /
    signal layer-changes 33 in consistent pairs)
    - Remaining 25 DRC items all triaged benign (documented); exclusion
    marking deferred to pre-order checklist
    Claud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
    [toytalker_mini_v0.2.kicad_pcb]
2026-08-30 Add v0.2 production files as ordered from JLCPCB (2026-08-31)
    - Gerbers (13 files), BOM, CPL, IPC netlist from Fabrication Toolkit
    - Ordered: 5 boards, 2-layer 1.0mm green, top-side PCBA, ~$150 incl
    shipping; factory ship date 2026-09-03
    - All 24 BOM lines matched (new parts auto-matched by embedded LCSC:
    J2=C265329, S1=C22435661, SP1=C2845379, TH1/TH2=C77131;
    ESP32=C3013941, mic=C19272537 stock was 10/min 6)
    - JLC placement preview offsets hand-corrected for EasyEDA-origin parts
    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
    [bom.csv, designators.csv, positions.csv]
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2026-09-06 Fix backchannel task String leak before task deletion
    [toytalker_mini_v0.5.ino]
2026-09-06 Document ESP32 TLS memory investigation and backchannel leak fix results
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2026-09-09 Add v0.6 voice monitoring with per-turn microphone reset
    Keep voice-triggered stopping disabled while testing concurrent recording and playback. Harden HTTP chunk decoding, reduce loop stack use, and record the successful 10-turn device test.
    [toytalker_mini_v0.6.ino]
2026-09-10 Reduce AEC false interruptions and reset state between turns
    [AecMonitor.h, toytalker_mini_v0.7.ino]
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2026-09-10 Fix backchannel hint before playback and document handoff
    [toytalker_mini_v0.7.ino]
2026-09-10 Add Cartesia and correct TTS cost comparison in cost estimate
    - Cartesia Sonic(標準/クローン)を単価表・時間/月額比較に追加
    - Cartesia課金構造(サブスク+超過)、Pro/Startupは単価ほぼ同一で枠が違う点を明記
    - ElevenLabsクローン保存数(スロット)上限を追記
    - 初稿のCartesia過小見積り(¥8〜12/時)を訂正、実効$37〜40/100万字=ElevenLabs Flash同水準に修正
    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
2026-09-11 feat: supervise local TTS and ngrok at Windows startup
    Replace logon-only startup with a noninteractive boot task and process recovery. Preserve the previous task XML and document rollback. Six unit tests and the noninteractive GPU/network probe passed; actual reboot and crash-recovery tests remain pending.
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2026-09-12 Clarify app connection errors and save device investigation
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2026-09-12 Add Cartesia TTS provider and tool cost tracking
    - Add Cartesia (sonic-3.6, /tts/bytes) to the five TTS Lambdas alongside
    ElevenLabs: PCM 24kHz for conversation/backchannel, native mp3 for read-aloud.
    Default voice comes from CARTESIA_DEFAULT_VOICE_ID; voice IDs are UUIDs.
    - Record paid LLM tool calls (Serper web search) as api_type "tool" via a
    PAID_TOOLS map and "requests" unit pricing; free tools stay inside LLM tokens.
    Chat logs keep tool_usage/cost_tool and usage detail returns them.
    - Fix backchannel deploy.sh: externalize @aws-sdk/client-lambda, add
    createRequire banner for bundled undici (ESP32), fail fast on bundle errors.
    - App usage page: add "tool" category, Cartesia/Se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
2026-09-13 Add monthly ops report Lambda and raw USD cost recording
    - toytalker-ops-monthly-lambda: on the 1st of each month save the USD-JPY
    rate (ECB via Frankfurter), aggregate last month's recorded cost per
    provider, compare with provider bills where an API exists, check stale or
    missing unit price rows, and email the result via SNS. setup.sh creates the
    topic, roles, function and EventBridge schedule; deploy.sh updates code.
    - Recording Lambdas (app, ESP32, read-aloud) store cost_usd (pre-margin) in
    toytalker-usage and warn when a unit price row is missing.
    - Docs: docs/ops-monthly-report.md, docs/pricing-and-cost-model.md (cost
    structure, margin 2.0, prepaid pay-per-use, premium voice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
2026-09-13 Move the TTS public route from ngrok to Cloudflare Tunnel (tts.zakicorp.com)
    - supervisor.py: config.json "public_url" があればその固定URLを /health 確認のうえ
    Lambda 5本へ同期する（ngrokは予備として監視継続）。Cloudflareが Python-urllib の
    User-Agent を403で弾くため独自UAを送る
    - switch-api.ps1: -PublicUrl で public_url を設定（'' でngrokへ戻す）
    - cloudflared-service-fix.ps1: Windowsサービスの ImagePath に --config/--logfile を明示
    （service install は --config を保存しない）
    - docs/tts-boot-recovery.md: 公開経路のランブック（所在・正常確認・復旧・ngrokへの戻し方）
    - CLAUDE.md: 公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
2026-09-13 Fall back to Sakura when the primary TTS provider fails (429/5xx)
    - Main Lambdas (app, ESP32): per-sentence synthesis retries 429/5xx after
    300/600 ms, then switches the rest of the reply to Sakura (zundamon) with a
    spoken notice on the first switched sentence. Characters are counted per
    vendor and the Sakura share is recorded as a separate usage row; chat logs
    keep tts_fallback. App tts events carry fallback: "sakura".
    - Backchannel Lambdas: immediate Sakura fallback, no retry.
    - Read-aloud Lambda: Sakura fallback with X-TTS-Fallback header; cost is
    recorded for the voice actually used.
    - Spec: docs/tts-fallback-and-notifications.md (linked from CLAUDE.md).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
2026-09-13 Make Lambda deploy.sh work on Mac as well as Windows Git Bash
    - Resolve npx/npm from PATH instead of the Windows absolute path
    - Use zip when available, fall back to PowerShell Compress-Archive
    - Add set -euo pipefail to the 3 scripts that lacked it, so a failed
    bundle never deploys a stale zip (observed during the Mac trial)
    - Verified without deploying: ran all 8 scripts with update-function-code
    stubbed and diffed the resulting zips against the production code
    (all 8 identical)
    - Mark the deploy.sh item done in the MacBook handoff
    Claude-Session: https://claude.ai/code/session_01YNaeMpWwr7XJX1hTZD4qYk
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2026-10-25 security: 全テーブルにPITR、Lambda依存の脆弱性修正、CloudTrail組織トレイルのスタックを追加
    - DynamoDB 8テーブルに pointInTimeRecoverySpecification を有効化（RnDへ2026-10-25 deploy済み）
    - ESP32本文・ESP32相槌・デバイス設定Lambdaの依存を npm audit fix（undici、fast-xml-parser。package.json範囲内）
    - 新スタック toytalker-org: CloudTrail組織トレイル toytalker-org とバケット toytalker-cloudtrail-org。
    stages.ts の organizationId がある環境（RnD = 管理アカウント）にだけ合成
    - docs/security-review-2026-10-25.md: 公開入口・資格情報・復旧手段の棚卸しと対策表、SSO切替手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
2026-10-26 fix: SSM鍵の再読み込みを待ってから処理に進む（warmup pingごとの load failed を解消）
    - backend/shared/secrets.mjs: 5分経過後の再読み込みを await し、SSMクライアントに接続2秒・応答3秒のタイムアウトを追加
    - 応答を返すと実行が凍結されるため、裏の再読み込みが次の ping で接続エラーになっていた（7日間で1,173件、会話への影響なし）
    - deploy 後の ping 2回でエラーなし（04:16 の ping が 184ms で再読み込み完了）
    - docs: 8(a) deploy 済、済みリストに本修正、9 に初回読み込み失敗時の再試行を追加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
2026-10-27 fix: SSM鍵の初回読み込みが失敗していたら会話の前に1回取り直す
    - AWS が容器を先に初期化して凍結したとき、初期化中に始めた取得が切れることがある（修正後に1件観測、会話への影響なし）
    - ensureSecrets で待った後も未取得なら refresh を1回だけやり直す
    - docs: ロードマップ9の項目を済みへ
    Claude-Session: https://claude.ai/code/session_01JyE9jvM9jLiznQjFaUBe7j
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2026-10-27 llm: Gemini 3.5 Flash Lite と Claude Haiku 5.5 を追加し、Gemini のトークン過大計上を修正
    - 本文Lambda2本: Gemini 3系へ thinkingLevel:minimal（3系は thinkingBudget が400）、App側の2.5 Flashも思考オフに
    - Anthropic: Claude 4.6以降は temperature を外して effort:low、拒否応答時は一言返す
    - 単価はモデル別の行（provider#llm#model）を優先し、無ければプロバイダー行
    - Gemini ストリーミングの usageMetadata は累計値なので要求ごとに最後の値を採る
    - infra: BRAVE_API_KEY を任意の鍵として登録（Serper→Brave 切替の検証用）
    - DynamoDB: toytalker-llms に2行、api-unit-prices に an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
2026-10-27 llm: LLM呼び出しと検索ツールを backend/shared/llm.mjs に共通化し、検索を3社すべてで有効にする
    - 本文Lambda2つ（App / ESP32）から各社の呼び出し・Gemini変換・Serper検索・ツール往復を外し、
    chatStream() / toolRoundMessages() / searchWeb() を使う（各約250行減）
    - 検索ツールを OpenAI / Anthropic にも渡す。プロンプトの「検索できます」と実際のツール付与を同じ条件に
    （Haiku がツール無しで <web_search> を文字で書いていた不具合の修正）
    - Gemini 3系: functionCall の thoughtSignature を往復で返す。2回目の要求は toolChoice "none" で答えさせる
    - 手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
2026-10-28 app: npm audit fix で依存を更新し、expo-router 5.1 が暗黙に使う query-string を明示する
    警告のあるモジュールは 46→26 種類（critical 3→1）。@react-navigation/core 7.24 で query-string が
    消え、expo-router 5.1 の getPathFromState が解決できず起動に失敗したため、query-string@^7.1.3 を
    依存に足した（Expo を上げたら外す）。package.json の他の依存は変えていない。
    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
2026-10-28 infra: aws-cdk-lib 2.275.0 / aws-cdk 2.1146.1 に更新（同梱の brace-expansion の警告を解消）
    brace-expansion は aws-cdk-lib に同梱されているため npm audit fix では直らない。更新後に
    cdk synth（nag）指摘ゼロ、cdk diff 差分なし。デプロイは不要。
    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
2026-10-28 app/ESP32: Soniox一時キーを期限前に取り直す（起動時の1回だけだったので、時間が経つと期限切れのキーで会話が始まらなかった）
    - アプリ: キーを値と取得時刻で持ち、画面表示時・前面復帰時・WSを開く直前に、取得から一定分数を越えていれば取り直す（WS接続と並行。同時呼び出しは1回にまとめる）
    - ESP32: 再生中の先行接続ワーカー（Core 0）に Prepare を足し、WSを開く前に古ければ Lambda から取り直す。先行接続が無い回は録音開始前に loop() で取り直す。取り直しは device_id 等を付けない軽いGET。Soniox の error_code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
2026-10-29 固定ドメイン api-rnd.zakicorp.com（CloudFront + OAC）を RnD に入れ、アプリ・ESP32 の接続先を切り替える（ロードマップ3）
    - CDK: us-east-1 の edge スタック（ACM 証明書。WAF は本番だけ）と、本体スタックの CloudFront ディストリビューション。
    Function URL 7本を1ドメインの経路（/chat-app /chat-mcu /backchannel-app /backchannel-mcu /stt-token /read-aloud-app、
    それ以外は設定Lambda）に束ね、OAC で署名して渡す。Function URL は旧クライアントが残る間 NONE のまま
    （stages.ts の directFunctionUrls。false で AWS_IAM）。cdk-nag 指摘ゼロ、既存資源に Replace なし
    - Lam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
2026-10-29 アプリ: 本文ハッシュを expo-crypto から純JSの SHA-256（app/lib/sha256.ts）へ。ネイティブ再ビルド不要にする
    expo-crypto は開発クライアントに入っておらず起動できなかった（Unable to resolve module）。
    ネイティブモジュールを増やすと開発・配布ビルドの作り直しが要り OTA でも配れないので、
    純JS実装にして依存を外した。node:crypto と9件（空・ASCII・日本語・絵文字・パディング境界・JSON）で一致を確認。
    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
2026-10-29 認証: 端末の ID とアカウントの ID を別にする（初回ログインで新しい owner_id を発行、端末の仮の ID は触らない）
    - backend/shared/auth.mjs: resolveOwner はクライアントが名乗る owner_id を使わず常に新規発行
    - アプリ: ログイン中は /me のアカウント ID、ログアウト中は端末の ID を useOwnerId が使い分ける。端末の ID を上書きしない
    - RnD へ deploy し curl で確認（2026-10-30）。docs/auth.md 更新
    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
2026-10-31 infra: バックアップの異常をメールで知らせる（ロードマップ12）
    計画・選択は Vault Lock の外で消せるので、35日以内に気づけるようにする。
    月次レポートと同じ SNS トピックへ:
    - EventBridge ルール5本: ジョブの失敗・中止・期限切れ、復元の失敗、計画・保管庫の変更と削除、
    計画・選択・保管庫・復旧点を消す/変える API 呼び出し（CloudTrail 経由）、通知のルール・アラームを消す/止める API 呼び出し
    - アラーム toytalker-backup-missing-<環境>: 保管庫の完了ジョブが30時間0件
    RnD へ deploy 済（2026-10-31）。ルール5本 ENABLED、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
2026-10-31 fix(tts): 記号だけの文（「……！」など）を単独で合成せず次の文へ繰り越す
    Cartesia は読める文字が無い文を受けると30秒黙ってから500を返し、再試行込みで約90秒止まっていた（2026-10-31再現）。
    本文Lambda 2本の emitSegment で次の文の頭に付けて送り、返答の最後なら捨てる。
    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
2026-11-01 fix(usage): 利用額の日付を日本時間で区切る
    - usage の日付（App・ESP32・読み上げ）を JST に（backend/shared/jst.mjs）。為替の月は UTC のまま
    - 日次詳細は JST の1日を UTC の範囲にして chat-logs と台帳から引く（listLedgerBetween）
    - アプリの「今月」も JST で決める
    - 文書: 日付の区切りと、財布が1人に2つある件（段階2の前に直す）を 11.6・11.7 に記録
    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
2026-11-07 fix(secrets): SSM鍵の5分ごとの読み直しを廃止し、容器の初期化時に1回だけ読む
    - 5分ごとの読み直しは SecureString 1件の復号ごとに KMS Decrypt を1回呼び、温めping経由で毎時236回・月17万回になり KMS 無料枠（月2万回）を超えていた
    - 温めがあっても容器は AWS が約2時間で入れ替える（7日のログストリームで最長2.4時間）ので、鍵を入れ替えれば数時間で全容器に行き渡る。急ぐなら deploy か設定変更で容器を入れ替える
    - 初回失敗時に1回取り直す仕組みと、取得を待ってから処理に進む方針（2026-10-26）は維持
    - 鍵の入れ替え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
2026-11-08 fix(app): 再生の見張りと、前のターンの結果（prev_turn）をログに載せる
    2026-11-07 15:01 の無反応（サーバーは返答を送り終えていたが、アプリは相槌も返答も鳴らさず、
    文字も出ず、マイクも再開しなかった）の痛み止めと切り分け。
    - chat.tsx の playLoop に見張りを付ける。音声の読み込みが5秒、再生が「長さ+3秒」で
    コールバックが戻らなければ、その文の文字だけ出して次へ進む。正常時は何もしない。
    実機では、ボイス作成中に再生終了のコールバックが戻らないケースを見張りが拾った。
    - 次の本文要求に prev_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
2026-11-08 fix(billing): オートチャージの条件を「額 ≥ 条件」に緩め、設定の誤りをフォームのそばに出す
    - 買い足した直後の残高は条件以上になるので 500円/500円 でも連続請求にならない。既定値がそのままでは通らなかった
    - 購入ページのエラーは出た場所へスクロールし、設定の検査はフォーム内に出す
    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
2026-11-08 fix(app): マイクの持ち主を1つにして、会話の発話待ち中のボイス登録を壊さない
    録音器（react-native-audio-record）はアプリ全体で1つのネイティブ・シングルトンだが、
    会話画面とボイス登録画面が別々に init / start / stop していた。会話の発話待ち（録音中）のまま
    設定タブでボイス登録の録音を始めると、録音器を2か所から取り合い、iOS では AudioQueue が
    2本同時に動いて同じファイルへ書き、候補を選ぶ画面の ▶ を押しても何も鳴らなかった。
    - lib/micOwner.ts を新設。録音を始める側が acquireMic() で持ち主になり、先に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
2026-11-08 fix(app): Soniox STT の開始処理を同期的な印で二重起動させない
    多重起動防止の印（sonioxListeningRef）は録音器の start が終わってから立つため、その数ミリ秒の間に
    2回目の開始が通っていた（2026-11-08 の Metro ログで 9ms 間隔の二重起動を確認）。iOS 側の
    react-native-audio-record は start のたびに新しい AudioQueue を作って前のものを破棄しないので、
    二重起動で録音キューが1本宙に浮き、受け手のいない録音データが流れ続けていた。
    開始処理の先頭で sttStartingRef を同期的に立て、終わりに finally で下ろす。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
2026-11-08 fix(stt-token): 鍵発行のたびに devices.last_seen を更新し、本体が最後に動いた時刻にする
    旧ファーム（fw 報告なし）も対象。これまでは機器設定 Lambda しか書いておらず、最後にアプリで設定を触った時刻になっていた。
    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
2026-11-08 fix(infra): SES の SMTP 用ユーザーの資源を識別子全部にする（sandbox では受信者の識別子も要る）
    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
2026-11-08 fix(infra): cdk-nag の抑止 ID をリージョンと口座の実値にする
    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
2026-11-08 fix(app): 会話中は録音器を止めず、背面でも返答を鳴らす（ロードマップ26）
    iOS は背面のアプリが音声を止めたりカテゴリを切り替えたりした後に鳴らし始めることを拒む。
    毎ターン録音を止めて Record → Playback に切り替えていたため、背面では再生が始まらなかった。
    - 録音ライブラリのパッチを差し替え: 録音停止時の setActive:NO をやめ、録音開始時のカテゴリを
    PlayAndRecord + DefaultToSpeaker + AllowBluetoothA2DP にする（EAS 再ビルドが要る）
    - 会話中は録音器を動かし続け、ターンの区切りでは data の購読を外すだけにす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
2026-11-08 fix(pcb): v0.3 マイクのパッド位置を 0.261mm ポート側へ（データシートの 1.513 はパッドの縁まで）
    Knowles の図の 1.513 をパッド中心までと読んでいたが、パッドの縁までの寸法
    だった（中心なら上段パッドが本体からはみ出す）。JLCPCB（EasyEDA）の
    C22376158 のフットプリントと照合して一致を確認。DATA・+3V3・CLOCK・GND の
    配線の先端とGNDビアを追従。DRC は修正前と同一（20 件、未接続 0）。
    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
2026-11-08 fix(pcb): v0.3 のマイク穴を Ø0.65 に、U1 放熱ビアを穴 0.3/ランド 0.5 に
    - マイクのポート穴 0.5 → 0.65（Knowles 推奨 0.6〜1.0 の範囲内、JLCPCB の
    フットプリントと同じ）
    - BQ25185 の放熱パッド下のビア 2 個 0.2/0.4 → 0.3/0.5（JLCPCB の小穴の
    追加料金の条件を外す。基板上の穴はすべて 0.3mm 以上に）
    - DRC 19 件（U1 のライブラリ不一致が消えた以外は同じ）、未接続 0
    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
2026-11-08 fix(esp32): publish-firmware.sh がビルド失敗を握りつぶして古い .bin を発行する穴を塞ぐ
    arduino-cli が PATH に無いと `| grep ... || true` で失敗が消え、前回の .bin を
    0.7.7 の名前で発行した（2026-11-08、--force で正しいビルドに差し替え済み）。
    arduino-cli の有無を先に確かめ、古い .bin を消してから建て、失敗したら止める。
    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
2026-11-08 fix(esp32): publish-firmware.sh で .bin の中身が発行する版かを確かめる
    .bin に残る `"fw":"<版>"` を探し、無ければ発行しない。--no-build や
    別の経路で古い .bin が混ざっても止まる。
    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
2026-11-08 fix(pcb): v0.3 の S1 の V_SYS と GND の配線をまっすぐにする（手作業）
    S1 パッド 2 → V_SYS を直線に、GND ビアをパッド 1 の真下へ。
    DRC は変更前と同一（19 件、未接続 0）。製造ファイルを出し直した。
    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
2026-11-08 fix(pcb): v0.3 マイク GND のビアをパッドから 0.25mm 離す（パッドに重なっていた）
    ビア (24.85, 29.322) → (24.4, 29.322)。同じネットなので DRC には出ないが、
    パッドの端に穴がかかるとリフローではんだが穴へ吸われるので離した。
    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
2026-11-08 fix(pcb): JLCPCB の配置プレビューのずれと向き違いを根治（FT Position/Rotation Offset）
    EasyEDA のフットプリントとパッド座標を重ね合わせ、JLC の原点と向きに合う
    補正値を 7 部品に入れた: J1/MK1/S1/U3 は位置、U1/U2/U4 は回転。
    positions.csv はその 7 行だけ変化。BOM・ガーバーは変化なし。
    求め方は docs/mcu.md に記録。
    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
2026-11-08 fix(esp32): 本体側の計測の数え方を3つ直す（0.7.8）
    - 受信を終えた後の出し切り中に割り込まれたときも unplayed_ms を数える
    - <end> と同じメッセージの確定を「文字が変わった」に数えない（last_text_to_end_ms がいつも 0 付近だった）
    - 先行接続のために自分で切った Soniox の接続を stt.disconnects に数えない
    会話・再生・割り込みの動きは変えない。
    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
2026-11-10 fix(search): 検索で「調べるね」を2回言う・言うだけで止まるのを直す（ロードマップ30）
    - 検索結果の後の返答の1文目が「これから調べる」文なら読み上げずに捨てる（isSearchPreface）
    - 「探してみるね。待っててね。」だけで検索を呼ばずに終わったら、検索を必ず呼ばせてもう1回頼む
    （isSearchPromiseOnly、toolChoice "required"。Gemini ANY / OpenAI required / Anthropic any）
    - 検索結果を渡した要求でまた検索を求めたら、結果を普通の文章に直してツール無しでもう1回頼む
    （inlineLastToolRound。以前はそこで打ち切って本文が空にな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
2026-11-11 fix(wallet): 台帳の数値が { value: "…" } で返り、アプリの利用状況の詳細が落ちるのを直す
    wallet.mjs は1つの DynamoDBClient から DocumentClient を2つ作っていた。
    DynamoDBDocumentClient.from は渡したクライアントの config に変換の設定を書き込むので、
    後から作った ddbExact（wrapNumbers）の設定が普通の ddb にもかかり、
    listLedgerBetween が数値を NumberValue のまま返していた（2026-11-08 の 7f289df から）。
    GET /usage/detail の金額・文字数・トークン数がオブジェクトになり、
    アプリが <Text> に描こうとして例外で終了していた。
    ddbExact に専用のク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
2026-11-11 feat(app): 描画の例外でアプリを終了させない（エラー画面と、利用状況の応答を受け取り口で揃える）
    サーバーの1行の間違いでアプリごと落ちたので、アプリ側の守りを足す。次のビルドから効く。
    - components/ScreenError.tsx: Expo Router の ErrorBoundary。3つのタブ画面と app/_layout.tsx から export し、
    描画で例外が出たらその画面だけ「この画面を表示できませんでした」にする（今まで受け止める仕組みが無かった）
    - lib/usage.ts: GET /usage と GET /usage/detail の応答を、数値・文字列・null に揃えてから画面へ渡す
    型チェックと、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
2026-11-11 fix(esp32,ota): 3回で諦めず、ロールバックした版だけ試さない（0.7.12）
    ダウンロードの失敗（電源断・通信・SHA不一致）とロールバックを同じ回数で数えて
    3回で諦めていたため、偶然の失敗が続くとその版が二度と来なかった。
    ロールバックした版だけを以後試さず、ダウンロードの失敗は続けて3回で
    5回の起動に1回へ間を空けて試し続ける。前回の結果を鍵取得の要求に添え、
    Soniox 鍵 Lambda の1行ログ（ota_last / ota_fails / ota_bad）に出す。
    Claude-Session: https://claude.ai/code/session_01LC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
2026-11-11 fix(esp32,ota): 更新の成功を有効印の時に判定する（0.7.17）
    0.7.12 は起動の最初（setup）で「入れた版が動いている＝成功」とみなして記録を消していた。
    有効印の前に落ちる版もその時点では動いているため、戻った後にロールバックと分からず、
    入れ直しを永久に繰り返した（2026-11-11、試験版 0.7.16 で再現）。起動の最初では
    ロールバックだけを判定し、成功は confirmRunningImage() で有効印を付けた後に判定する。
    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
2026-11-12 fix(wallet): 台帳に書けず残高から引かれない2つの漏れを直し、書けなかったら知らせる
    - 同じ財布への書き込みが重なると DynamoDB がトランザクションを取り消す（TransactionConflict）。
    取り消されたら間をあけて6回までやり直す。RnD の再現試験（同時50件）で 38 件落ち → 0 件。
    負荷試験で抜けた35件の原因はキーの衝突ではなくこれだった（docs を訂正）
    - 読み上げ Lambda は記録を待たずに応答を閉じていて、Lambda が止まると書き込みが消えた。
    書き終わるのを待ってから閉じる
    - 書けなかった consume はログに理由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
2026-11-13 fix(infra): 運用トピックへ CloudWatch のアラームが Publish できるようにする
    トピックポリシーを自分で付けていたため既定の許可が無く、警報7本の通知が
    「not authorized to perform SNS:Publish」で失敗していた（2026-11-13、OTA の警報の実機確認で発見）。
    deploy 済み。手動で鳴らしてメールが届くことを確認。
    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
2026-11-13 fix(esp32): 0.7.24 話し終わりの猶予が周りの音で延びないよう、声とみなす音量を上げる
    - STT_GRACE_SPEECH_RMS 1200 → 2500、STT_GRACE_RESUME_MAX_MS 3 秒 → 2 秒
    - 2026-11-13 の実測（猶予の遅れ、割り込みが判定の休みに当たると通らない）を入口文書に
    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
2026-11-13 fix(llm): 検索前の「調べるね」を検索ツールの引数 say にする
    「調べるね」と言っただけで終わる、言って調べずに答える（作り話の疑い）、
    検索後にもう一度「待ってね」と言う、が 2 問目以降で出ていた（2026-11-13、ESP32）。
    文字列の判定を足すのをやめ、一言を検索の呼び出しの中に入れた。
    - WEB_SEARCH_TOOL に say を足し、プロンプトの「一言を添えて」を消した
    - 本文 Lambda 2 本は say を鳴らしながら同時に検索する
    - Gemini は functionCallingConfig.mode を VALIDATED にする（say を足すと引数の形が崩れるため）
    - 崩れた引数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
2026-11-13 fix(esp32): 0.7.25 EQ を既定でなしにする（3kHz の持ち上げで再生中にシャラシャラした音が乗った）
    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
2026-11-14 fix(app): ボイスキーホルダーの入力欄がキーボードに隠れないようにする
    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
2026-11-14 fix(esp32): flash-published.sh が Mac の bash 3.2 で照合の後に止まるのを直す（変数の直後の全角カッコを波カッコで区切る）
    Mac 標準の bash 3.2 は $VERSION（ の全角文字の1バイト目を変数名の一部として読み、
    unbound variable で止まる。表示の2行だけで、照合と書き込みの処理は変えていない。
    Mac から予備機へ 0.7.34 を書いて確認（2026-11-14）。
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
